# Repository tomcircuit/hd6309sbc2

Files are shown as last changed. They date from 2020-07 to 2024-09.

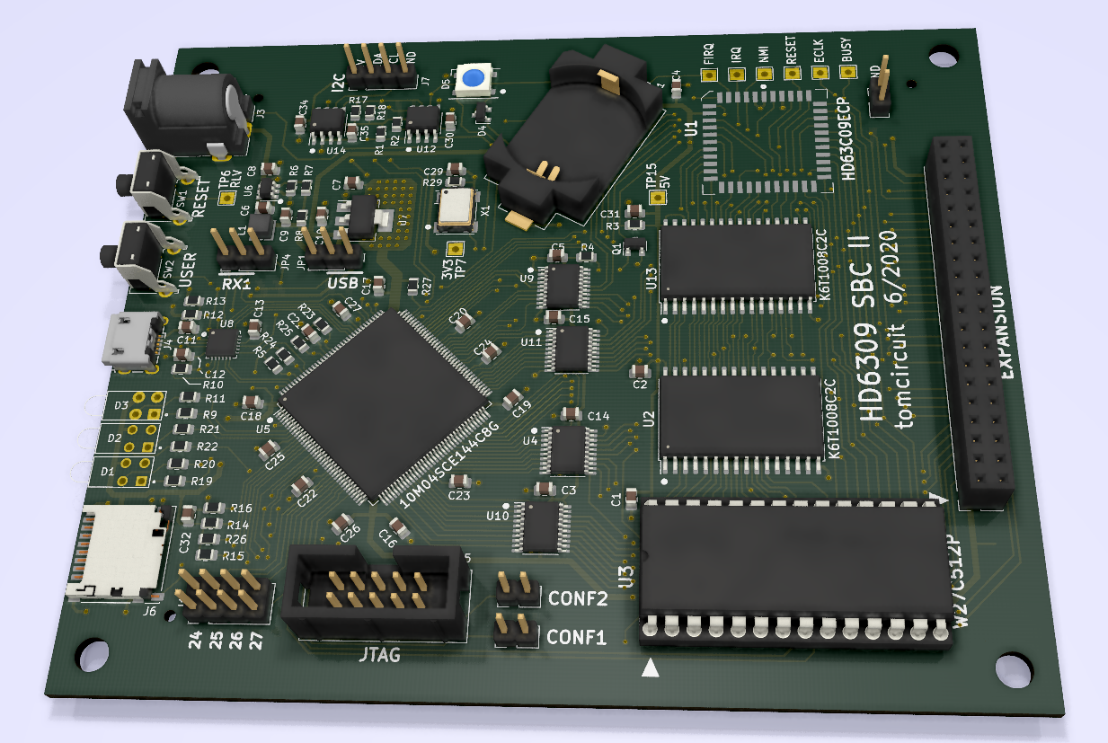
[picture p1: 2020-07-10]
media/pcb_3d_render_rt.PNG

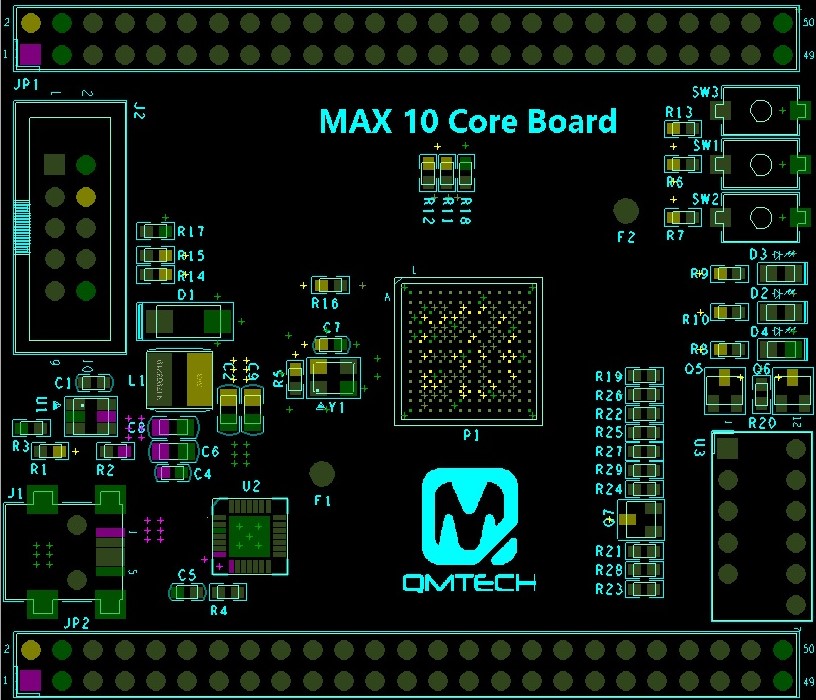
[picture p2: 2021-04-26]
reference/coreboard_cropped.jpg

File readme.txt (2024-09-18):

This information pertains to the HD6309 Singleboard Computer v2.0

The HD6309 SBC II is a retroputing distraction, motivated by the fun I had designing
and using my first HD6309 SBC project. This time around, I favored 'all mod cons' over
'old skool'. In contrast to the v1.0, this version loses the Zilog SCC and Zilog CIO
devices, expands RAM to 16MB and addressable ROM to 64K. The SD card interface is
retained, as is the more up-to-date I2C realtime clock. The heart of this SBC is an
Altera Cyclone IV FPGA, in which all of the glue logic and peripherals are implemented.
So, with vastly more logic capacity, easy to do UARTs, the SPI master, a more friendly
I2C master, a paged memory mapper, and whatever else springs to mind...  The 
'penalty' for this luxury is that of mixed voltage design - the CPU and clock signals 
are in a 5V domain, everything else is in the 3.3V domain. A 5V DC/DC supplies the
CPU. Four octal transceivers shift the TTL signalling to LV-TTL. Sure, I could have 
put the CPU core in the FPGA, but no CPU just seems a bit like 'cheating'.
LOL, to each their own :-)  The SBC v2 is also physically smaller than its v1.0 
predecessor; measures 100 x 120mm.

I devised a stacking 64-pin connector scheme so that the FPGA board, the CPU board,
and an I/O board can all be used together. I have also spec'd out a 65C816 CPU board,
and a MC68HC000 board.

Firmware wise, I'll keep the rudimentary monitor, NoICE support, and the ROM-resident 
6809 MICROSOFT BASIC interpreter which I implemented on v1.0 (the latter is courtesty 
of Grant Searle). 

More up-to-date information on the SBC can be found on the Hackaday project page:
https://hackaday.io/project/173401-hd6309-singleboard-computer-ii

This work is licensed under the Creative Commons Attribution-ShareAlike 4.0 International License. 
To view a copy of this license, visit http://creativecommons.org/licenses/by-sa/4.0/.

HD6309 Singleboard Computer II
Tom LeMense
9/17/2024

tomcircuit@gmail.com
@TomLeMense

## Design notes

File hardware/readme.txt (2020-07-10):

This set of design files implements the Schematic and PCB for the HD6309 Singleboard Computer II

Design tool is KiCad 5.1.6

PCB was designed with one-off production in mind, and to my own set of (largely unwritten) PCB
design rules. The board is double sided 100 x 120mm, with 8/8 track/spacing (mils), and 0.4mm minimum
hole size. The two most complicated components to solder are the EQPF144 MAX10 CPLD and the QFN28
CP2105 USB bridge. The rest of the components are fairly straightforward to assemble.

PDF of the PCB and Schematic can be found in the "plots" directory.
Gerber and drill information can be found in the "fabrication" directory.

My PCBs were fabricated by PCBway https://www.pcbway.com/ and I chose 1.6mm FR4 with ENIG surface 
treatment to make fine-pitch SMD soldering easier. I had a polyamide stencil manufactured by OSHstencils
https://www.oshstencils.com/. This will be my first foray with solder stencil, hotplate, and hot air
soldering. It's long overdue, because so many components simply cannot be reliably hand-soldered anymore.

More up-to-date information on the SBC can be found on the Hackaday project page:
https://hackaday.io/project/173401-hd6309-singleboard-computer-ii

This work is licensed under the Creative Commons Attribution-ShareAlike 4.0 International License. 
To view a copy of this license, visit http://creativecommons.org/licenses/by-sa/4.0/.

HD6309 Singleboard Computer II
Tom LeMense
7/8/2020

tomcircuit@gmail.com
@TomLeMense

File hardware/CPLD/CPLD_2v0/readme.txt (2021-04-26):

This set of design files implements the glue logic for the HD6309 Singleboard Computer 

CPLD VERSION v1.4

Target device is Altera EPM7128SLI in 84 pin PLCC
Development tool is Altera Quartus web edition v11

As present, all planned functions have been implemented:

. E & Q clock generation with 0WS, 1WS, and 3WS as necessary
. programmable 0WS/1WS for ROM area access
	---> note; 1WS is nasty, because this will slow down all the 6309 "idle" cycles, also!
		The power-on default is 1WS, in order to support slower EPROM devices at boot.
		
. SCC Ch A and Ch B baudrate clocks generated from 14.745 MHz oscillator
		
. Hardware SPI master* for SD card access

. [new 1.3] SPI clocks (fast and slow) derived only from 24 MHz oscillator

. [new 1.3] moved IO page to $E000-E1FF:
            $E000=CIO, $E010=SCC, $E020=RTC, $E030=SD_DATA, $E040=SYS, $E050=CFG, $E060=VER
		  $E070-$E1FF are undecoded space (for use by expansion card devices, for example)

. [new 1.3] selectable EPROM 27C128/27C256 support (pin 27 defaults to state of CONFIG jumper at RESET)

. [new 1.3] CPLD version "register" at $E060 - returns $13

. [new 1.3] removed test mux for TP11,12,13,14 pins - these are now fixed to echo SD card signals

. [new 1.4] removed RTC decode

. [new 1.4] implemented software I2C port at $E020, I2C SCK on pin 11 (new), I2C SDA on pin 12 (was RTCCS)

*Note that the hardware SPI was something that I found while casting about on the intarwebs.  
SimpleSPI_M.vhd is copyright 2007 by Tom Scott, of Mission Technologies
http://www.mission-technologies.org/read_article.php?subject=VHDL&id=14
It works well, and so I was happy to include it, with relatively minor changes, into my project.

More up-to-date information on the SBC can be found on the Hackaday project page:
https://hackaday.io/project/345-hd6309-singleboard-computer

This work is licensed under the Creative Commons Attribution-ShareAlike 4.0 International License. 
To view a copy of this license, visit http://creativecommons.org/licenses/by-sa/4.0/.

HD6309 Singleboard Computer (SBC)
Tom LeMense
1/28/2020

tomcircuit@gmail.com
@TomLeMense

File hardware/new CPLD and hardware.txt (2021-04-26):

HD6309 SBC Revision 2
---------------------

HD63C09E PLCC44
W27C512 64Kx8 FLASH  DIP28
K6T1008 128Kx8 SRAM (replace 2x 32Kx8 SRAM)  SOT32
CP2105 USB Bridge (replace FT230XS bridge)  QFN24
DS3231M (replace RTC7301 and DS3232M RTC retrofit)  SO8
add 24C64 EEPROM (on I2C chain)   SO8
6x LED (CHAtog, CHA/CHBtog)  PTH dual LED
WS2812B RGB LED   4-pin 5x5mm
CONF1 & 2 jumpers   2.54mm 1x2 header
write to VERSION SFR causes system reset
add 5V switching regulator  TPS560430  SOT23-6
replace PJRC SD card adapter with built-in SD card socket
replace USB B socket with USB MICRO B socket
replace MAX7000 with MAX10  (10M08SCC144)
remove X2 oscillator
remove CIO and SCC
5V domain for CPU, RAM, ROM
3.3V domain for MAX10, I2C, SD card 
AP1117-3.3 LDO for 3.3V rail
74LVC245 for 5V->3.3V level shifter

SN74LVC245APW (mouser 595-SN74LVC245APWR)
0.65mm pitch TSSOP-20 package

TPS560430 is a nice synchronous buck  (mouser 595-TPS560430YFDBVR)
10uH 1A RMS 1.8A sat current (2.1 MHz)  (mouser 810-VLS3012HBX-100M)
10uF/10V ceramic cap  (mouser 810-C2012X7R1A106KAE)
2.2uF/50V input cap (mouser 963-UMK212BB7225MG-T)
0.1uF/50V bootstrap cap (mouser 581-08055C104KAT4A)
R-divider

CP2105 USB-UART Bridge (mouser 634-CP2105-F01-GMR)
  The TXD toggle lights when a character is received from USB
  Test with CP2108 shows that RTS and CTS are able to be controlled by NoICE
  Note: RTS and DTR invert - from NoICE "RTS 1" drives the output LOW, and "RTS 0" drives the output HIGH.
DS3231M I2C Realtime Clock  (mouser 700-DS3231MZ/V+)
SD Card holder (mouser 798-DM3D-SF)

ROMA15 is HIGH at RESET (0x8000-0xFFFF ROM physical addr)
ROMA14 follows CONF at RESET (0x8000-0xBFFF or 0xC000-0xFFFF ROM physical addr)
RAMA13,14,15 follow A13,14,15 at RESET (no mapping)
RAMA16 is LOW at RESET (0x00000 - 0x0FFFF RAM physical addr)

MAX10 CPLD to support:

Clock generation (E,Q)
    with some ability to try to overclock the CPU?
    
Paged memory mapping of 256K RAM, 64K ROM
    8K x 32 pages of SRAM (p0-p31)
    8K x 8 pages of ROM (p32-p39)
    7b x 8 register file (6 bits page select, 1 bit write protect)    
    each 8K region of CPU space is mapped to p0-p39
        default: 
        R0=P8, R1=P9, R2,3,4,5=P10,11,12,13
        R6=P36/38, R7=P37/39 (depending on CONF1 jumper)
        
IO register  (SYSIO)
    4b LED3-6 control
    2b conf1, conf2
    1b pushbutton (debounced)
    
IRQ control / status  
    8b IRQ flag register (INTF)
        U1 TXRE request
        U1 RXF request
        U2 TXRE request
        U2 RXF request
		pushbutton request

    8b IRQ mask register (INTM)
        U1 TXRE mask
        U1 RXF mask
        U2 TXRE mask
        U2 RXF mask
        pushbutton mask
        
Two UARTs (one console, one NoICE)
    56,115,230,460kbps bitrates (with a VCP, does this really need to be the weird values?)
    each UART has 6b status/control register  (UxSCR)
    (2 bits baud select, 1 bit TX empty, 1 bit RX full, RTS status)
    each UART has 8b data register  (UxDATA)
    (send transmit data on write; received data on read)    
    
I2C master for RTC and EEPROM
    8b status/control register  (IICSCR)
    2 bit command field
    IDLE, MASTER, BYTE, and STOP commands
    2 bit SCL and SDA drive
    1 bit SDA level
    1 bit ACK send
    1 bit ACK receive
    1 bit I2C busy
    8b data register  (IICDATA)
    (send transmit data on write; received data on read)    
    
SPI master for SD Card
    8b status/control register   (SPISCR)
    1b clock select (fast/slow)
    1b SD switch input
    1b SD select output
    1b SPI busy
    1b WS control (to slow down E clock so that 6309 block move instruction can be used)
    8b data register  (SPIDATA)
    (send transmit data on write; received data on read)    
    
WS2812B interface
    R,G,B registers  (PIXR, PIXG, PIXB)
    
reset control  (RESCON)
    RTS1 reset   (00=RTS1 ignored; 01=RESET when RTS1 goes L, 10=when RTS1 goes H, 11=change of RTS1 state)
    RTS2 reset   (00=RTS2 ignored; 01=RESET when RTS1 goes L, 10=when RTS1 goes H, 11=change of RTS1 state)
    software reset  (1=RESET CPU)
    watchdog reset  (1=enable wdog; write to CPLD ID register to service watchdog)
    RTC select (0=perform RESET on RTC reset; 1=perform NMI on RTC reset)
    USER NMI enable (0=ignore USER button; 1=perform NMI on USER button)

$E004 - INTF
$E005 - INTM

$E010 - U2SCR
$E011 - U2DATA
$E012 - U1SCR
$E013 - U2DATA

$E020 - IICSCR
$E021 - IICDATA	

START:
         I2C_ReleaseBoth                            ; release SDA and SCL
         I2C_BitDelay                               ; allow SDA to float high
         I2C_SinkSDA                                ; begin I2C START by bringing SDA low first
         I2C_BitDelay                               ; half-bit delay
         I2C_SinkSCL                                ; complete I2C START by bringing SCL low
         I2C_BitDelay                               ; half-bit delay         

WRITE: 
"GO Master" 
    Start   ; I2C START is bringing SDA low first, then bit delay, then bring SCL low
    SendByte  ; byte is 8 bits from DATA_SEND, updating DATA_RCV, followed by sending ACK_SEND bit / updating ACK_RCV bit
"Send Byte"  ; byte is 8 bits from DATA_SEND, updating DATA_RCV, followed by sending ACK_SEND bit / updating ACK_RCV bit
"Send Byte"   ; byte is 8 bits from DATA_SEND, updating DATA_RCV, followed by sending ACK_SEND bit / updating ACK_RCV bit
"Send Stop" ; SCL high followed by SDA high is STOP condition

READ:
"GO Master" 
    Start   ; I2C START is bringing SDA low first, then bit delay, then bring SCL low
    SendByte  ; byte is 8 bits from DATA_SEND, updating DATA_RCV, followed by sending ACK_SEND bit / updating ACK_RCV bit
"Send Byte" ; byte is 8 bits from DATA_SEND, updating DATA_RCV, followed by sending ACK_SEND bit / updating ACK_RCV bit
"GO Master" 
    Start   ; I2C START is bringing SDA low first, then bit delay, then bring SCL low
    SendByte  ; byte is 8 bits from DATA_SEND, updating DATA_RCV, followed by sending ACK_SEND bit / updating ACK_RCV bit
"Rcv Byte"  ; byte is 8 bits from DATA_SEND, updating DATA_RCV, followed by sending ACK_SEND bit / updating ACK_RCV bit
"Send Stop"

"COMMAND" bits
00 = IDLE (no action when DATA_TX is written)
01 = BYTE (send DATA_SEND while updating DATA_RCV, followed by sending ACK_SEND / updating ACK_RCV)
10 = GO_MASTER (send START then fall into BYTE)
11 = STOP (send STOP condition, leaving SCL=SDA=1)

About the MAX 10 CPLD family
All IO pins have selectable pullups
All IO pins have optional open-drain output mode
All IO pins are INPUT until the device is configures

990824

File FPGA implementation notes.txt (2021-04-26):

PH1 minimal testboard setup
clock generation and CPU execution

1x M9K "RAM" at $0000...$03FF
1x M9K "ROM" at $FC00...$FFFF
DONE *address decoder
DONE *clock generator
*LED4 control at $E000
*PB1 status at $E001

1) das blinkenlights in ROM   
   --> exercises clock gen, address decoder, ROM, LED4
2) das blinkenlights that relocates to RAM
   --> exercises clock gen, address decoder, ROM, RAM, LED4

PH1.5 minimal testboard setup
clock generation and CPU execution

ACIA clock
ACIA 6850
PLL for ACIA
1x M9K "RAM" at $0000...$03FF
1x M9K "ROM" at $FC00...$FFFF
*address decoder
*clock generator
*LED4 control
*PB1 status
 
3) WOZMON in ROM
   --> exercises clock gen, address decoder, ROM, RAM, PLL, baudrate gen, ACIA

PH2 testboard setup       
bring in SRAM and SPI EEPROM

**ACIA_clock
**acia6850
**simple SPI to EEPROM
*PLL & baudrate_gen
4x M9K "ROM" at $F000...$FFFF
*address decoder
*clock generator
*SRAM interface
*LED4 & BUSY control
*PB1 status

1) RAM testing
   --> walking bit pattern through 64K of RAM
2) SPI EEPROM loader to RAM
   --> image of WOZMON in SPI EEPROM, "write protected" ROM
3) MSBASIC test run
   --> image of MSBASIC in SPI EEPROM 

PH3 testboard setup
more functionality and SBC1 compatibility.

**2xACIA_clock
**2xAcia6850
*simple SPI to EEPROM
*simple SPI to SDCARD
*2xTrap component
*Timer component
*PLL & baudrate_gen
4x M9K "ROM" at $F000...$FFFF
*address decoder
*clock generator
*DAT logic
*SRAM interface
*LED4 & BUSY control
*RTS status
*PB1 status
*IRQ control
*NMI control
*RESET control
*WS2812 control
*soft I2C control

1) DAT testing
   --> page testing
2) SPI SD CARD testing
   --> read/write SD card stuff
3) RTC testing
4) RGB LED testing
5) TRAP testing
6) TIMER testing
7) RESET and NMI testing
8) RTS testing
9) NoICE testing?

0xE000          [new]system timer preload/count  (use a 12b counter, only deal with upper 8 bits)
W = load preset count register
R = read down counter value
0xE001          [new]system timer control/status
bit 7 r/w IRQ
    write a 1 to enable terminal count interrupt, will INT when counter reaches 0
bit 0 r/w RUN
    write a 1 to start the counter, will read 1 as long as counter is running
    
0xE010          6850 A data register
0xE011          6850 A control/status register
0xE012          6850 B data register
0xE013          6850 B control/status register
0xE014          baudrate prescalar control (both A & B)
bit 7..4 n.u.
bit 3:2 r/w BPS
    00 = /1, 01 = /8, 02 = /24 for ACIA B
bit 1:0 r/w APS
    00 = /1, 01 = /8, 02 = /24 for ACIA A
    
0xE02x          Soft I2C register

0xE030          SD Card SPI Read/Write Data (triggers send)
0xE031          SD Card SPI Read Data (no send)
0xE032          SD Card SPI Control 
bit 7 r SDSW 
    sense the SD card present switch (1 = present)
bit 6 r SDBUSY 
    SPI interface is busy when 1
bit 5 r/w SDCLK 
    select CLK for SD CARD SPI (1 = XOSC/2 (25M), 0 = OSC/8 (6M))
bit 4 r/w SDCS 
    control CS line to SD CARD
bit 3..0 n.u.
    
0xE038          EEPROM SPI Read/Write Data (triggers send)
0xE039          EEPROM SPI Read Data (no send)
0xE03A          EEPROM SPI Control
vit 7 n.u.
bit 6 r SDBUSY 
    SPI interface is busy when 1
bit 5 r/w SDCLK 
    select CLK for EEPROM SPI (1 = XOSC/3 (16M), 0 = OSC/8 (6M))
bit 4 r/w SDCS 
    control CS line to EEPROM
bit 3..0 n.u.
    
0xE040          SYSTEM CONFIG register
bit 7 r/w WODAT
    enable WRITES to DAT 0-F registers at $FFF0-$FFFF when ROMSEH=1 (SWTPC compatibility)
bit 6 r/w BOOTROM
    4K of MAX10 UFM ROM is mapped into $F000-$FFFF when 1     
bit 3 r/w ROMBANK
    sets bank mapping of $C000-$FFFF when ROMSEL and/or ROMSEH are set. This takes the value of CONF1 at RESET
bit 2 r/w ROMSEH 
    disables DAT and prevent writes to $E200-$FFFF when 1, SRAM mapping depends on ROMBANK
bit 1 r/w ROMSEL 
    disables DAT and prevent writes to $C000-$DFFF when 1, SRAM mapping depends on ROMBANK
bit 0 n.u.
    
0xE048          NMI & RESET CONTROL register
bit 7 0/w COLD
    reset the CPU and MAX10 
bit 6 0/w WARM
    reset the CPU (but not the MAX10)
bit 5 r/w RTSEN
    enables CPU RESET from RTS when set
bit 4 r/w RTSPOL
    sets polarity of RTS that causes RESET
bit 3 r/w NMIPB
    enable NMI from pushbutton
bit 2..0 n.u.

0xE050          IO CONFIG register
bit 7 r CONF2
    CONF2 jumper status (1 = open, 0 = shorted)
bit 6 r CONF1 
    CONF1 jumper status (1 = open, 0 = shorted)
bit 5..4 n.u.    
bit 3 r PB pushbutton input (1 = pressed)
bit 2 r RTS 
    RTS state from CP2105
bit 1 r/w BUSY
    control BUSY LED #2 (1 = illuminate)
bit 0 r/w LED4
    control LED #4 (1 = illuminate)

0xE058          D4 RED register
0xE059          D4 GREEN register
0xE05A          D4 BLUE register
0xE05B          D5 RED register
0xE05C          D5 GREEN register
0xE05D          D5 BLUE register
0xE05E          D4/D5 update
bit 0 r/w UPDATE
    write 1 to update D4/D5 colors
    read 1 == busy, read 0 == ready

0xE06x          VERSION register
Read returns 0x20 (2.0)

0xE070-0xE07F   DAT A-F registers (read and write access)*
0xE080-0xE087   DAT C0,D0,E0,F0,C1,D1,E1,F1 registers (read and write access)*
*DAT A-F registers can also be WRITTEN via writes to 0xFFF0...0xFFFF when ROMSEH=1 and WODAT=1

0xE090-0xE097   TRAP1 registers
0xE098-0xE09F   TRAP2 registers

RAM and ROM Mapping
reads and writes within CPU 0x0000:DFFF are mapped to SRAM using DAT
(each 4K page has a DAT register, 
                               
    BOOTROM | ROMBANK | ROMSEH | ROMSEL | ADDRESS |    SRAM ADDR SOURCE
   ---------+---------+--------+--------+---------+---------- ----------              
       X    |    X    |    X   |   0    | $Cxxx   | use 'C' DAT                       
            |         |        |        | $Dxxx   | use 'D' DAT                       
       0    |    X    |    0   |   X    | $Exxx   | use 'E' DAT                       
            |         |        |        | $Fxxx   | use 'F' DAT                       
       X    |    0    |    X   |   1    | $Cxxx   | use 'C0' DAT                       
            |         |        |        | $Dxxx   | use 'D0' DAT                       
       0    |    0    |    1   |   X    | $Exxx   | use 'E0' DAT                       
            |         |        |        | $Fxxx   | use 'F0' DAT                       
       X    |    1    |    X   |   1    | $Cxxx   | use 'C1' DAT                       
            |         |        |        | $Dxxx   | use 'D1' DAT                       
       0    |    1    |    1   |   X    | $Exxx   | use 'E1' DAT                       
            |         |        |        | $Fxxx   | use 'F1' DAT                       
       1    |    X    |    X   |   X    | $Fxxx   | MAX10 UFM  
            |         |        |        |                                                               

ROMSEL == 0
reads and writes within CPU 0xC000:DFFF are mapped to SRAM using DAT

ROMSEL == 1
reads within CPU 0xC000:DFFF are mapped via DAT C0 and D0 when ROMBANK == 0 and DAT C1 and D1 when ROMBANK == 1
writes within CPU 0xC000:DFFF are blocked

ROMSEH == 0
reads and writes within CPU 0xE200:FFFF are mapped to SRAM using DAT

ROMSEH == 1
reads within CPU 0xE200:FFFF are mapped via DAT E0 and F0 when ROMBANK == 0 and DAT E1 and F1 when ROMBANK == 1
writes within CPU 0xFFF0:FFFF are mapped corresponding DAT register (0-F) when WODAT == 1, otherwise blocked
writes within CPU 0xE200:FFEF are blocked

BOOTROM
reads within CPU 0xF000:FFFF are mapped to MAX10 internal boot rom image
writes within CPU 0xF000:FFFF are blocked

UARTs

Use two acia6850 from John Kent System09 project.
These are MC6850 and need 16x/64x baud clocks (easy to modify to include 32x baud clock, also)

Need a prescalar (separate from acia6850 core) to provide /8 and /24 clocks, too.

Use a PLL to create the 14.7456MHz clock from the 50MHz xtal
This is nice because the acia6850 component can be used as-is
with the 16x and 64x (and add 32x) internal clock divider settings

	   PLL 		
	   14745600 32	460800
		        16	921600
		        64	230400
                
In addition, create a small PRESCALAR outside of the 6850 component to 
provide PLL/8 and a PLL/24 outputs to each of the two UARTs (independently)
                
    8	1843200	32	57600
        		16	115200
        		64	28800
  24	614400	32	19200
        		16	38400
        		64	9600

TIMER

another John Kent component - make it a longer counter so that we're counting CPU cycles and not 50 MHz cycles!
i.e. make it a 12b counter, only the uppermost 8b are visible to the CPU.

TRAP

another John Kent component - put two of these here for hardware breakpoints to IRQ (NMI?)

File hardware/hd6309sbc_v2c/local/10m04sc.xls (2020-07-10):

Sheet: Pin List E144
Pin Information for the Intel® MAX®10 10M04SC Device Version 2017.12.15 Note (1)
Bank Number | VREF | Pin Name/Function | Optional Function(s) | Configuration Function | Dedicated Tx/Rx Channel | Emulated LVDS Output Channel | IO Performance | E144 (2)
1A | VREFB1N0 | IO |  |  | DIFFIO_RX_L1n | DIFFOUT_L1n | Low_Speed | 6
1A | VREFB1N0 | IO |  |  | DIFFIO_RX_L1p | DIFFOUT_L1p | Low_Speed | 7
1A | VREFB1N0 | IO |  |  | DIFFIO_RX_L3n | DIFFOUT_L3n | Low_Speed | 8
1A | VREFB1N0 | IO |  |  | DIFFIO_RX_L3p | DIFFOUT_L3p | Low_Speed | 10
1A | VREFB1N0 | IO |  |  | DIFFIO_RX_L5n | DIFFOUT_L5n | Low_Speed | 11
1A | VREFB1N0 | IO |  |  | DIFFIO_RX_L5p | DIFFOUT_L5p | Low_Speed | 12
1A | VREFB1N0 | IO |  |  | DIFFIO_RX_L7n | DIFFOUT_L7n | Low_Speed | 13
1A | VREFB1N0 | IO |  |  | DIFFIO_RX_L7p | DIFFOUT_L7p | Low_Speed | 14
1B | VREFB1N0 | IO |  | JTAGEN |  |  |  | 15
1B | VREFB1N0 | IO |  | TMS | DIFFIO_RX_L11n | DIFFOUT_L11n | Low_Speed | 16
1B | VREFB1N0 | IO | VREFB1N0 |  |  |  |  | 17
1B | VREFB1N0 | IO |  | TCK | DIFFIO_RX_L11p | DIFFOUT_L11p | Low_Speed | 18
1B | VREFB1N0 | IO |  | TDI | DIFFIO_RX_L12n | DIFFOUT_L12n | Low_Speed | 19
1B | VREFB1N0 | IO |  | TDO | DIFFIO_RX_L12p | DIFFOUT_L12p | Low_Speed | 20
1B | VREFB1N0 | IO |  |  | DIFFIO_RX_L14n | DIFFOUT_L14n | Low_Speed | 21
1B | VREFB1N0 | IO |  |  | DIFFIO_RX_L14p | DIFFOUT_L14p | Low_Speed | 22
1B | VREFB1N0 | IO |  |  | DIFFIO_RX_L16n | DIFFOUT_L16n | Low_Speed | 24
1B | VREFB1N0 | IO |  |  | DIFFIO_RX_L16p | DIFFOUT_L16p | Low_Speed | 25
2 | VREFB2N0 | IO | CLK0n |  | DIFFIO_RX_L18n | DIFFOUT_L18n | High_Speed | 26
2 | VREFB2N0 | IO | CLK0p |  | DIFFIO_RX_L18p | DIFFOUT_L18p | High_Speed | 27
2 | VREFB2N0 | IO | CLK1n |  | DIFFIO_RX_L20n | DIFFOUT_L20n | High_Speed | 28
2 | VREFB2N0 | IO | CLK1p |  | DIFFIO_RX_L20p | DIFFOUT_L20p | High_Speed | 29
2 | VREFB2N0 | IO | VREFB2N0 |  |  |  |  | 30
2 | VREFB2N0 | IO | PLL_L_CLKOUTn |  | DIFFIO_RX_L27n | DIFFOUT_L27n | High_Speed | 32
2 | VREFB2N0 | IO | PLL_L_CLKOUTp |  | DIFFIO_RX_L27p | DIFFOUT_L27p | High_Speed | 33
3 | VREFB3N0 | IO |  |  | DIFFIO_TX_RX_B1n | DIFFOUT_B1n | High_Speed | 38
3 | VREFB3N0 | IO |  |  | DIFFIO_TX_RX_B1p | DIFFOUT_B1p | High_Speed | 39
3 | VREFB3N0 | IO |  |  | DIFFIO_TX_RX_B3n | DIFFOUT_B3n | High_Speed | 41
3 | VREFB3N0 | IO |  |  | DIFFIO_TX_RX_B3p | DIFFOUT_B3p | High_Speed | 43
3 | VREFB3N0 | IO |  |  | DIFFIO_TX_RX_B5n | DIFFOUT_B5n | High_Speed | 44
3 | VREFB3N0 | IO |  |  | DIFFIO_TX_RX_B5p | DIFFOUT_B5p | High_Speed | 45
3 | VREFB3N0 | IO |  |  | DIFFIO_TX_RX_B7n | DIFFOUT_B7n | High_Speed | 46
3 | VREFB3N0 | IO |  |  | DIFFIO_TX_RX_B7p | DIFFOUT_B7p | High_Speed | 47
3 | VREFB3N0 | IO |  |  | DIFFIO_TX_RX_B9n | DIFFOUT_B9n | High_Speed | 50
3 | VREFB3N0 | IO | VREFB3N0 |  |  |  |  | 48
3 | VREFB3N0 | IO |  |  | DIFFIO_TX_RX_B9p | DIFFOUT_B9p | High_Speed | 52
3 | VREFB3N0 | IO |  |  |  |  |  | 54
3 | VREFB3N0 | IO |  |  | DIFFIO_TX_RX_B12n | DIFFOUT_B12n | High_Speed | 55
3 | VREFB3N0 | IO |  |  | DIFFIO_TX_RX_B12p | DIFFOUT_B12p | High_Speed | 56
3 | VREFB3N0 | IO |  |  | DIFFIO_TX_RX_B14n | DIFFOUT_B14n | High_Speed | 57
3 | VREFB3N0 | IO |  |  | DIFFIO_TX_RX_B14p | DIFFOUT_B14p | High_Speed | 58
3 | VREFB3N0 | IO |  |  | DIFFIO_TX_RX_B16n | DIFFOUT_B16n | High_Speed | 59
3 | VREFB3N0 | IO |  |  | DIFFIO_TX_RX_B16p | DIFFOUT_B16p | High_Speed | 60
4 | VREFB4N0 | IO | VREFB4N0 |  |  |  |  | 61
4 | VREFB4N0 | IO |  |  |  |  |  | 62
4 | VREFB4N0 | IO |  |  | DIFFIO_TX_RX_B23n | DIFFOUT_B23n | High_Speed | 64
4 | VREFB4N0 | IO |  |  | DIFFIO_TX_RX_B23p | DIFFOUT_B23p | High_Speed | 65
4 | VREFB4N0 | IO |  |  |  |  |  | 66
4 | VREFB4N0 | IO |  |  | DIFFIO_TX_RX_B27n | DIFFOUT_B27n | High_Speed | 69
4 | VREFB4N0 | IO |  |  | DIFFIO_TX_RX_B27p | DIFFOUT_B27p | High_Speed | 70
5 | VREFB5N0 | IO |  |  | DIFFIO_RX_R1p | DIFFOUT_R1p | High_Speed | 75
5 | VREFB5N0 | IO |  |  | DIFFIO_RX_R2p | DIFFOUT_R2p | High_Speed | 74
5 | VREFB5N0 | IO |  |  | DIFFIO_RX_R1n | DIFFOUT_R1n | High_Speed | 77
5 | VREFB5N0 | IO |  |  | DIFFIO_RX_R2n | DIFFOUT_R2n | High_Speed | 76
5 | VREFB5N0 | IO |  |  | DIFFIO_RX_R7p | DIFFOUT_R7p | High_Speed | 79
5 | VREFB5N0 | IO |  |  |  |  |  | 78
5 | VREFB5N0 | IO |  |  | DIFFIO_RX_R7n | DIFFOUT_R7n | High_Speed | 81
5 | VREFB5N0 | IO | VREFB5N0 |  |  |  |  | 80
5 | VREFB5N0 | IO |  |  | DIFFIO_RX_R10p | DIFFOUT_R10p | High_Speed | 85
5 | VREFB5N0 | IO |  |  | DIFFIO_RX_R11p | DIFFOUT_R11p | High_Speed | 84
5 | VREFB5N0 | IO |  |  | DIFFIO_RX_R10n | DIFFOUT_R10n | High_Speed | 87
5 | VREFB5N0 | IO |  |  | DIFFIO_RX_R11n | DIFFOUT_R11n | High_Speed | 86
6 | VREFB6N0 | IO | CLK2p |  | DIFFIO_RX_R14p | DIFFOUT_R14p | High_Speed | 88
6 | VREFB6N0 | IO | CLK2n |  | DIFFIO_RX_R14n | DIFFOUT_R14n | High_Speed | 89
6 | VREFB6N0 | IO | CLK3p |  | DIFFIO_RX_R16p | DIFFOUT_R16p | High_Speed | 90
6 | VREFB6N0 | IO | CLK3n |  | DIFFIO_RX_R16n | DIFFOUT_R16n | High_Speed | 91
6 | VREFB6N0 | IO |  |  | DIFFIO_RX_R18p | DIFFOUT_R18p | High_Speed | 92
6 | VREFB6N0 | IO |  |  | DIFFIO_RX_R18n | DIFFOUT_R18n | High_Speed | 93
6 | VREFB6N0 | IO | DPCLK3 |  | DIFFIO_RX_R26p | DIFFOUT_R26p | High_Speed | 96
6 | VREFB6N0 | IO | VREFB6N0 |  |  |  |  | 97
6 | VREFB6N0 | IO | DPCLK2 |  | DIFFIO_RX_R26n | DIFFOUT_R26n | High_Speed | 98
6 | VREFB6N0 | IO |  |  | DIFFIO_RX_R27p | DIFFOUT_R27p | High_Speed | 99
6 | VREFB6N0 | IO |  |  | DIFFIO_RX_R28p | DIFFOUT_R28p | High_Speed | 100
6 | VREFB6N0 | IO |  |  | DIFFIO_RX_R27n | DIFFOUT_R27n | High_Speed | 101
6 | VREFB6N0 | IO |  |  | DIFFIO_RX_R28n | DIFFOUT_R28n | High_Speed | 102
6 | VREFB6N0 | IO |  |  | DIFFIO_RX_R33p | DIFFOUT_R33p | High_Speed | 105
6 | VREFB6N0 | IO |  |  | DIFFIO_RX_R33n | DIFFOUT_R33n | High_Speed | 106
7 | VREFB7N0 | IO |  |  | DIFFIO_RX_T1p | DIFFOUT_T1p | High_Speed | 110
7 | VREFB7N0 | IO |  |  | DIFFIO_RX_T1n | DIFFOUT_T1n | High_Speed | 111
7 | VREFB7N0 | IO | VREFB7N0 |  |  |  |  | 112
7 | VREFB7N0 | IO |  |  |  |  |  | 113
7 | VREFB7N0 | IO |  |  |  |  |  | 114
7 | VREFB7N0 | IO |  |  | DIFFIO_RX_T10p | DIFFOUT_T10p | High_Speed | 118
7 | VREFB7N0 | IO |  |  | DIFFIO_RX_T10n | DIFFOUT_T10n | High_Speed | 119
8 | VREFB8N0 | IO |  |  | DIFFIO_RX_T16p | DIFFOUT_T16p | Low_Speed | 120
8 | VREFB8N0 | IO |  | DEV_CLRn | DIFFIO_RX_T16n | DIFFOUT_T16n | Low_Speed | 121
8 | VREFB8N0 | IO |  | DEV_OE |  |  |  | 122
8 | VREFB8N0 | IO | VREFB8N0 |  |  |  |  | 123
8 | VREFB8N0 | IO |  | CONFIG_SEL |  |  |  | 126
8 | VREFB8N0 | IO |  |  | DIFFIO_RX_T19p | DIFFOUT_T19p | Low_Speed | 124
8 | VREFB8N0 | Input_only |  | nCONFIG |  |  |  | 129
8 | VREFB8N0 | IO |  |  | DIFFIO_RX_T19n | DIFFOUT_T19n | Low_Speed | 127
8 | VREFB8N0 | IO |  |  | DIFFIO_RX_T20p | DIFFOUT_T20p | Low_Speed | 130
8 | VREFB8N0 | IO |  |  | DIFFIO_RX_T20n | DIFFOUT_T20n | Low_Speed | 131
8 | VREFB8N0 | IO |  |  | DIFFIO_RX_T22p | DIFFOUT_T22p | Low_Speed | 132
8 | VREFB8N0 | IO |  | CRC_ERROR | DIFFIO_RX_T22n | DIFFOUT_T22n | Low_Speed | 134
8 | VREFB8N0 | IO |  |  |  |  |  | 135
8 | VREFB8N0 | IO |  | nSTATUS | DIFFIO_RX_T24p | DIFFOUT_T24p | Low_Speed | 136
8 | VREFB8N0 | IO |  | CONF_DONE | DIFFIO_RX_T24n | DIFFOUT_T24n | Low_Speed | 138
8 | VREFB8N0 | IO |  |  | DIFFIO_RX_T26p | DIFFOUT_T26p | Low_Speed | 140
8 | VREFB8N0 | IO |  |  | DIFFIO_RX_T26n | DIFFOUT_T26n | Low_Speed | 141
 |  | GND |  |  |  |  |  | 3
 |  | GND |  |  |  |  |  | 4
 |  | GND |  |  |  |  |  | 95
 |  | GND |  |  |  |  |  | 83
 |  | GND |  |  |  |  |  | 68
 |  | GND |  |  |  |  |  | 63
 |  | GND |  |  |  |  |  | 53
 |  | GND |  |  |  |  |  | 42
 |  | GND |  |  |  |  |  | 142
 |  | GND |  |  |  |  |  | 137
 |  | GND |  |  |  |  |  | 133
 |  | GND |  |  |  |  |  | 125
 |  | GND |  |  |  |  |  | 116
 |  | GND |  |  |  |  |  | 104
 |  | VCCIO1A |  |  |  |  |  | 9
 |  | VCCIO1B |  |  |  |  |  | 23
 |  | VCCIO2 |  |  |  |  |  | 31
 |  | VCCIO3 |  |  |  |  |  | 49
 |  | VCCIO3 |  |  |  |  |  | 40
 |  | VCCIO4 |  |  |  |  |  | 67
 |  | VCCIO5 |  |  |  |  |  | 82
 |  | VCCIO6 |  |  |  |  |  | 94
 |  | VCCIO6 |  |  |  |  |  | 103
 |  | VCCIO7 |  |  |  |  |  | 117
 |  | VCCIO8 |  |  |  |  |  | 139
 |  | VCCIO8 |  |  |  |  |  | 128
 |  | VCCA1 |  |  |  |  |  | 35
 |  | VCCA2 |  |  |  |  |  | 34
 |  | VCCA3 |  |  |  |  |  | 5
 |  | VCCA3 |  |  |  |  |  | 107
 |  | VCCA4 |  |  |  |  |  | 143
 |  | VCCA5 |  |  |  |  |  | 71
 |  | VCCA6 |  |  |  |  |  | 2
 |  | VCC_ONE |  |  |  |  |  | 73
 |  | VCC_ONE |  |  |  |  |  | 72
 |  | VCC_ONE |  |  |  |  |  | 51
 |  | VCC_ONE |  |  |  |  |  | 37
 |  | VCC_ONE |  |  |  |  |  | 36
 |  | VCC_ONE |  |  |  |  |  | 144
 |  | VCC_ONE |  |  |  |  |  | 115
 |  | VCC_ONE |  |  |  |  |  | 109
 |  | VCC_ONE |  |  |  |  |  | 108
 |  | VCC_ONE |  |  |  |  |  | 1
Notes:
(1) For more information about pin definition and pin connection guidelines, refer to the
Intel MAX 10 FPGA Device Family Pin Connection Guidelines. (http://www.altera.com/literature/dp/max-10/PCG-01018.pdf)
(2) The E144-pin package has an exposed ground pad at the bottom of the package. The exposed ground pad is used for electrical connectivity and not for thermal purposes. You must connect the exposed ground pad to the ground plane of the PCB.
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

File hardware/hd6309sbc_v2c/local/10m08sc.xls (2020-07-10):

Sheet: Pin List E144
Pin Information for the Intel® MAX®10 10M08SC Device Version 2017.12.15 Note (1)
Bank Number | VREF | Pin Name/Function | Optional Function(s) | Configuration Function | Dedicated Tx/Rx Channel | Emulated LVDS Output Channel | IO Performance | E144 (2)
1A | VREFB1N0 | IO |  |  | DIFFIO_RX_L1n | DIFFOUT_L1n | Low_Speed | 6
1A | VREFB1N0 | IO |  |  | DIFFIO_RX_L1p | DIFFOUT_L1p | Low_Speed | 7
1A | VREFB1N0 | IO |  |  | DIFFIO_RX_L3n | DIFFOUT_L3n | Low_Speed | 8
1A | VREFB1N0 | IO |  |  | DIFFIO_RX_L3p | DIFFOUT_L3p | Low_Speed | 10
1A | VREFB1N0 | IO |  |  | DIFFIO_RX_L5n | DIFFOUT_L5n | Low_Speed | 11
1A | VREFB1N0 | IO |  |  | DIFFIO_RX_L5p | DIFFOUT_L5p | Low_Speed | 12
1A | VREFB1N0 | IO |  |  | DIFFIO_RX_L7n | DIFFOUT_L7n | Low_Speed | 13
1A | VREFB1N0 | IO |  |  | DIFFIO_RX_L7p | DIFFOUT_L7p | Low_Speed | 14
1B | VREFB1N0 | IO |  | JTAGEN |  |  |  | 15
1B | VREFB1N0 | IO |  | TMS | DIFFIO_RX_L11n | DIFFOUT_L11n | Low_Speed | 16
1B | VREFB1N0 | IO | VREFB1N0 |  |  |  |  | 17
1B | VREFB1N0 | IO |  | TCK | DIFFIO_RX_L11p | DIFFOUT_L11p | Low_Speed | 18
1B | VREFB1N0 | IO |  | TDI | DIFFIO_RX_L12n | DIFFOUT_L12n | Low_Speed | 19
1B | VREFB1N0 | IO |  | TDO | DIFFIO_RX_L12p | DIFFOUT_L12p | Low_Speed | 20
1B | VREFB1N0 | IO |  |  | DIFFIO_RX_L14n | DIFFOUT_L14n | Low_Speed | 21
1B | VREFB1N0 | IO |  |  | DIFFIO_RX_L14p | DIFFOUT_L14p | Low_Speed | 22
1B | VREFB1N0 | IO |  |  | DIFFIO_RX_L16n | DIFFOUT_L16n | Low_Speed | 24
1B | VREFB1N0 | IO |  |  | DIFFIO_RX_L16p | DIFFOUT_L16p | Low_Speed | 25
2 | VREFB2N0 | IO | CLK0n |  | DIFFIO_RX_L18n | DIFFOUT_L18n | High_Speed | 26
2 | VREFB2N0 | IO | CLK0p |  | DIFFIO_RX_L18p | DIFFOUT_L18p | High_Speed | 27
2 | VREFB2N0 | IO | CLK1n |  | DIFFIO_RX_L20n | DIFFOUT_L20n | High_Speed | 28
2 | VREFB2N0 | IO | CLK1p |  | DIFFIO_RX_L20p | DIFFOUT_L20p | High_Speed | 29
2 | VREFB2N0 | IO | VREFB2N0 |  |  |  |  | 30
2 | VREFB2N0 | IO | PLL_L_CLKOUTn |  | DIFFIO_RX_L27n | DIFFOUT_L27n | High_Speed | 32
2 | VREFB2N0 | IO | PLL_L_CLKOUTp |  | DIFFIO_RX_L27p | DIFFOUT_L27p | High_Speed | 33
3 | VREFB3N0 | IO |  |  | DIFFIO_TX_RX_B1n | DIFFOUT_B1n | High_Speed | 38
3 | VREFB3N0 | IO |  |  | DIFFIO_TX_RX_B1p | DIFFOUT_B1p | High_Speed | 39
3 | VREFB3N0 | IO |  |  | DIFFIO_TX_RX_B3n | DIFFOUT_B3n | High_Speed | 41
3 | VREFB3N0 | IO |  |  | DIFFIO_TX_RX_B3p | DIFFOUT_B3p | High_Speed | 43
3 | VREFB3N0 | IO |  |  | DIFFIO_TX_RX_B5n | DIFFOUT_B5n | High_Speed | 44
3 | VREFB3N0 | IO |  |  | DIFFIO_TX_RX_B5p | DIFFOUT_B5p | High_Speed | 45
3 | VREFB3N0 | IO |  |  | DIFFIO_TX_RX_B7n | DIFFOUT_B7n | High_Speed | 46
3 | VREFB3N0 | IO |  |  | DIFFIO_TX_RX_B7p | DIFFOUT_B7p | High_Speed | 47
3 | VREFB3N0 | IO |  |  | DIFFIO_TX_RX_B9n | DIFFOUT_B9n | High_Speed | 50
3 | VREFB3N0 | IO | VREFB3N0 |  |  |  |  | 48
3 | VREFB3N0 | IO |  |  | DIFFIO_TX_RX_B9p | DIFFOUT_B9p | High_Speed | 52
3 | VREFB3N0 | IO |  |  |  |  |  | 54
3 | VREFB3N0 | IO |  |  | DIFFIO_TX_RX_B12n | DIFFOUT_B12n | High_Speed | 55
3 | VREFB3N0 | IO |  |  | DIFFIO_TX_RX_B12p | DIFFOUT_B12p | High_Speed | 56
3 | VREFB3N0 | IO |  |  | DIFFIO_TX_RX_B14n | DIFFOUT_B14n | High_Speed | 57
3 | VREFB3N0 | IO |  |  | DIFFIO_TX_RX_B14p | DIFFOUT_B14p | High_Speed | 58
3 | VREFB3N0 | IO |  |  | DIFFIO_TX_RX_B16n | DIFFOUT_B16n | High_Speed | 59
3 | VREFB3N0 | IO |  |  | DIFFIO_TX_RX_B16p | DIFFOUT_B16p | High_Speed | 60
4 | VREFB4N0 | IO | VREFB4N0 |  |  |  |  | 61
4 | VREFB4N0 | IO |  |  |  |  |  | 62
4 | VREFB4N0 | IO |  |  | DIFFIO_TX_RX_B23n | DIFFOUT_B23n | High_Speed | 64
4 | VREFB4N0 | IO |  |  | DIFFIO_TX_RX_B23p | DIFFOUT_B23p | High_Speed | 65
4 | VREFB4N0 | IO |  |  |  |  |  | 66
4 | VREFB4N0 | IO |  |  | DIFFIO_TX_RX_B27n | DIFFOUT_B27n | High_Speed | 69
4 | VREFB4N0 | IO |  |  | DIFFIO_TX_RX_B27p | DIFFOUT_B27p | High_Speed | 70
5 | VREFB5N0 | IO |  |  | DIFFIO_RX_R1p | DIFFOUT_R1p | High_Speed | 75
5 | VREFB5N0 | IO |  |  | DIFFIO_RX_R2p | DIFFOUT_R2p | High_Speed | 74
5 | VREFB5N0 | IO |  |  | DIFFIO_RX_R1n | DIFFOUT_R1n | High_Speed | 77
5 | VREFB5N0 | IO |  |  | DIFFIO_RX_R2n | DIFFOUT_R2n | High_Speed | 76
5 | VREFB5N0 | IO |  |  | DIFFIO_RX_R7p | DIFFOUT_R7p | High_Speed | 79
5 | VREFB5N0 | IO |  |  |  |  |  | 78
5 | VREFB5N0 | IO |  |  | DIFFIO_RX_R7n | DIFFOUT_R7n | High_Speed | 81
5 | VREFB5N0 | IO | VREFB5N0 |  |  |  |  | 80
5 | VREFB5N0 | IO |  |  | DIFFIO_RX_R10p | DIFFOUT_R10p | High_Speed | 85
5 | VREFB5N0 | IO |  |  | DIFFIO_RX_R11p | DIFFOUT_R11p | High_Speed | 84
5 | VREFB5N0 | IO |  |  | DIFFIO_RX_R10n | DIFFOUT_R10n | High_Speed | 87
5 | VREFB5N0 | IO |  |  | DIFFIO_RX_R11n | DIFFOUT_R11n | High_Speed | 86
6 | VREFB6N0 | IO | CLK2p |  | DIFFIO_RX_R14p | DIFFOUT_R14p | High_Speed | 88
6 | VREFB6N0 | IO | CLK2n |  | DIFFIO_RX_R14n | DIFFOUT_R14n | High_Speed | 89
6 | VREFB6N0 | IO | CLK3p |  | DIFFIO_RX_R16p | DIFFOUT_R16p | High_Speed | 90
6 | VREFB6N0 | IO | CLK3n |  | DIFFIO_RX_R16n | DIFFOUT_R16n | High_Speed | 91
6 | VREFB6N0 | IO |  |  | DIFFIO_RX_R18p | DIFFOUT_R18p | High_Speed | 92
6 | VREFB6N0 | IO |  |  | DIFFIO_RX_R18n | DIFFOUT_R18n | High_Speed | 93
6 | VREFB6N0 | IO | DPCLK3 |  | DIFFIO_RX_R26p | DIFFOUT_R26p | High_Speed | 96
6 | VREFB6N0 | IO | VREFB6N0 |  |  |  |  | 97
6 | VREFB6N0 | IO | DPCLK2 |  | DIFFIO_RX_R26n | DIFFOUT_R26n | High_Speed | 98
6 | VREFB6N0 | IO |  |  | DIFFIO_RX_R27p | DIFFOUT_R27p | High_Speed | 99
6 | VREFB6N0 | IO |  |  | DIFFIO_RX_R28p | DIFFOUT_R28p | High_Speed | 100
6 | VREFB6N0 | IO |  |  | DIFFIO_RX_R27n | DIFFOUT_R27n | High_Speed | 101
6 | VREFB6N0 | IO |  |  | DIFFIO_RX_R28n | DIFFOUT_R28n | High_Speed | 102
6 | VREFB6N0 | IO |  |  | DIFFIO_RX_R33p | DIFFOUT_R33p | High_Speed | 105
6 | VREFB6N0 | IO |  |  | DIFFIO_RX_R33n | DIFFOUT_R33n | High_Speed | 106
7 | VREFB7N0 | IO |  |  | DIFFIO_RX_T1p | DIFFOUT_T1p | High_Speed | 110
7 | VREFB7N0 | IO |  |  | DIFFIO_RX_T1n | DIFFOUT_T1n | High_Speed | 111
7 | VREFB7N0 | IO | VREFB7N0 |  |  |  |  | 112
7 | VREFB7N0 | IO |  |  |  |  |  | 113
7 | VREFB7N0 | IO |  |  |  |  |  | 114
7 | VREFB7N0 | IO |  |  | DIFFIO_RX_T10p | DIFFOUT_T10p | High_Speed | 118
7 | VREFB7N0 | IO |  |  | DIFFIO_RX_T10n | DIFFOUT_T10n | High_Speed | 119
8 | VREFB8N0 | IO |  |  | DIFFIO_RX_T16p | DIFFOUT_T16p | Low_Speed | 120
8 | VREFB8N0 | IO |  | DEV_CLRn | DIFFIO_RX_T16n | DIFFOUT_T16n | Low_Speed | 121
8 | VREFB8N0 | IO |  | DEV_OE |  |  |  | 122
8 | VREFB8N0 | IO | VREFB8N0 |  |  |  |  | 123
8 | VREFB8N0 | IO |  | CONFIG_SEL |  |  |  | 126
8 | VREFB8N0 | IO |  |  | DIFFIO_RX_T19p | DIFFOUT_T19p | Low_Speed | 124
8 | VREFB8N0 | Input_only |  | nCONFIG |  |  |  | 129
8 | VREFB8N0 | IO |  |  | DIFFIO_RX_T19n | DIFFOUT_T19n | Low_Speed | 127
8 | VREFB8N0 | IO |  |  | DIFFIO_RX_T20p | DIFFOUT_T20p | Low_Speed | 130
8 | VREFB8N0 | IO |  |  | DIFFIO_RX_T20n | DIFFOUT_T20n | Low_Speed | 131
8 | VREFB8N0 | IO |  |  | DIFFIO_RX_T22p | DIFFOUT_T22p | Low_Speed | 132
8 | VREFB8N0 | IO |  | CRC_ERROR | DIFFIO_RX_T22n | DIFFOUT_T22n | Low_Speed | 134
8 | VREFB8N0 | IO |  |  |  |  |  | 135
8 | VREFB8N0 | IO |  | nSTATUS | DIFFIO_RX_T24p | DIFFOUT_T24p | Low_Speed | 136
8 | VREFB8N0 | IO |  | CONF_DONE | DIFFIO_RX_T24n | DIFFOUT_T24n | Low_Speed | 138
8 | VREFB8N0 | IO |  |  | DIFFIO_RX_T26p | DIFFOUT_T26p | Low_Speed | 140
8 | VREFB8N0 | IO |  |  | DIFFIO_RX_T26n | DIFFOUT_T26n | Low_Speed | 141
 |  | GND |  |  |  |  |  | 3
 |  | GND |  |  |  |  |  | 4
 |  | GND |  |  |  |  |  | 95
 |  | GND |  |  |  |  |  | 83
 |  | GND |  |  |  |  |  | 68
 |  | GND |  |  |  |  |  | 63
 |  | GND |  |  |  |  |  | 53
 |  | GND |  |  |  |  |  | 42
 |  | GND |  |  |  |  |  | 142
 |  | GND |  |  |  |  |  | 137
 |  | GND |  |  |  |  |  | 133
 |  | GND |  |  |  |  |  | 125
 |  | GND |  |  |  |  |  | 116
 |  | GND |  |  |  |  |  | 104
 |  | VCCIO1A |  |  |  |  |  | 9
 |  | VCCIO1B |  |  |  |  |  | 23
 |  | VCCIO2 |  |  |  |  |  | 31
 |  | VCCIO3 |  |  |  |  |  | 49
 |  | VCCIO3 |  |  |  |  |  | 40
 |  | VCCIO4 |  |  |  |  |  | 67
 |  | VCCIO5 |  |  |  |  |  | 82
 |  | VCCIO6 |  |  |  |  |  | 94
 |  | VCCIO6 |  |  |  |  |  | 103
 |  | VCCIO7 |  |  |  |  |  | 117
 |  | VCCIO8 |  |  |  |  |  | 139
 |  | VCCIO8 |  |  |  |  |  | 128
 |  | VCCA1 |  |  |  |  |  | 35
 |  | VCCA2 |  |  |  |  |  | 34
 |  | VCCA3 |  |  |  |  |  | 5
 |  | VCCA3 |  |  |  |  |  | 107
 |  | VCCA4 |  |  |  |  |  | 143
 |  | VCCA5 |  |  |  |  |  | 71
 |  | VCCA6 |  |  |  |  |  | 2
 |  | VCC_ONE |  |  |  |  |  | 73
 |  | VCC_ONE |  |  |  |  |  | 72
 |  | VCC_ONE |  |  |  |  |  | 51
 |  | VCC_ONE |  |  |  |  |  | 37
 |  | VCC_ONE |  |  |  |  |  | 36
 |  | VCC_ONE |  |  |  |  |  | 144
 |  | VCC_ONE |  |  |  |  |  | 115
 |  | VCC_ONE |  |  |  |  |  | 109
 |  | VCC_ONE |  |  |  |  |  | 108
 |  | VCC_ONE |  |  |  |  |  | 1
Notes:
(1) For more information about pin definition and pin connection guidelines, refer to the
Intel MAX 10 FPGA Device Family Pin Connection Guidelines. (http://www.altera.com/literature/dp/max-10/PCG-01018.pdf)
(2) The E144-pin package has an exposed ground pad at the bottom of the package. The exposed ground pad is used for electrical connectivity and not for thermal purposes. You must connect the exposed ground pad to the ground plane of the PCB.
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

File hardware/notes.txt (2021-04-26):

SOP32 supports up to 512KB SRAM
pins 1,30 are A18 and A17, respectively, on AS6C4008 SRAM
--> this hw could have supported 1MB of SRAM
--> still could if two Tx pins are stolen and connected to pins 1,30 of the two SRAM chips

NitrOS needs 2MB of RAM for current version
--> expansion card with 2MB of SRAM and decoding
--> need provision in the FPGA to disable main RAM decoding (put into a soft SFR - RAMEN)

In retrospect, it would be cleaner to generate MA13..MA20 with a 74HC574, fed by LV DBUS
--> during non SFR access, put MA13...MA20 onto LV_D0..LV_D7 and clock into HC574
--> do this quickly (in 50 MHz FPGA clock domain) and well BEFORE WR# signal is asserted!

It would be cool to have the FLASH contained inside the FPGA user flash!
--> then the large DIP package can be eliminated
--> how to program/reprogram the FPGA flash in a nice way? (not using QUARTUS!)
--> consider adding the internal FLASH into the memory mapper (pages 41-...?)

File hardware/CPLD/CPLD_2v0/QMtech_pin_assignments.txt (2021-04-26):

# -------------------------------------------------------------------------- 
# QMTECH Mainboard Pin Assignments
# -------------------------------------------------------------------------- 
set_location_assignment PIN_H6 -to sys_clk
set_location_assignment PIN_G13 -to sys_rst_n
set_location_assignment PIN_G10 -to dig_1
set_location_assignment PIN_G9 -to dig_2
set_location_assignment PIN_K12 -to dig_3
set_location_assignment PIN_J12 -to seg_full[7]
set_location_assignment PIN_L13 -to seg_full[6]
set_location_assignment PIN_J13 -to seg_full[5]
set_location_assignment PIN_H9 -to seg_full[4]
set_location_assignment PIN_H10 -to seg_full[3]
set_location_assignment PIN_K13 -to seg_full[2]
set_location_assignment PIN_L12 -to seg_full[1]
set_location_assignment PIN_H13 -to seg_full[0]
set_location_assignment PIN_H2 -to uart_rx
set_location_assignment PIN_H1 -to uart_tx
set_location_assignment PIN_G12 -to sw_1
set_location_assignment PIN_F9 -to led_1
set_location_assignment PIN_F10 -to led_2

# -------------------------------------------------------------------------- 
# HD6309 SBC II Testboard Pin Assignments
# These are connected via the two 50pos headers.  All signals on testboard 
# are prefaced with "t_" to disambiguate them from any similar signals
# on the QMTECH mainboard.
# -------------------------------------------------------------------------- 

# Testboard pushbutton, jumpers, and LEDs
set_location_assignment PIN_M1 -to t_led_4
set_location_assignment PIN_A1 -to t_led_busy
set_location_assignment PIN_H4 -to t_btn
set_location_assignment PIN_A11 -to t_conf_1
set_location_assignment PIN_B11 -to t_conf_2

# WS2812 RGB LED serial control (two in series)
set_location_assignment PIN_N3 -to t_rgb_q

# CP2105 dual UART USB bridge SCI and ECI ports
# note: "rx" is data FROM USB bridge INTO CPLD and "tx" is 
#       data INTO USB bridge FROM CPLD
set_location_assignment PIN_H5 -to t_sci_rx
set_location_assignment PIN_J6 -to t_sci_tx
set_location_assignment PIN_J1 -to t_eci_rx
set_location_assignment PIN_K1 -to t_eci_tx
set_location_assignment PIN_L1 -to t_eci_rts

# I2C bus to RTC and EEPROM
set_location_assignment PIN_J2 -to t_sda
set_location_assignment PIN_K2 -to t_scl

# SPI bus to EEPROM (containing ROM images)
set_location_assignment PIN_L3 -to t_ee_cs_n
set_location_assignment PIN_N2 -to t_ee_clk
set_location_assignment PIN_M2 -to t_ee_miso
set_location_assignment PIN_M3 -to t_ee_mosi

# SPI bus to SD Card (disk emulation)
set_location_assignment PIN_E1 -to t_sd_card
set_location_assignment PIN_C2 -to t_sd_cs_n
set_location_assignment PIN_E3 -to t_sd_clk
set_location_assignment PIN_F1 -to t_sd_miso
set_location_assignment PIN_D1 -to t_sd_mosi

# HD6309 CPU address bus
# note: SRAM address inputs A0-A10 are shared with CPU address
#       bus. To control A0-A10 inputs from CPLD, disable the CPU 
#       address bus buffer by negating ('1') t_aben_n.
set_location_assignment PIN_L10 -to t_aben_n
set_location_assignment PIN_L4 -to t_addr[15]
set_location_assignment PIN_J8 -to t_addr[14]
set_location_assignment PIN_M4 -to t_addr[13]
set_location_assignment PIN_L5 -to t_addr[12]
set_location_assignment PIN_M5 -to t_addr[11]
set_location_assignment PIN_N4 -to t_addr[10]
set_location_assignment PIN_K5 -to t_addr[9]
set_location_assignment PIN_N5 -to t_addr[8]
set_location_assignment PIN_N6 -to t_addr[7]
set_location_assignment PIN_J5 -to t_addr[6]
set_location_assignment PIN_M7 -to t_addr[5]
set_location_assignment PIN_N7 -to t_addr[4]
set_location_assignment PIN_K7 -to t_addr[3]
set_location_assignment PIN_N8 -to t_addr[2]
set_location_assignment PIN_K6 -to t_addr[1]
set_location_assignment PIN_M8 -to t_addr[0]

# HD6309 CPU data bus
# note: D0-D7 are also connected to SRAM data. To write data to 
#       SRAM from the CPLD (e.g. during ROM image loading), disable
#       the CPU data bus buffer by negating ('1') t_dben_n.
set_location_assignment PIN_F12 -to t_dben_n
set_location_assignment PIN_D12 -to t_dbdir
set_location_assignment PIN_B13 -to t_data[0]
set_location_assignment PIN_D13 -to t_data[1]
set_location_assignment PIN_C13 -to t_data[2]
set_location_assignment PIN_A12 -to t_data[3]
set_location_assignment PIN_B12 -to t_data[4]
set_location_assignment PIN_C11 -to t_data[5]
set_location_assignment PIN_C12 -to t_data[6]
set_location_assignment PIN_D11 -to t_data[7]

# HD6309 CPU control and status
set_location_assignment PIN_K8 -to t_ba
set_location_assignment PIN_N9 -to t_bs
set_location_assignment PIN_N10 -to t_lic
set_location_assignment PIN_M13 -to t_halt_n
set_location_assignment PIN_D9 -to t_rw_n
set_location_assignment PIN_C9 -to t_avma
set_location_assignment PIN_N11 -to t_irq_n
set_location_assignment PIN_N12 -to t_nmi_n
set_location_assignment PIN_E13 -to t_qclk
set_location_assignment PIN_F13 -to t_eclk

# 1MB x 8 SRAM
# note: SRAM address inputs A0-A10 are shared with CPU address
#       bus. To control A0-A10 inputs from CPLD, disable the CPU 
#       address bus buffer by negating ('1') t_aben_n.
# note: D0-D7 are also connected to CPU data. To write data to 
#       SRAM from the CPLD (e.g. during ROM image loading), disable
#       the CPU data bus buffer by negating ('1') t_dben_n.
set_location_assignment PIN_E4 -to t_ram_oe_n
set_location_assignment PIN_A4 -to t_ram_cs_n
set_location_assignment PIN_A6 -to t_ram_we_n
set_location_assignment PIN_C1 -to t_maddr[19]
set_location_assignment PIN_B1 -to t_maddr[18]
set_location_assignment PIN_B2 -to t_maddr[17]
set_location_assignment PIN_A2 -to t_maddr[16]
set_location_assignment PIN_A3 -to t_maddr[15]
set_location_assignment PIN_A7 -to t_maddr[14]
set_location_assignment PIN_E8 -to t_maddr[13]
set_location_assignment PIN_E9 -to t_maddr[12]
set_location_assignment PIN_A9 -to t_maddr[11]

# Miscellaneous Test Signals
set_location_assignment PIN_M9 -to t_clk32
set_location_assignment PIN_B3 -to t_tp[1]
set_location_assignment PIN_B4 -to t_tp[2]
set_location_assignment PIN_B5 -to t_tp[3]
set_location_assignment PIN_B6 -to t_tp[4]
set_location_assignment PIN_L11 -to t_tp[5]
set_location_assignment PIN_M11 -to t_tp[6]
set_location_assignment PIN_M12 -to t_tp[7]
set_location_assignment PIN_K11 -to t_tp[8]

# System and CPU RESET control
# note: t_lvres_n is the RESET OUTPUT from the DS3231 RTC, also
#       wired-OR with the RESET pushbutton. This should be an
#       INPUT to the CPLD.
#       t_resrq is the RESET REQUEST output to the CPU, via a
#       simple inverting NMOS with a pullup on gate. To RESET
#       the CPU, either assert ('1') this output or change it
#       to an input. 
set_location_assignment PIN_M10 -to t_lvrst_n
set_location_assignment PIN_E12 -to t_rstrq

# -------------------------------------------------------------------------- 
# QMTECH Mainboard IO Standards
# -------------------------------------------------------------------------- 
set_instance_assignment -name IO_STANDARD "3.3-V LVTTL" -to led_1
set_instance_assignment -name IO_STANDARD "3.3-V LVTTL" -to led_2
set_instance_assignment -name IO_STANDARD "3.3-V LVTTL" -to sys_clk
set_instance_assignment -name IO_STANDARD "3.3-V LVTTL" -to sys_rst_n
set_instance_assignment -name IO_STANDARD "3.3-V LVTTL" -to sw_1
set_instance_assignment -name IO_STANDARD "3.3-V LVTTL" -to dig_1
set_instance_assignment -name IO_STANDARD "3.3-V LVTTL" -to dig_2
set_instance_assignment -name IO_STANDARD "3.3-V LVTTL" -to dig_3
set_instance_assignment -name IO_STANDARD "3.3-V LVTTL" -to seg_full[7]
set_instance_assignment -name IO_STANDARD "3.3-V LVTTL" -to seg_full[6]
set_instance_assignment -name IO_STANDARD "3.3-V LVTTL" -to seg_full[5]
set_instance_assignment -name IO_STANDARD "3.3-V LVTTL" -to seg_full[4]
set_instance_assignment -name IO_STANDARD "3.3-V LVTTL" -to seg_full[3]
set_instance_assignment -name IO_STANDARD "3.3-V LVTTL" -to seg_full[2]
set_instance_assignment -name IO_STANDARD "3.3-V LVTTL" -to seg_full[1]
set_instance_assignment -name IO_STANDARD "3.3-V LVTTL" -to seg_full[0]
set_instance_assignment -name IO_STANDARD "3.3-V LVTTL" -to uart_rx
set_instance_assignment -name IO_STANDARD "3.3-V LVTTL" -to uart_tx

# -------------------------------------------------------------------------- 
# HD6309 SBC II Testboard IO Standards
# -------------------------------------------------------------------------- 
set_instance_assignment -name IO_STANDARD "3.3-V LVTTL" -to t_led_4
set_instance_assignment -name IO_STANDARD "3.3-V LVTTL" -to t_led_busy
set_instance_assignment -name IO_STANDARD "3.3-V LVTTL" -to t_btn
set_instance_assignment -name IO_STANDARD "3.3-V LVTTL" -to t_conf_1
set_instance_assignment -name IO_STANDARD "3.3-V LVTTL" -to t_conf_2
set_instance_assignment -name IO_STANDARD "3.3-V LVTTL" -to t_rgb_q
set_instance_assignment -name IO_STANDARD "3.3-V LVTTL" -to t_sci_rx
set_instance_assignment -name IO_STANDARD "3.3-V LVTTL" -to t_sci_tx
set_instance_assignment -name IO_STANDARD "3.3-V LVTTL" -to t_eci_rx
set_instance_assignment -name IO_STANDARD "3.3-V LVTTL" -to t_eci_tx
set_instance_assignment -name IO_STANDARD "3.3-V LVTTL" -to t_eci_rts
set_instance_assignment -name IO_STANDARD "3.3-V LVTTL" -to t_sda
set_instance_assignment -name IO_STANDARD "3.3-V LVTTL" -to t_scl
set_instance_assignment -name IO_STANDARD "3.3-V LVTTL" -to t_ee_cs_n
set_instance_assignment -name IO_STANDARD "3.3-V LVTTL" -to t_ee_miso
set_instance_assignment -name IO_STANDARD "3.3-V LVTTL" -to t_ee_clk
set_instance_assignment -name IO_STANDARD "3.3-V LVTTL" -to t_ee_mosi
set_instance_assignment -name IO_STANDARD "3.3-V LVTTL" -to t_sd_card
set_instance_assignment -name IO_STANDARD "3.3-V LVTTL" -to t_sd_miso
set_instance_assignment -name IO_STANDARD "3.3-V LVTTL" -to t_sd_clk
set_instance_assignment -name IO_STANDARD "3.3-V LVTTL" -to t_sd_mosi
set_instance_assignment -name IO_STANDARD "3.3-V LVTTL" -to t_sd_cs_n
set_instance_assignment -name IO_STANDARD "3.3-V LVTTL" -to t_aben_n
set_instance_assignment -name IO_STANDARD "3.3-V LVTTL" -to t_a15
set_instance_assignment -name IO_STANDARD "3.3-V LVTTL" -to t_a14
set_instance_assignment -name IO_STANDARD "3.3-V LVTTL" -to t_a13
set_instance_assignment -name IO_STANDARD "3.3-V LVTTL" -to t_a12
set_instance_assignment -name IO_STANDARD "3.3-V LVTTL" -to t_a11
set_instance_assignment -name IO_STANDARD "3.3-V LVTTL" -to t_a10
set_instance_assignment -name IO_STANDARD "3.3-V LVTTL" -to t_a9
set_instance_assignment -name IO_STANDARD "3.3-V LVTTL" -to t_a8
set_instance_assignment -name IO_STANDARD "3.3-V LVTTL" -to t_a7
set_instance_assignment -name IO_STANDARD "3.3-V LVTTL" -to t_a6
set_instance_assignment -name IO_STANDARD "3.3-V LVTTL" -to t_a5
set_instance_assignment -name IO_STANDARD "3.3-V LVTTL" -to t_a4
set_instance_assignment -name IO_STANDARD "3.3-V LVTTL" -to t_a3
set_instance_assignment -name IO_STANDARD "3.3-V LVTTL" -to t_a2
set_instance_assignment -name IO_STANDARD "3.3-V LVTTL" -to t_a1
set_instance_assignment -name IO_STANDARD "3.3-V LVTTL" -to t_a0
set_instance_assignment -name IO_STANDARD "3.3-V LVTTL" -to t_dben_n
set_instance_assignment -name IO_STANDARD "3.3-V LVTTL" -to t_dbdir
set_instance_assignment -name IO_STANDARD "3.3-V LVTTL" -to t_d0
set_instance_assignment -name IO_STANDARD "3.3-V LVTTL" -to t_d1
set_instance_assignment -name IO_STANDARD "3.3-V LVTTL" -to t_d2
set_instance_assignment -name IO_STANDARD "3.3-V LVTTL" -to t_d3
set_instance_assignment -name IO_STANDARD "3.3-V LVTTL" -to t_d4
set_instance_assignment -name IO_STANDARD "3.3-V LVTTL" -to t_d5
set_instance_assignment -name IO_STANDARD "3.3-V LVTTL" -to t_d6
set_instance_assignment -name IO_STANDARD "3.3-V LVTTL" -to t_d7
set_instance_assignment -name IO_STANDARD "3.3-V LVTTL" -to t_ba
set_instance_assignment -name IO_STANDARD "3.3-V LVTTL" -to t_bs
set_instance_assignment -name IO_STANDARD "3.3-V LVTTL" -to t_lic
set_instance_assignment -name IO_STANDARD "3.3-V LVTTL" -to t_halt_n
set_instance_assignment -name IO_STANDARD "3.3-V LVTTL" -to t_rw_n
set_instance_assignment -name IO_STANDARD "3.3-V LVTTL" -to t_avma
set_instance_assignment -name IO_STANDARD "3.3-V LVTTL" -to t_irq_n
set_instance_assignment -name IO_STANDARD "3.3-V LVTTL" -to t_nmi_n
set_instance_assignment -name IO_STANDARD "3.3-V LVTTL" -to t_qclk
set_instance_assignment -name IO_STANDARD "3.3-V LVTTL" -to t_eclk
set_instance_assignment -name IO_STANDARD "3.3-V LVTTL" -to t_ram_oe_n
set_instance_assignment -name IO_STANDARD "3.3-V LVTTL" -to t_ram_cs_n
set_instance_assignment -name IO_STANDARD "3.3-V LVTTL" -to t_ram_we_n
set_instance_assignment -name IO_STANDARD "3.3-V LVTTL" -to t_ma19
set_instance_assignment -name IO_STANDARD "3.3-V LVTTL" -to t_ma18
set_instance_assignment -name IO_STANDARD "3.3-V LVTTL" -to t_ma17
set_instance_assignment -name IO_STANDARD "3.3-V LVTTL" -to t_ma16
set_instance_assignment -name IO_STANDARD "3.3-V LVTTL" -to t_ma15
set_instance_assignment -name IO_STANDARD "3.3-V LVTTL" -to t_ma14
set_instance_assignment -name IO_STANDARD "3.3-V LVTTL" -to t_ma13
set_instance_assignment -name IO_STANDARD "3.3-V LVTTL" -to t_ma12
set_instance_assignment -name IO_STANDARD "3.3-V LVTTL" -to t_ma11
set_instance_assignment -name IO_STANDARD "3.3-V LVTTL" -to t_clk32
set_instance_assignment -name IO_STANDARD "3.3-V LVTTL" -to t_tp_1
set_instance_assignment -name IO_STANDARD "3.3-V LVTTL" -to t_tp_2
set_instance_assignment -name IO_STANDARD "3.3-V LVTTL" -to t_tp_3
set_instance_assignment -name IO_STANDARD "3.3-V LVTTL" -to t_tp_4
set_instance_assignment -name IO_STANDARD "3.3-V LVTTL" -to t_tp_5
set_instance_assignment -name IO_STANDARD "3.3-V LVTTL" -to t_tp_6
set_instance_assignment -name IO_STANDARD "3.3-V LVTTL" -to t_tp_7
set_instance_assignment -name IO_STANDARD "3.3-V LVTTL" -to t_tp_8
set_instance_assignment -name IO_STANDARD "3.3-V LVTTL" -to t_lvres_n
set_instance_assignment -name IO_STANDARD "3.3-V LVTTL" -to t_resrq

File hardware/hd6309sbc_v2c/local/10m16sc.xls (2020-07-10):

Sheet: Pin List E144
Pin Information for the Intel® MAX®10 10M16SC Device Version 2017.12.15 Note (1)
Bank Number | VREF | Pin Name/Function | Optional Function(s) | Configuration Function | Dedicated Tx/Rx Channel | Emulated LVDS Output Channel | IO Performance | E144 (2)
1A | VREFB1N0 | IO |  |  | DIFFIO_RX_L1n | DIFFOUT_L1n | Low_Speed | 6
1A | VREFB1N0 | IO |  |  | DIFFIO_RX_L1p | DIFFOUT_L1p | Low_Speed | 7
1A | VREFB1N0 | IO |  |  | DIFFIO_RX_L3n | DIFFOUT_L3n | Low_Speed | 8
1A | VREFB1N0 | IO |  |  | DIFFIO_RX_L3p | DIFFOUT_L3p | Low_Speed | 10
1A | VREFB1N0 | IO |  |  | DIFFIO_RX_L5n | DIFFOUT_L5n | Low_Speed | 11
1A | VREFB1N0 | IO |  |  | DIFFIO_RX_L5p | DIFFOUT_L5p | Low_Speed | 12
1A | VREFB1N0 | IO |  |  | DIFFIO_RX_L7n | DIFFOUT_L7n | Low_Speed | 13
1A | VREFB1N0 | IO |  |  | DIFFIO_RX_L7p | DIFFOUT_L7p | Low_Speed | 14
1B | VREFB1N0 | IO |  | JTAGEN |  |  |  | 15
1B | VREFB1N0 | IO |  | TMS | DIFFIO_RX_L11n | DIFFOUT_L11n | Low_Speed | 16
1B | VREFB1N0 | IO | VREFB1N0 |  |  |  |  | 17
1B | VREFB1N0 | IO |  | TCK | DIFFIO_RX_L11p | DIFFOUT_L11p | Low_Speed | 18
1B | VREFB1N0 | IO |  | TDI | DIFFIO_RX_L12n | DIFFOUT_L12n | Low_Speed | 19
1B | VREFB1N0 | IO |  | TDO | DIFFIO_RX_L12p | DIFFOUT_L12p | Low_Speed | 20
1B | VREFB1N0 | IO |  |  | DIFFIO_RX_L14n | DIFFOUT_L14n | Low_Speed | 21
1B | VREFB1N0 | IO |  |  | DIFFIO_RX_L14p | DIFFOUT_L14p | Low_Speed | 22
1B | VREFB1N0 | IO |  |  | DIFFIO_RX_L16n | DIFFOUT_L16n | Low_Speed | 24
1B | VREFB1N0 | IO |  |  | DIFFIO_RX_L16p | DIFFOUT_L16p | Low_Speed | 25
2 | VREFB2N0 | IO | CLK0n |  | DIFFIO_RX_L20n | DIFFOUT_L20n | High_Speed | 26
2 | VREFB2N0 | IO | CLK0p |  | DIFFIO_RX_L20p | DIFFOUT_L20p | High_Speed | 27
2 | VREFB2N0 | IO | CLK1n |  | DIFFIO_RX_L22n | DIFFOUT_L22n | High_Speed | 28
2 | VREFB2N0 | IO | CLK1p |  | DIFFIO_RX_L22p | DIFFOUT_L22p | High_Speed | 29
2 | VREFB2N0 | IO | VREFB2N0 |  |  |  |  | 30
2 | VREFB2N0 | IO | PLL_L_CLKOUTn |  | DIFFIO_RX_L31n | DIFFOUT_L31n | High_Speed | 32
2 | VREFB2N0 | IO | PLL_L_CLKOUTp |  | DIFFIO_RX_L31p | DIFFOUT_L31p | High_Speed | 33
3 | VREFB3N0 | IO |  |  | DIFFIO_TX_RX_B1n | DIFFOUT_B1n | High_Speed | 38
3 | VREFB3N0 | IO |  |  | DIFFIO_TX_RX_B1p | DIFFOUT_B1p | High_Speed | 39
3 | VREFB3N0 | IO |  |  | DIFFIO_TX_RX_B3n | DIFFOUT_B3n | High_Speed | 41
3 | VREFB3N0 | IO |  |  | DIFFIO_TX_RX_B3p | DIFFOUT_B3p | High_Speed | 43
3 | VREFB3N0 | IO |  |  | DIFFIO_TX_RX_B5n | DIFFOUT_B5n | High_Speed | 44
3 | VREFB3N0 | IO |  |  | DIFFIO_TX_RX_B5p | DIFFOUT_B5p | High_Speed | 45
3 | VREFB3N0 | IO |  |  | DIFFIO_TX_RX_B13n | DIFFOUT_B13n | High_Speed | 46
3 | VREFB3N0 | IO |  |  | DIFFIO_TX_RX_B13p | DIFFOUT_B13p | High_Speed | 47
3 | VREFB3N0 | IO |  |  | DIFFIO_TX_RX_B15n | DIFFOUT_B15n | High_Speed | 50
3 | VREFB3N0 | IO | VREFB3N0 |  |  |  |  | 48
3 | VREFB3N0 | IO |  |  | DIFFIO_TX_RX_B15p | DIFFOUT_B15p | High_Speed | 52
3 | VREFB3N0 | IO |  |  |  |  |  | 54
3 | VREFB3N0 | IO | CLK6n |  | DIFFIO_TX_RX_B18n | DIFFOUT_B18n | High_Speed | 55
3 | VREFB3N0 | IO | CLK6p |  | DIFFIO_TX_RX_B18p | DIFFOUT_B18p | High_Speed | 56
3 | VREFB3N0 | IO | CLK7n |  | DIFFIO_TX_RX_B20n | DIFFOUT_B20n | High_Speed | 57
3 | VREFB3N0 | IO | CLK7p |  | DIFFIO_TX_RX_B20p | DIFFOUT_B20p | High_Speed | 58
3 | VREFB3N0 | IO |  |  | DIFFIO_TX_RX_B22n | DIFFOUT_B22n | High_Speed | 59
3 | VREFB3N0 | IO |  |  | DIFFIO_TX_RX_B22p | DIFFOUT_B22p | High_Speed | 60
4 | VREFB4N0 | IO | VREFB4N0 |  |  |  |  | 61
4 | VREFB4N0 | IO |  |  |  |  |  | 62
4 | VREFB4N0 | IO |  |  | DIFFIO_TX_RX_B35n | DIFFOUT_B35n | High_Speed | 64
4 | VREFB4N0 | IO |  |  | DIFFIO_TX_RX_B35p | DIFFOUT_B35p | High_Speed | 65
4 | VREFB4N0 | IO |  |  |  |  |  | 66
4 | VREFB4N0 | IO |  |  | DIFFIO_TX_RX_B41n | DIFFOUT_B41n | High_Speed | 69
4 | VREFB4N0 | IO |  |  | DIFFIO_TX_RX_B41p | DIFFOUT_B41p | High_Speed | 70
5 | VREFB5N0 | IO | RUP |  | DIFFIO_RX_R1p | DIFFOUT_R1p | High_Speed | 75
5 | VREFB5N0 | IO |  |  | DIFFIO_RX_R2p | DIFFOUT_R2p | High_Speed | 74
5 | VREFB5N0 | IO | RDN |  | DIFFIO_RX_R1n | DIFFOUT_R1n | High_Speed | 77
5 | VREFB5N0 | IO |  |  | DIFFIO_RX_R2n | DIFFOUT_R2n | High_Speed | 76
5 | VREFB5N0 | IO |  |  | DIFFIO_RX_R11p | DIFFOUT_R11p | High_Speed | 79
5 | VREFB5N0 | IO |  |  |  |  |  | 78
5 | VREFB5N0 | IO |  |  | DIFFIO_RX_R11n | DIFFOUT_R11n | High_Speed | 81
5 | VREFB5N0 | IO | VREFB5N0 |  |  |  |  | 80
5 | VREFB5N0 | IO |  |  | DIFFIO_RX_R14p | DIFFOUT_R14p | High_Speed | 85
5 | VREFB5N0 | IO |  |  | DIFFIO_RX_R15p | DIFFOUT_R15p | High_Speed | 84
5 | VREFB5N0 | IO |  |  | DIFFIO_RX_R14n | DIFFOUT_R14n | High_Speed | 87
5 | VREFB5N0 | IO |  |  | DIFFIO_RX_R15n | DIFFOUT_R15n | High_Speed | 86
6 | VREFB6N0 | IO | CLK2p |  | DIFFIO_RX_R18p | DIFFOUT_R18p | High_Speed | 88
6 | VREFB6N0 | IO | CLK2n |  | DIFFIO_RX_R18n | DIFFOUT_R18n | High_Speed | 89
6 | VREFB6N0 | IO | CLK3p |  | DIFFIO_RX_R20p | DIFFOUT_R20p | High_Speed | 90
6 | VREFB6N0 | IO | CLK3n |  | DIFFIO_RX_R20n | DIFFOUT_R20n | High_Speed | 91
6 | VREFB6N0 | IO |  |  | DIFFIO_RX_R22p | DIFFOUT_R22p | High_Speed | 92
6 | VREFB6N0 | IO |  |  | DIFFIO_RX_R22n | DIFFOUT_R22n | High_Speed | 93
6 | VREFB6N0 | IO | DPCLK3 |  | DIFFIO_RX_R30p | DIFFOUT_R30p | High_Speed | 96
6 | VREFB6N0 | IO | VREFB6N0 |  |  |  |  | 97
6 | VREFB6N0 | IO | DPCLK2 |  | DIFFIO_RX_R30n | DIFFOUT_R30n | High_Speed | 98
6 | VREFB6N0 | IO |  |  | DIFFIO_RX_R31p | DIFFOUT_R31p | High_Speed | 99
6 | VREFB6N0 | IO |  |  | DIFFIO_RX_R32p | DIFFOUT_R32p | High_Speed | 100
6 | VREFB6N0 | IO |  |  | DIFFIO_RX_R31n | DIFFOUT_R31n | High_Speed | 101
6 | VREFB6N0 | IO |  |  | DIFFIO_RX_R32n | DIFFOUT_R32n | High_Speed | 102
6 | VREFB6N0 | IO |  |  | DIFFIO_RX_R37p | DIFFOUT_R37p | High_Speed | 105
6 | VREFB6N0 | IO |  |  | DIFFIO_RX_R37n | DIFFOUT_R37n | High_Speed | 106
7 | VREFB7N0 | IO |  |  | DIFFIO_RX_T1p | DIFFOUT_T1p | High_Speed | 110
7 | VREFB7N0 | IO |  |  | DIFFIO_RX_T1n | DIFFOUT_T1n | High_Speed | 111
7 | VREFB7N0 | IO | VREFB7N0 |  |  |  |  | 112
7 | VREFB7N0 | IO |  |  |  |  |  | 113
7 | VREFB7N0 | IO |  |  |  |  |  | 114
7 | VREFB7N0 | IO |  |  | DIFFIO_RX_T22p | DIFFOUT_T22p | High_Speed | 118
7 | VREFB7N0 | IO |  |  | DIFFIO_RX_T22n | DIFFOUT_T22n | High_Speed | 119
8 | VREFB8N0 | IO |  |  | DIFFIO_RX_T28p | DIFFOUT_T28p | Low_Speed | 120
8 | VREFB8N0 | IO |  | DEV_CLRn | DIFFIO_RX_T28n | DIFFOUT_T28n | Low_Speed | 121
8 | VREFB8N0 | IO |  | DEV_OE |  |  |  | 122
8 | VREFB8N0 | IO | VREFB8N0 |  |  |  |  | 123
8 | VREFB8N0 | IO |  | CONFIG_SEL |  |  |  | 126
8 | VREFB8N0 | IO |  |  | DIFFIO_RX_T31p | DIFFOUT_T31p | Low_Speed | 124
8 | VREFB8N0 | Input_only |  | nCONFIG |  |  |  | 129
8 | VREFB8N0 | IO |  |  | DIFFIO_RX_T31n | DIFFOUT_T31n | Low_Speed | 127
8 | VREFB8N0 | IO |  |  | DIFFIO_RX_T32p | DIFFOUT_T32p | Low_Speed | 130
8 | VREFB8N0 | IO |  |  | DIFFIO_RX_T32n | DIFFOUT_T32n | Low_Speed | 131
8 | VREFB8N0 | IO |  |  | DIFFIO_RX_T34p | DIFFOUT_T34p | Low_Speed | 132
8 | VREFB8N0 | IO |  | CRC_ERROR | DIFFIO_RX_T34n | DIFFOUT_T34n | Low_Speed | 134
8 | VREFB8N0 | IO |  |  |  |  |  | 135
8 | VREFB8N0 | IO |  | nSTATUS | DIFFIO_RX_T36p | DIFFOUT_T36p | Low_Speed | 136
8 | VREFB8N0 | IO |  | CONF_DONE | DIFFIO_RX_T36n | DIFFOUT_T36n | Low_Speed | 138
8 | VREFB8N0 | IO |  |  | DIFFIO_RX_T38p | DIFFOUT_T38p | Low_Speed | 140
8 | VREFB8N0 | IO |  |  | DIFFIO_RX_T38n | DIFFOUT_T38n | Low_Speed | 141
 |  | GND |  |  |  |  |  | 3
 |  | GND |  |  |  |  |  | 4
 |  | GND |  |  |  |  |  | 95
 |  | GND |  |  |  |  |  | 83
 |  | GND |  |  |  |  |  | 68
 |  | GND |  |  |  |  |  | 63
 |  | GND |  |  |  |  |  | 53
 |  | GND |  |  |  |  |  | 42
 |  | GND |  |  |  |  |  | 142
 |  | GND |  |  |  |  |  | 137
 |  | GND |  |  |  |  |  | 133
 |  | GND |  |  |  |  |  | 125
 |  | GND |  |  |  |  |  | 116
 |  | GND |  |  |  |  |  | 104
 |  | VCCIO1A |  |  |  |  |  | 9
 |  | VCCIO1B |  |  |  |  |  | 23
 |  | VCCIO2 |  |  |  |  |  | 31
 |  | VCCIO3 |  |  |  |  |  | 49
 |  | VCCIO3 |  |  |  |  |  | 40
 |  | VCCIO4 |  |  |  |  |  | 67
 |  | VCCIO5 |  |  |  |  |  | 82
 |  | VCCIO6 |  |  |  |  |  | 94
 |  | VCCIO6 |  |  |  |  |  | 103
 |  | VCCIO7 |  |  |  |  |  | 117
 |  | VCCIO8 |  |  |  |  |  | 139
 |  | VCCIO8 |  |  |  |  |  | 128
 |  | VCCA1 |  |  |  |  |  | 35
 |  | VCCA2 |  |  |  |  |  | 34
 |  | VCCA3 |  |  |  |  |  | 5
 |  | VCCA3 |  |  |  |  |  | 107
 |  | VCCA4 |  |  |  |  |  | 143
 |  | VCCA5 |  |  |  |  |  | 71
 |  | VCCA6 |  |  |  |  |  | 2
 |  | VCC_ONE |  |  |  |  |  | 73
 |  | VCC_ONE |  |  |  |  |  | 72
 |  | VCC_ONE |  |  |  |  |  | 51
 |  | VCC_ONE |  |  |  |  |  | 37
 |  | VCC_ONE |  |  |  |  |  | 36
 |  | VCC_ONE |  |  |  |  |  | 144
 |  | VCC_ONE |  |  |  |  |  | 115
 |  | VCC_ONE |  |  |  |  |  | 109
 |  | VCC_ONE |  |  |  |  |  | 108
 |  | VCC_ONE |  |  |  |  |  | 1
Notes:
(1) For more information about pin definition and pin connection guidelines, refer to the
Intel MAX 10 FPGA Device Family Pin Connection Guidelines. (http://www.altera.com/literature/dp/max-10/PCG-01018.pdf)
(2) The E144-pin package has an exposed ground pad at the bottom of the package. The exposed ground pad is used for electrical connectivity and not for thermal purposes. You must connect the exposed ground pad to the ground plane of the PCB.
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

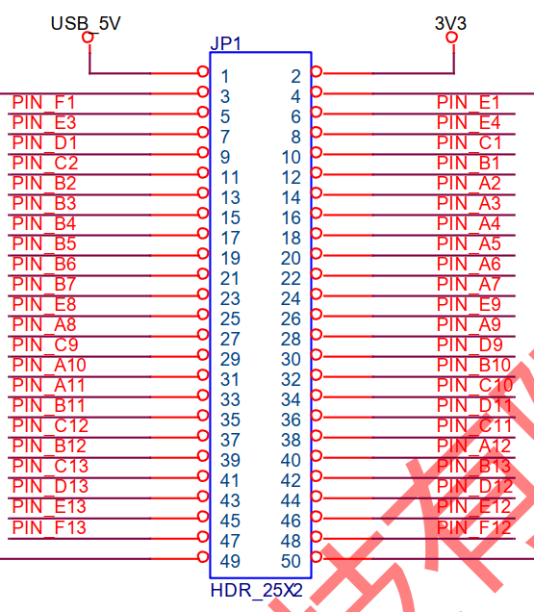
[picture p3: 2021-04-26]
hardware/hd6309sbc_v2c/QMTECH_MAX10_JP1.PNG

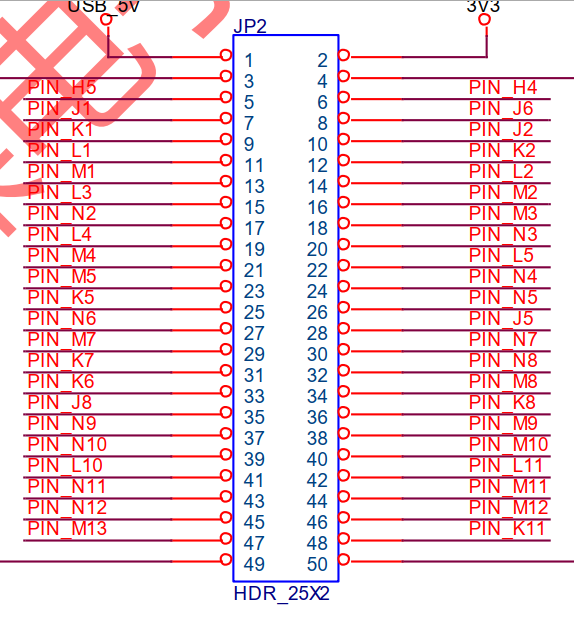
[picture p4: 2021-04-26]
hardware/hd6309sbc_v2c/QMTECH_MAX10_JP2.PNG

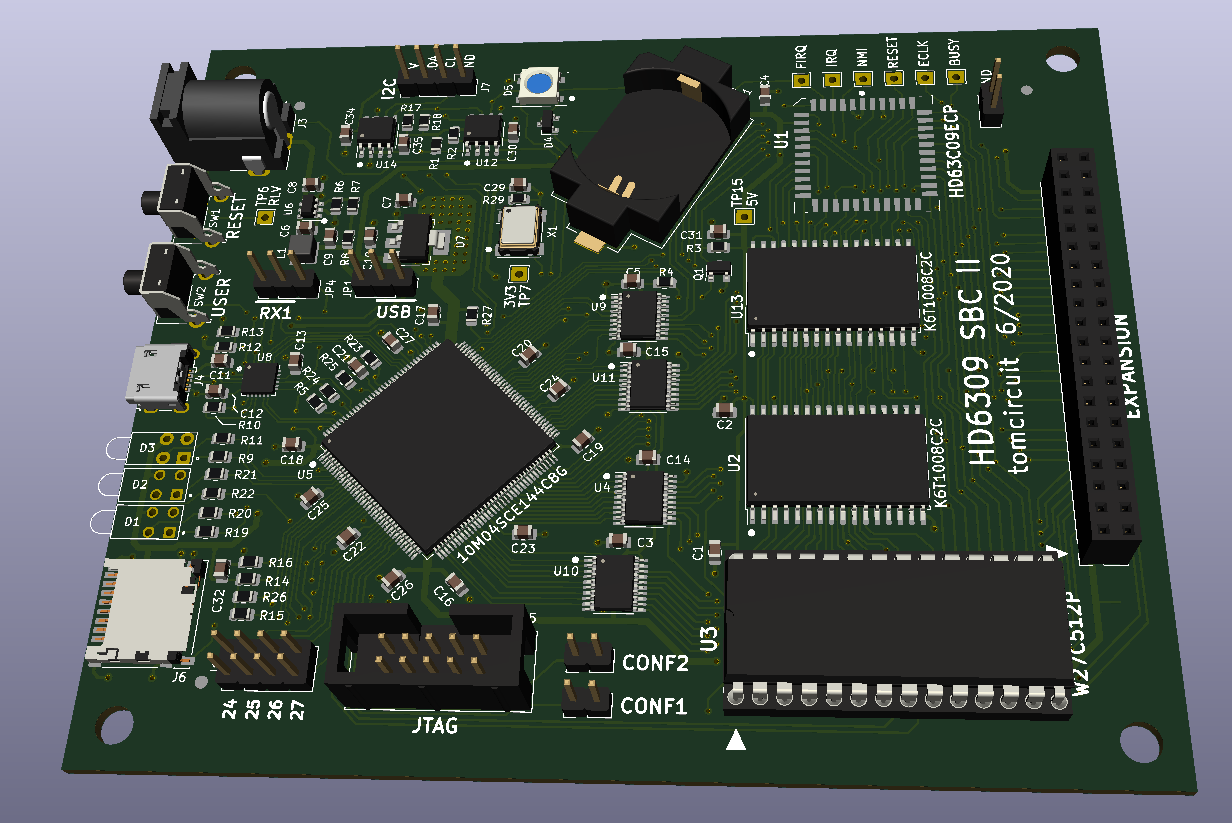
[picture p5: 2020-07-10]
media/pcb_3d_render.PNG

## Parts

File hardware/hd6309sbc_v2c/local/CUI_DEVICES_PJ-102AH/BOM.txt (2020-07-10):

3DX_CUI_DEVICES_Supplier: CUI Devices
3DX_CUI_DEVICES_Description: 2.0 x 6.5 mm, 5.0 A, Horizontal, Through Hole, Tapered Pins, Dc Power Jack Connector
3DX_CUI_DEVICES_Model Number: PJ-102AH

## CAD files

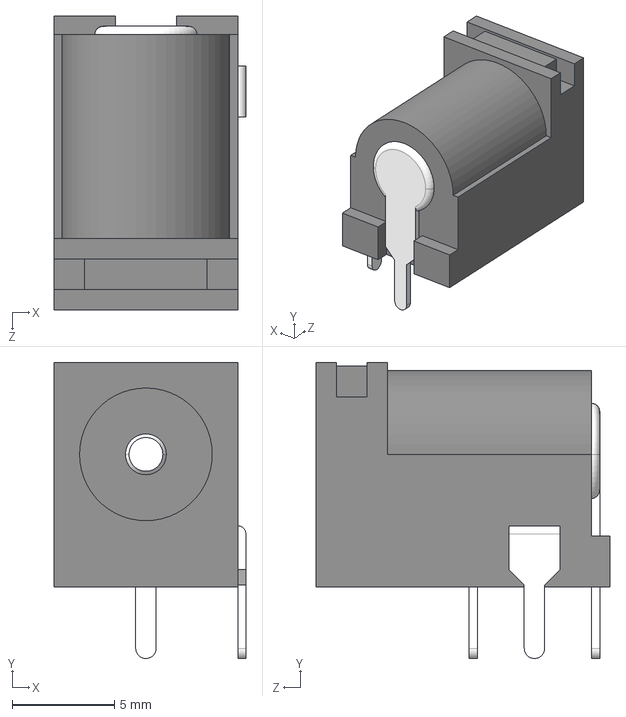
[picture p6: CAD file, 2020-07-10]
hardware/hd6309sbc_v2c/local/CUI_DEVICES_PJ-102AH/PJ-102AH--3DModel-STEP-56544.STEP
9.40 x 14.5 x 14.4 mm

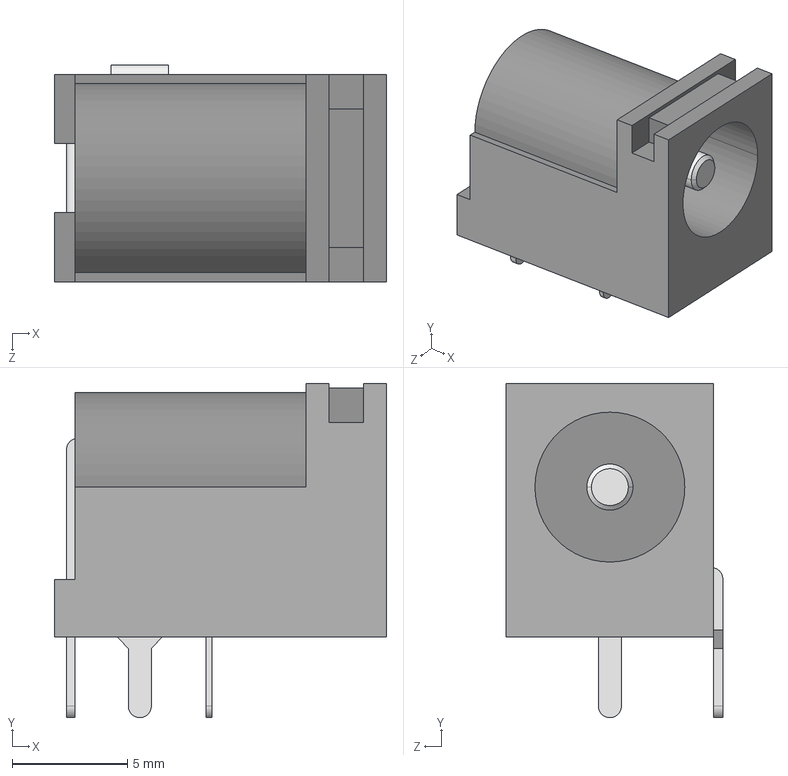
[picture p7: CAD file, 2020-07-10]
hardware/hd6309sbc_v2c/local/CUI_DEVICES_PJ-102AH/CUI_DEVICES_PJ-102AH.step
14.4 x 14.5 x 9.40 mm

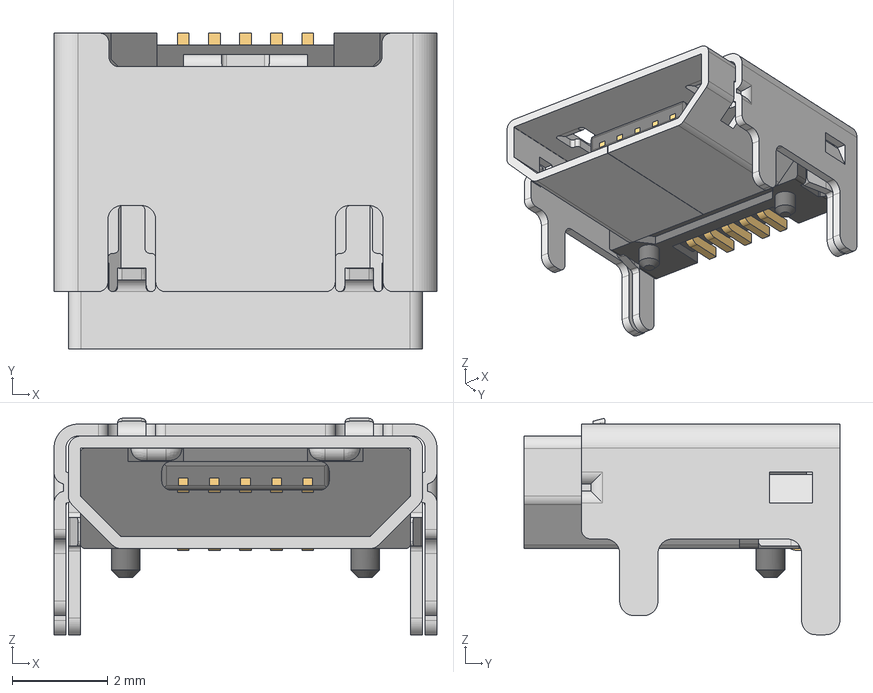
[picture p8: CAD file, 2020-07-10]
hardware/hd6309sbc_v2c/local/629105150521_Download_STP_629105150521_rev1.stp
8.00 x 6.60 x 4.52 mm
629105150521_Pin1 x 4
629105150521_Housing
629105150521_Pin2
629105150521_Shielding
629105150521_Shielding2

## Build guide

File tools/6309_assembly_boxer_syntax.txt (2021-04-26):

name=6309 Assembly
ext=.ASM
reserved=BCC,BCS,BEQ,BGE,BGT,BHI,BHIS,BHS,BLE,BLO,BLOS,BLS,BLT,BMI,BNE,BPL,BRA,BRN,BVC,BVS,BSR,LBCC,LBCS,LBEQ,LBGE,LBGT,LBHI,LBHIS,LBHS,LBLE,LBLO,LBLOS,LBLS,LBLT,LBMI,LBNE,LBPL,LBRA,LBRN,LBVC,LBVS,LBSR,JSR,JMP
reserved2=ADCA,ADCB,ADDA,ADDB,ANDA,ANDB,BITA,BITB,CMPA,CMPB,EORA,EORB,LDA,LDB,ORA,ORB,SBCA,SBCB,STA,STB,SUBA,SUBB,ADDD,SUBD,CMPD,LDD,STD,CMPS,CMPU,CMPX,CMPY,LDS,LDU,LDX,LDY,LEAS,LEAU,LEAX,LEAY,STS,STU,STX,STY,PSHS,PSHU,PULS,PULU,ABX,DAA,MUL,NOP,RTI,RTS,SEX,ROLA,ROLB,ROL,RORA,RORB,ROR,TSTA,TSTB,TST,EXG,TFR,ASLA,ASLB,ASL,ASRA,ASRB,ASR,CLRA,CLRB,CLR,COMA,COMB,COM,DECA,DECB,DEC,INCA,INCB,INC,LSLA,LSLB,LSL,LSRA,LSRB,LSR,NEGA,NEGB,NEG
reserved3=SWI,SWI1,SWI2,SWI3,SYNC,ANDCC,ORCC,CWAI
reserved4=ORG,EQU,FCB,FCC
reserved5=ADCD,ADCR,ADDE,ADDF,ADDW,ADDR,ANDD,ANDR,ASLD,ASRD,BITD,BITMD,CLRD,CLRE,CLRF,CLRW,CMPE,CMPF,CMPW,CMPR,COMD,COME,COMF,COMW,DECD,DECE,DECF,DECW,DIVD,DIVQ,EORD,EORR,INCD,INCE,INCF,INCW,LDE,LDF,LDQ,LDW,LDMD,LSLD,LSRD,LSRW,MULD,NEGD,ORD,ORR,PSHSW,PSHUW,PULSW,PULUW,ROLD,ROLW,RORD,RORW,SBCD,SBCR,SEXW,STE,STF,STQ,STW,SUBE,SUBF,SUBW,SUBR,TFM,TSTD,TSTE,TSTF,TSTW,AIM,OIM,TIM,EIM
rwordsymbols=_
symbols=-,!,#,$,%,(,),*,",",.,/,:,],+,<,>,[
strings=',""""
literal=
opentag=
closetag=
opencom=
closecom=
comsearch=500
eolcom=;
comcol=0
helpfile=
sensitive=0
active=1

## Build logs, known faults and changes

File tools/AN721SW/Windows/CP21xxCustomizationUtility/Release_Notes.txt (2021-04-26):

CP21xx Customization Utility v1.2.2 Release Notes
Copyright (C) 2015 Silicon Laboratories, Inc.

KNOWN ISSUES AND LIMITATIONS
----------------------------

    1) Only CP210x, CP211x, and CP213x devices are supported by this
       application.
	
    2) This application does not support automatic refresh of devices.

    3) CP210x is only supported on Linux and Windows
	
    4) CP2130 is only supported on Windows
	
    5) Programming the serial number will display an incorrect failure
       due to improper reset functionality. This will be addressed in a
       future release.
	
    6) Changing the mode from GPIO to modem on a CP2105 will automatically
       change pin settings that don't reflect on the validation. This
       doesn't affect programming specific settings to the device.

Release Dates
-------------

    CP21xx Customization Utility v1.2.2 - December 18 2015
    CP21xx Customization Utility v1.2.1 - November 7, 2014
    CP21xx Customization Utility v1.2.0 - Feb 28, 2014

REVISION HISTORY
-----------------
Version 1.2.2
    Updated CP2114 programming interface.
    Updated to use latest manufacturing DLL.

Version 1.2.1
    JRE error that occurred when opening the CP21xxCustomizationUtility
    has been fixed.

Version 1.2.0
    Updated to include descriptions in the hex and bit fields
    Fixed bug in CP2130 Port Config write
    Fixed bug in CP2103/4/5 Port Config writes
    Fixed bug in lock values for CP2130/CP2110/CP2114
    Fixed behavior where GPIO/Modem Mode were written seperately and
    incorrectly (combined)

Version 1.1.0
    Added support for CP2130

Version 1.0.1
    Fixed bugs seen when programming CP2105
    Fixed crash when opening on OSX

Version 1.0.0
    Initial Release

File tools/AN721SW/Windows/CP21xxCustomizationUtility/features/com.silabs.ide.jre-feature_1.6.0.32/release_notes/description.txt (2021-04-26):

This feature provides the Java Runtime Environment for Simplicity Studio

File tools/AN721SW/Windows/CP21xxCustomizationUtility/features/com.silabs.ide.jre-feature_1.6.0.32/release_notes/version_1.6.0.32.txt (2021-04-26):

[[NO_CATEGORY]]
No changes from the official 1.6.0.32 distribution

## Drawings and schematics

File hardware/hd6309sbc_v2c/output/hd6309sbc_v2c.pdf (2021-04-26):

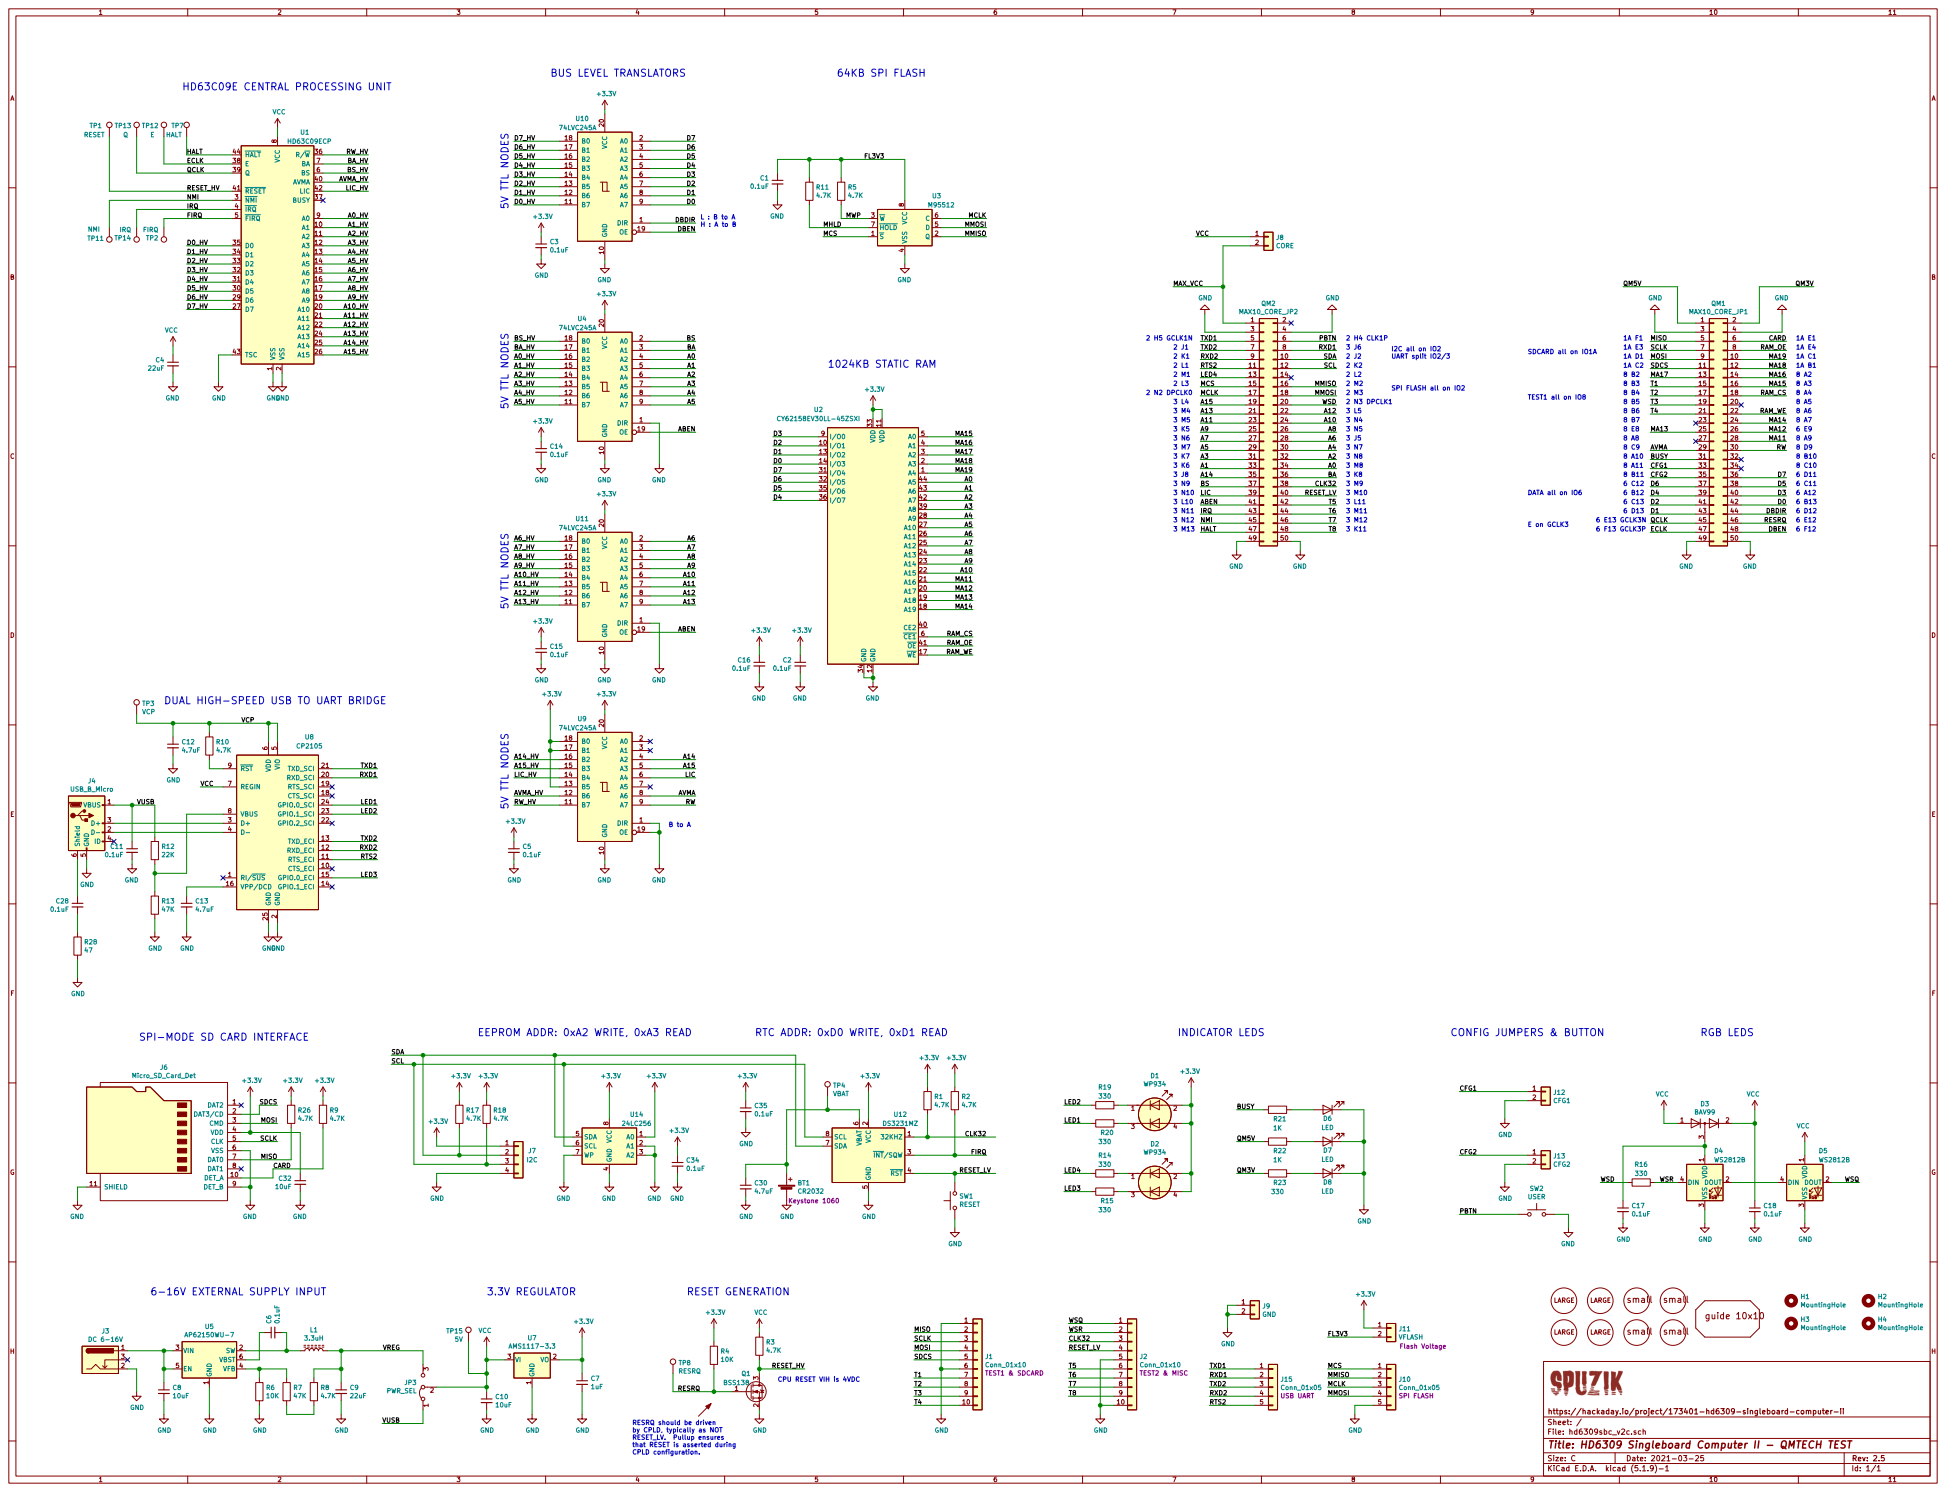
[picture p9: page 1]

2 L2 BUS LEVEL TRANSLATORS 5V TTL NODES 5V TTL NODES 5V TTL NODES

I2C all on IO2 UART split IO2/3

SPI FLASH all on IO2

DUAL HIGH-SPEED USB TO UART BRIDGE
TP3 VCP

2 RXD_SCI 20 TXD_SCI 21 GPIO.2_SCI 22 GPIO.1_SCI 23 GPIO.0_SCI 24 GND 25 D+ 3 D- 4 VIO

EEPROM ADDR: 0xA2 WRITE, 0xA3 READ

4 SDA 5 SCL 6 WP 7 VCC

1 SW 2 VIN 3 VFB 4 EN 5 VBST 6 U5 AP62150WU-7

CPU RESET VIH is 4VDC

File: hd6309sbc_v2c.sch Sheet: / https://hackaday.io/project/173401-hd6309-singleboard-computer-ii

RESRQ should be driven
by CPLD, typically as NOT
RESET_LV. Pullup ensures
that RESET is asserted during
CPLD configuration.

Id: 1/1 Title: HD6309 Singleboard Computer II - QMTECH TEST

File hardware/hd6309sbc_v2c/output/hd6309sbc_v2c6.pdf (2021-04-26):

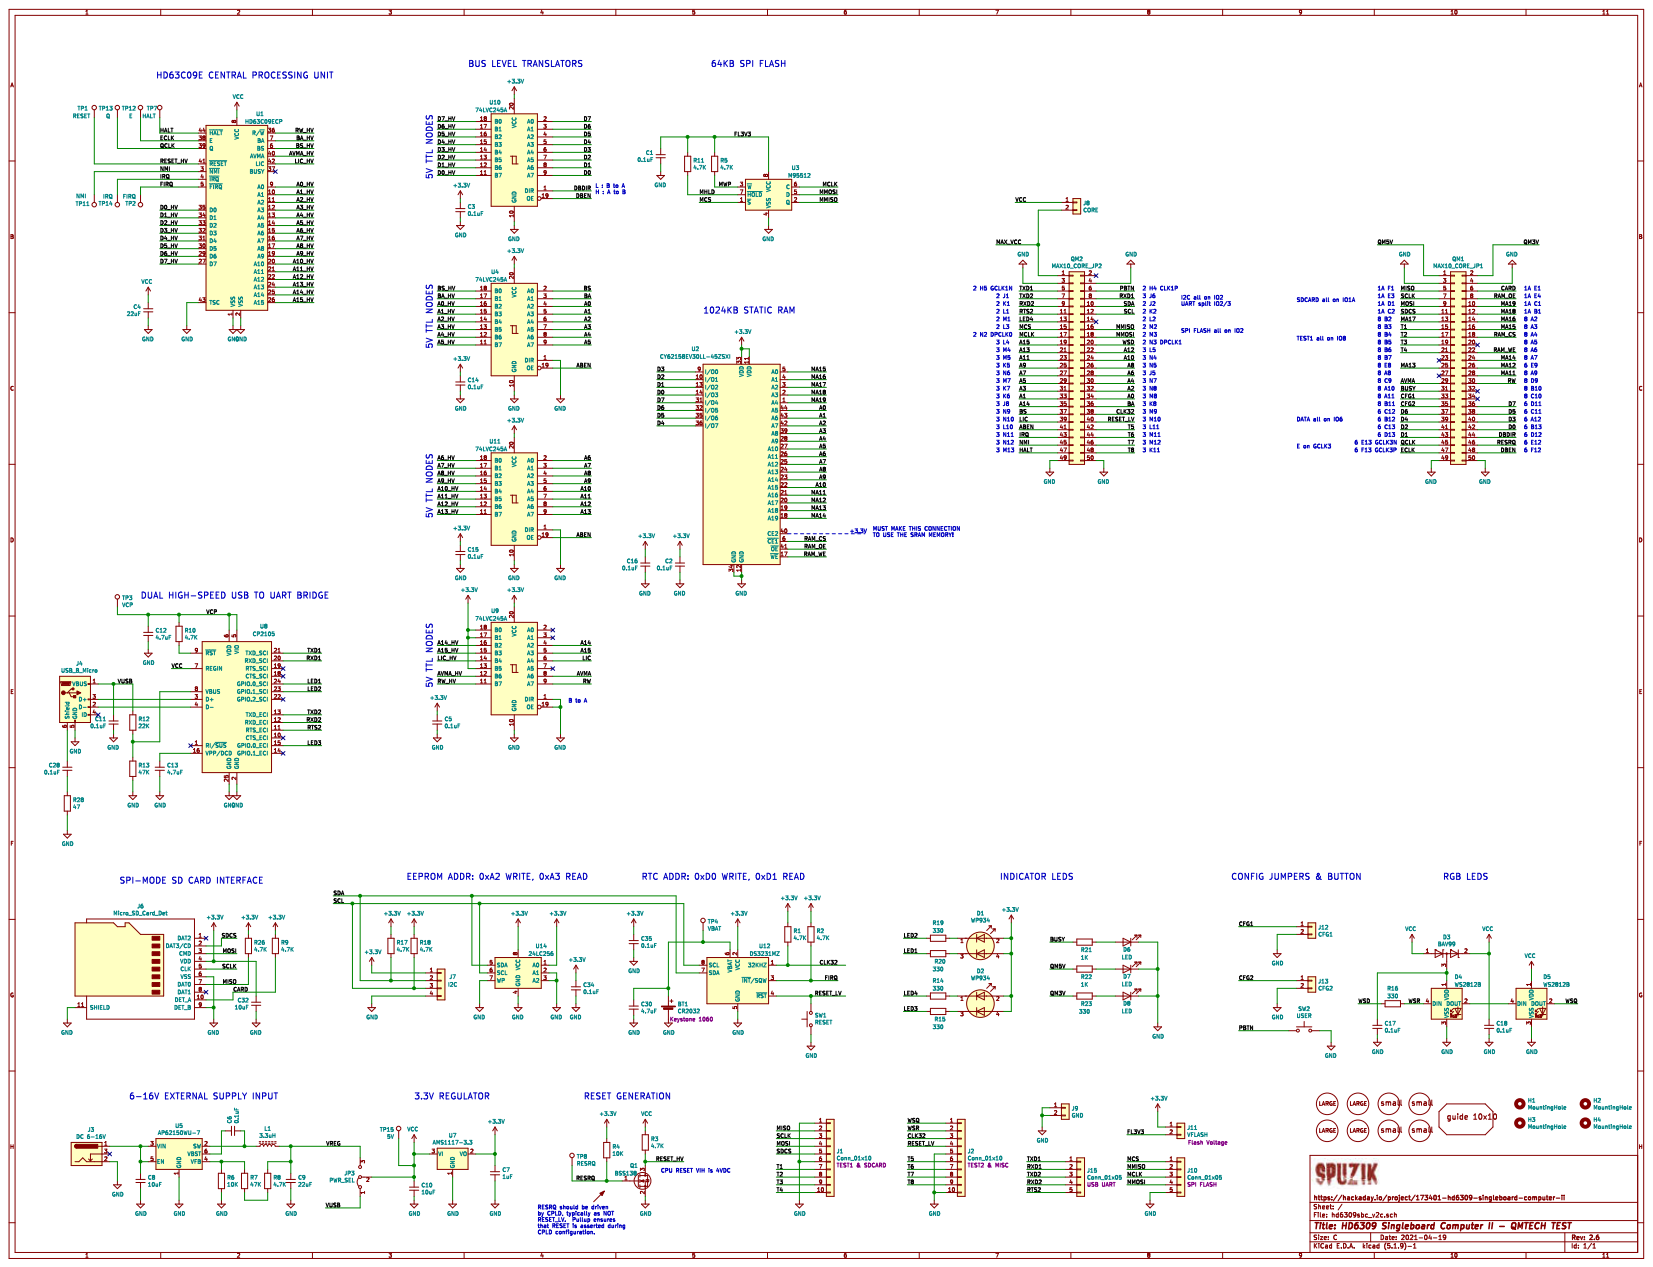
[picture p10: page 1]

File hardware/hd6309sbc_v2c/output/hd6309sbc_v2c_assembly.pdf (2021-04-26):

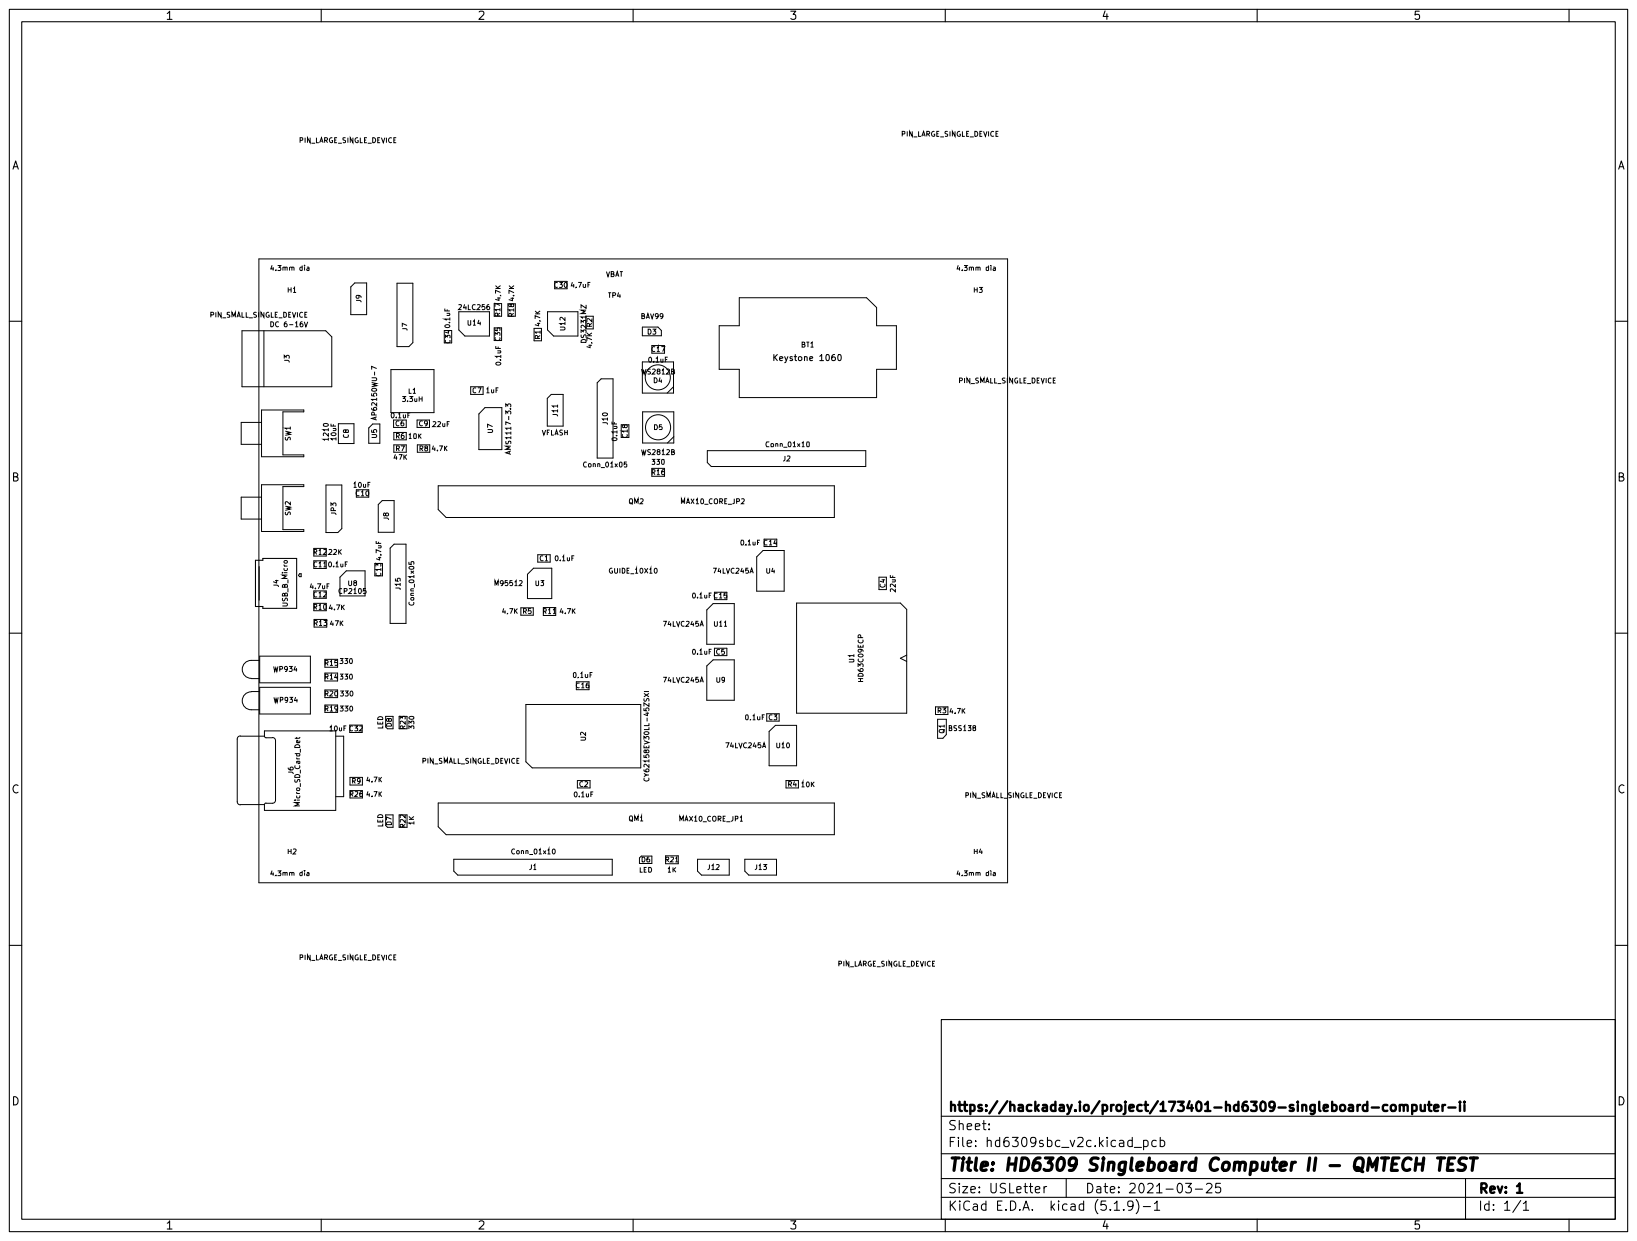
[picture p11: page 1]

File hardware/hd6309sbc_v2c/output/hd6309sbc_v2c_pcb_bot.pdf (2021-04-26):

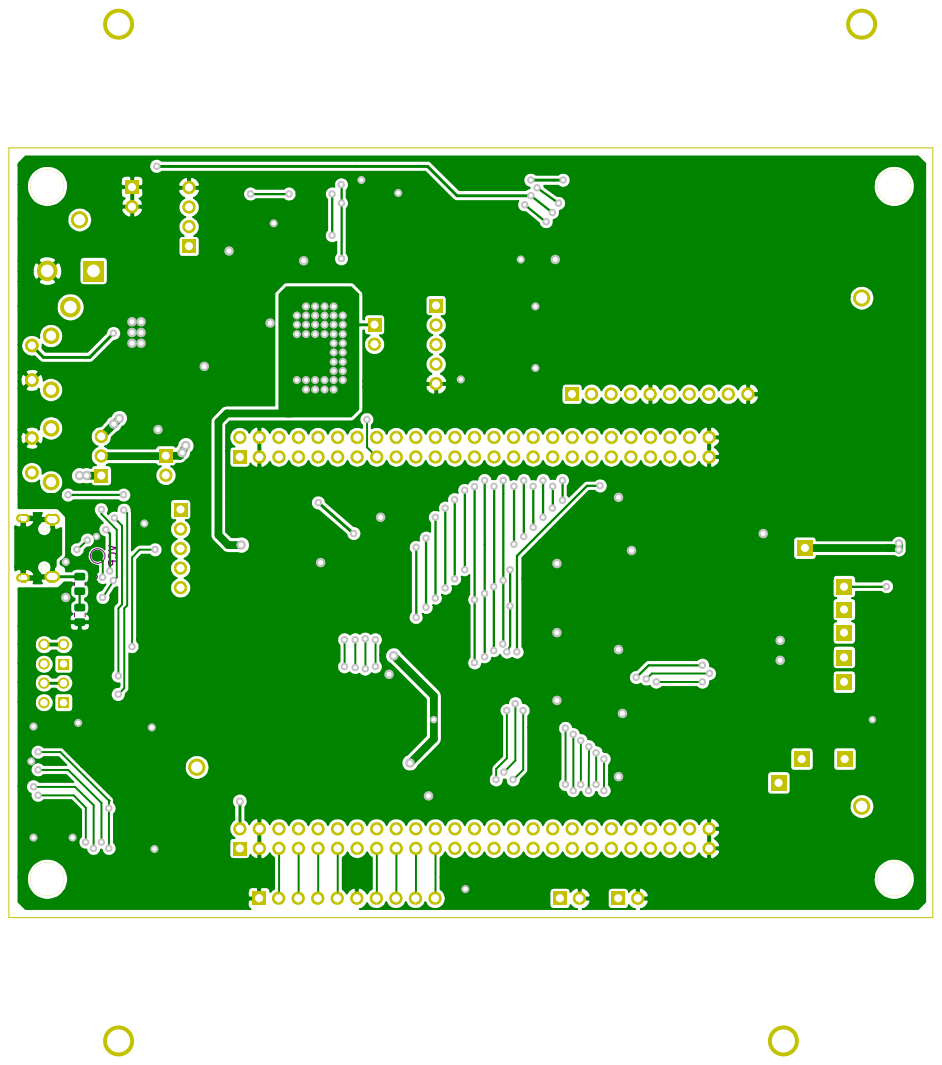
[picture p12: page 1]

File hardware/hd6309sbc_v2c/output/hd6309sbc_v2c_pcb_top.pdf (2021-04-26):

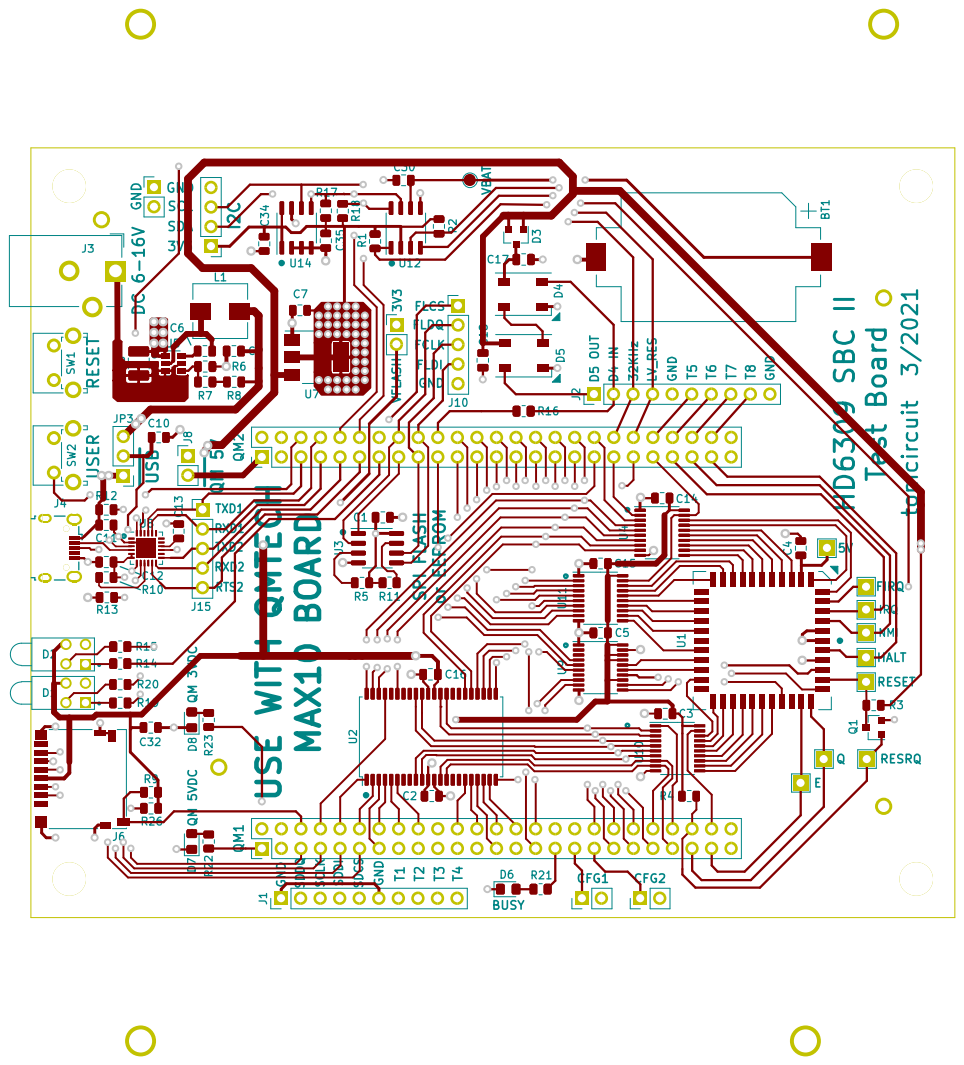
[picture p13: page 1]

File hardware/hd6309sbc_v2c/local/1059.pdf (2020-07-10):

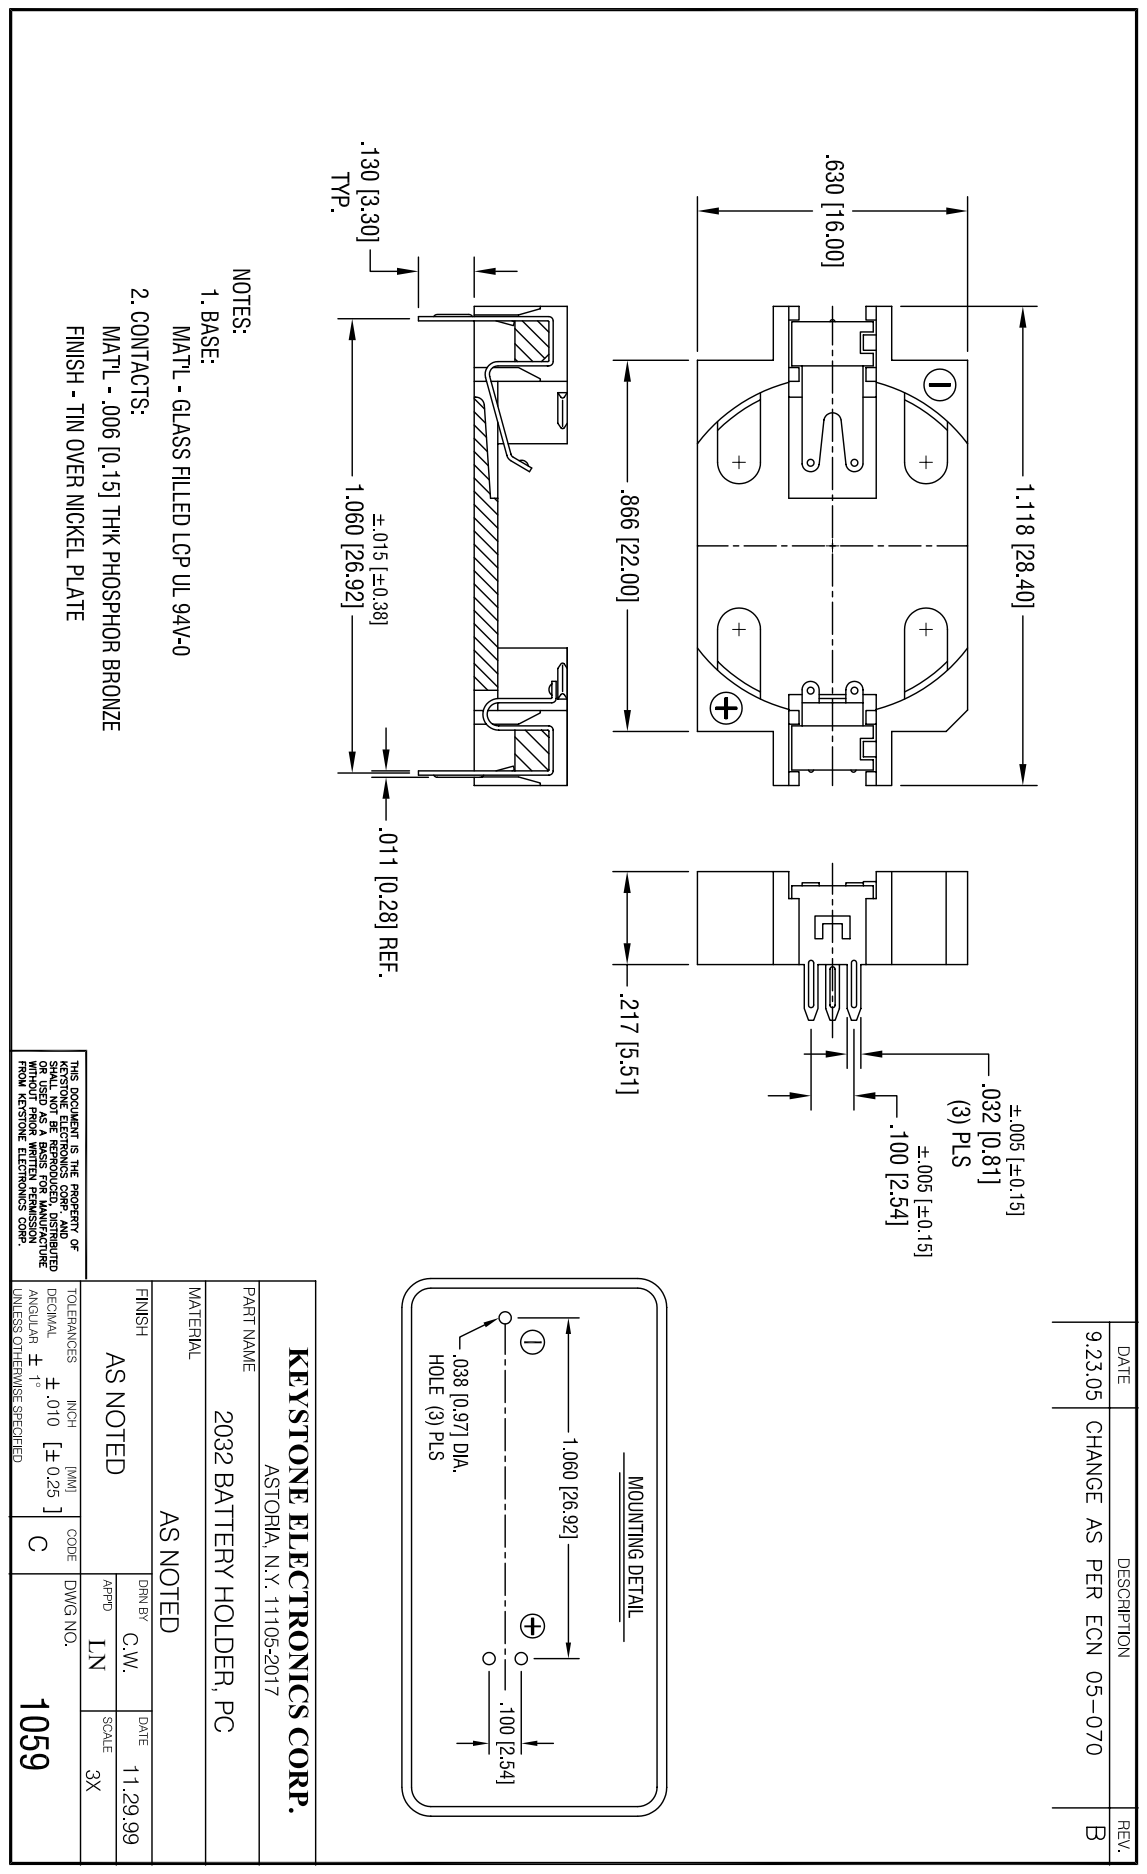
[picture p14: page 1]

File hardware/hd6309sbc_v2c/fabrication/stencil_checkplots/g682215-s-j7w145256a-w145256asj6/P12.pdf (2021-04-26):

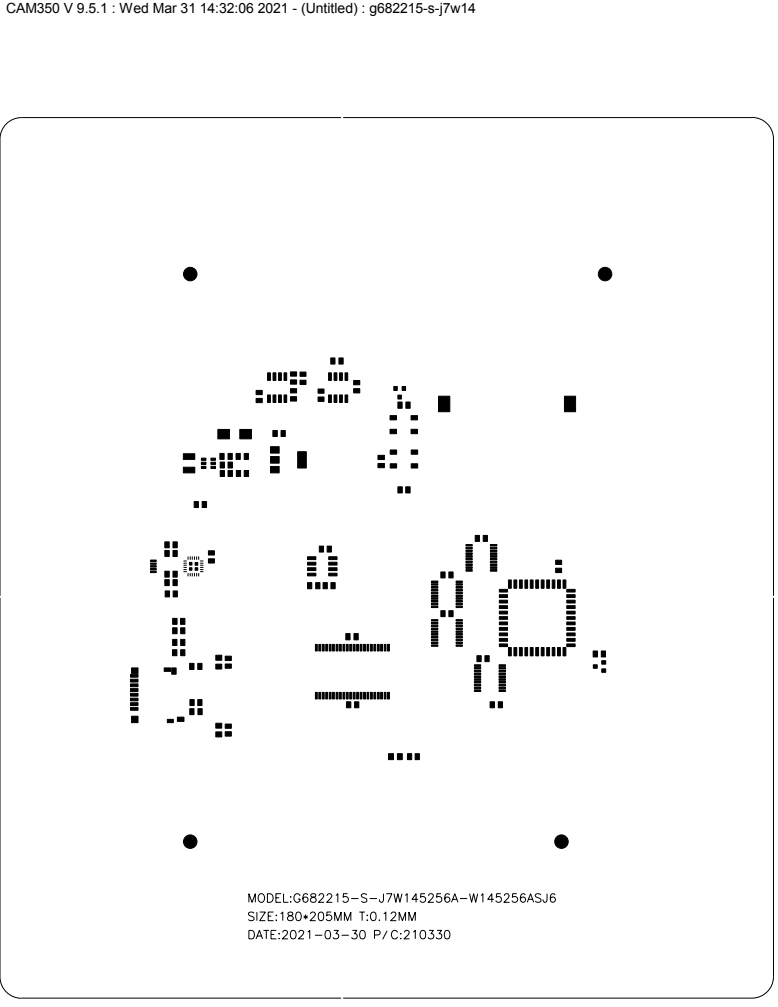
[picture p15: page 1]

CAM350 V 9.5.1 : Wed Mar 31 14:32:06 2021 - (Untitled) : g682215-s-j7w14

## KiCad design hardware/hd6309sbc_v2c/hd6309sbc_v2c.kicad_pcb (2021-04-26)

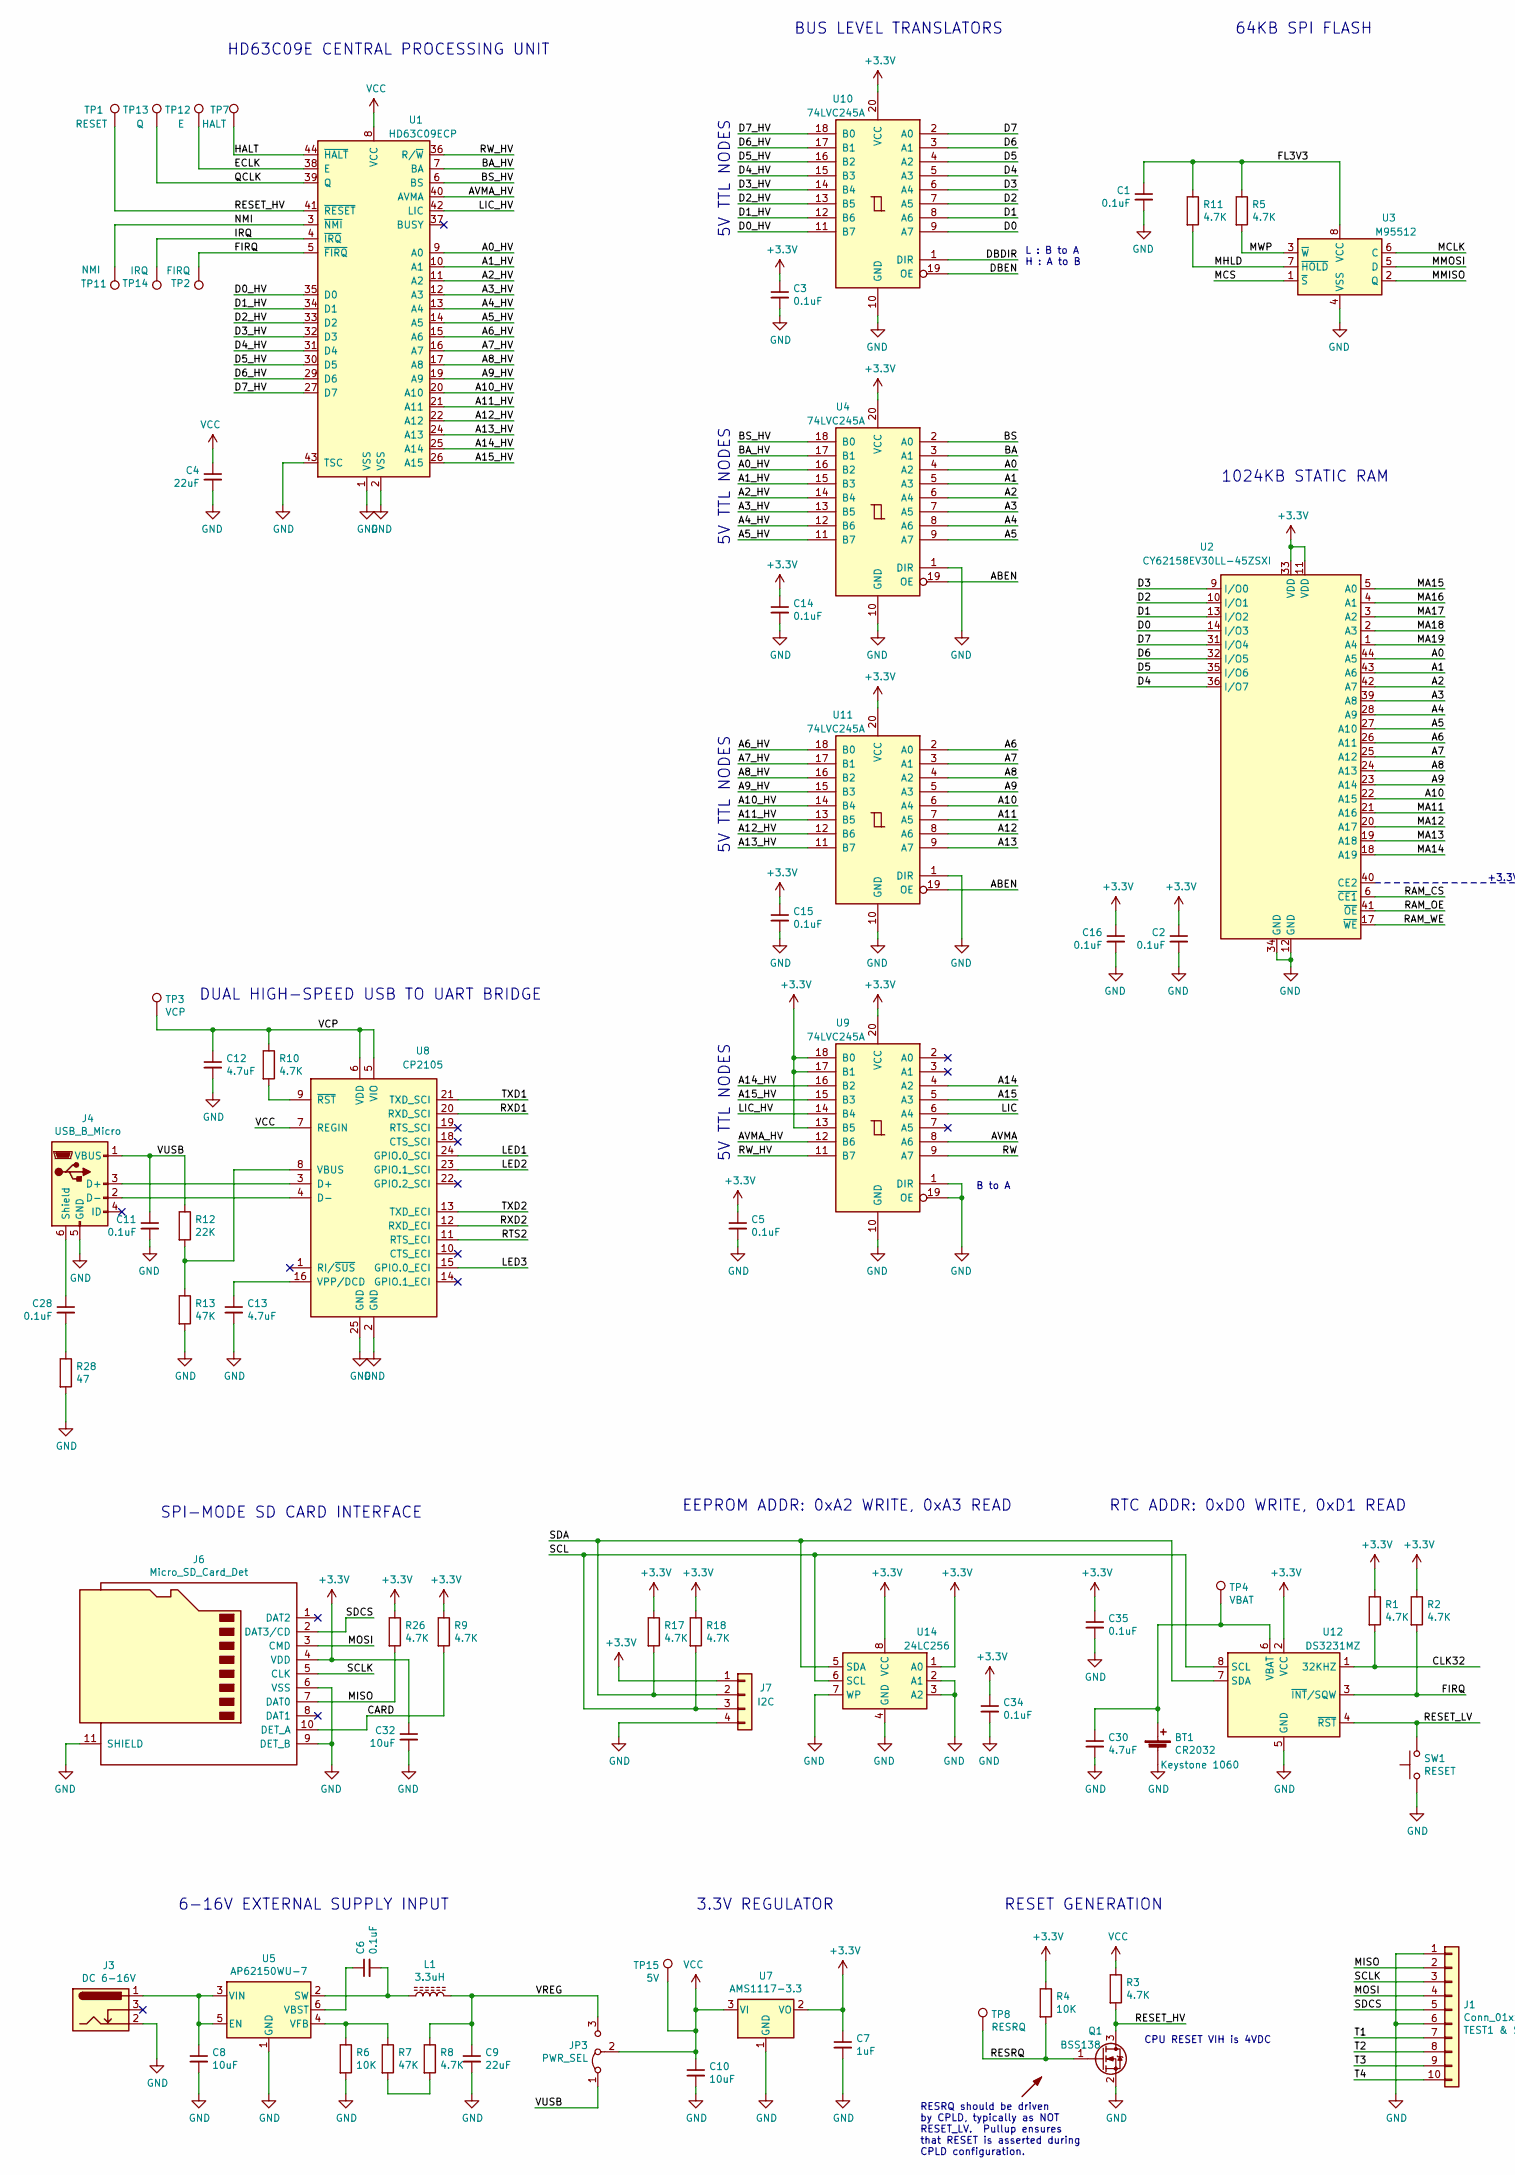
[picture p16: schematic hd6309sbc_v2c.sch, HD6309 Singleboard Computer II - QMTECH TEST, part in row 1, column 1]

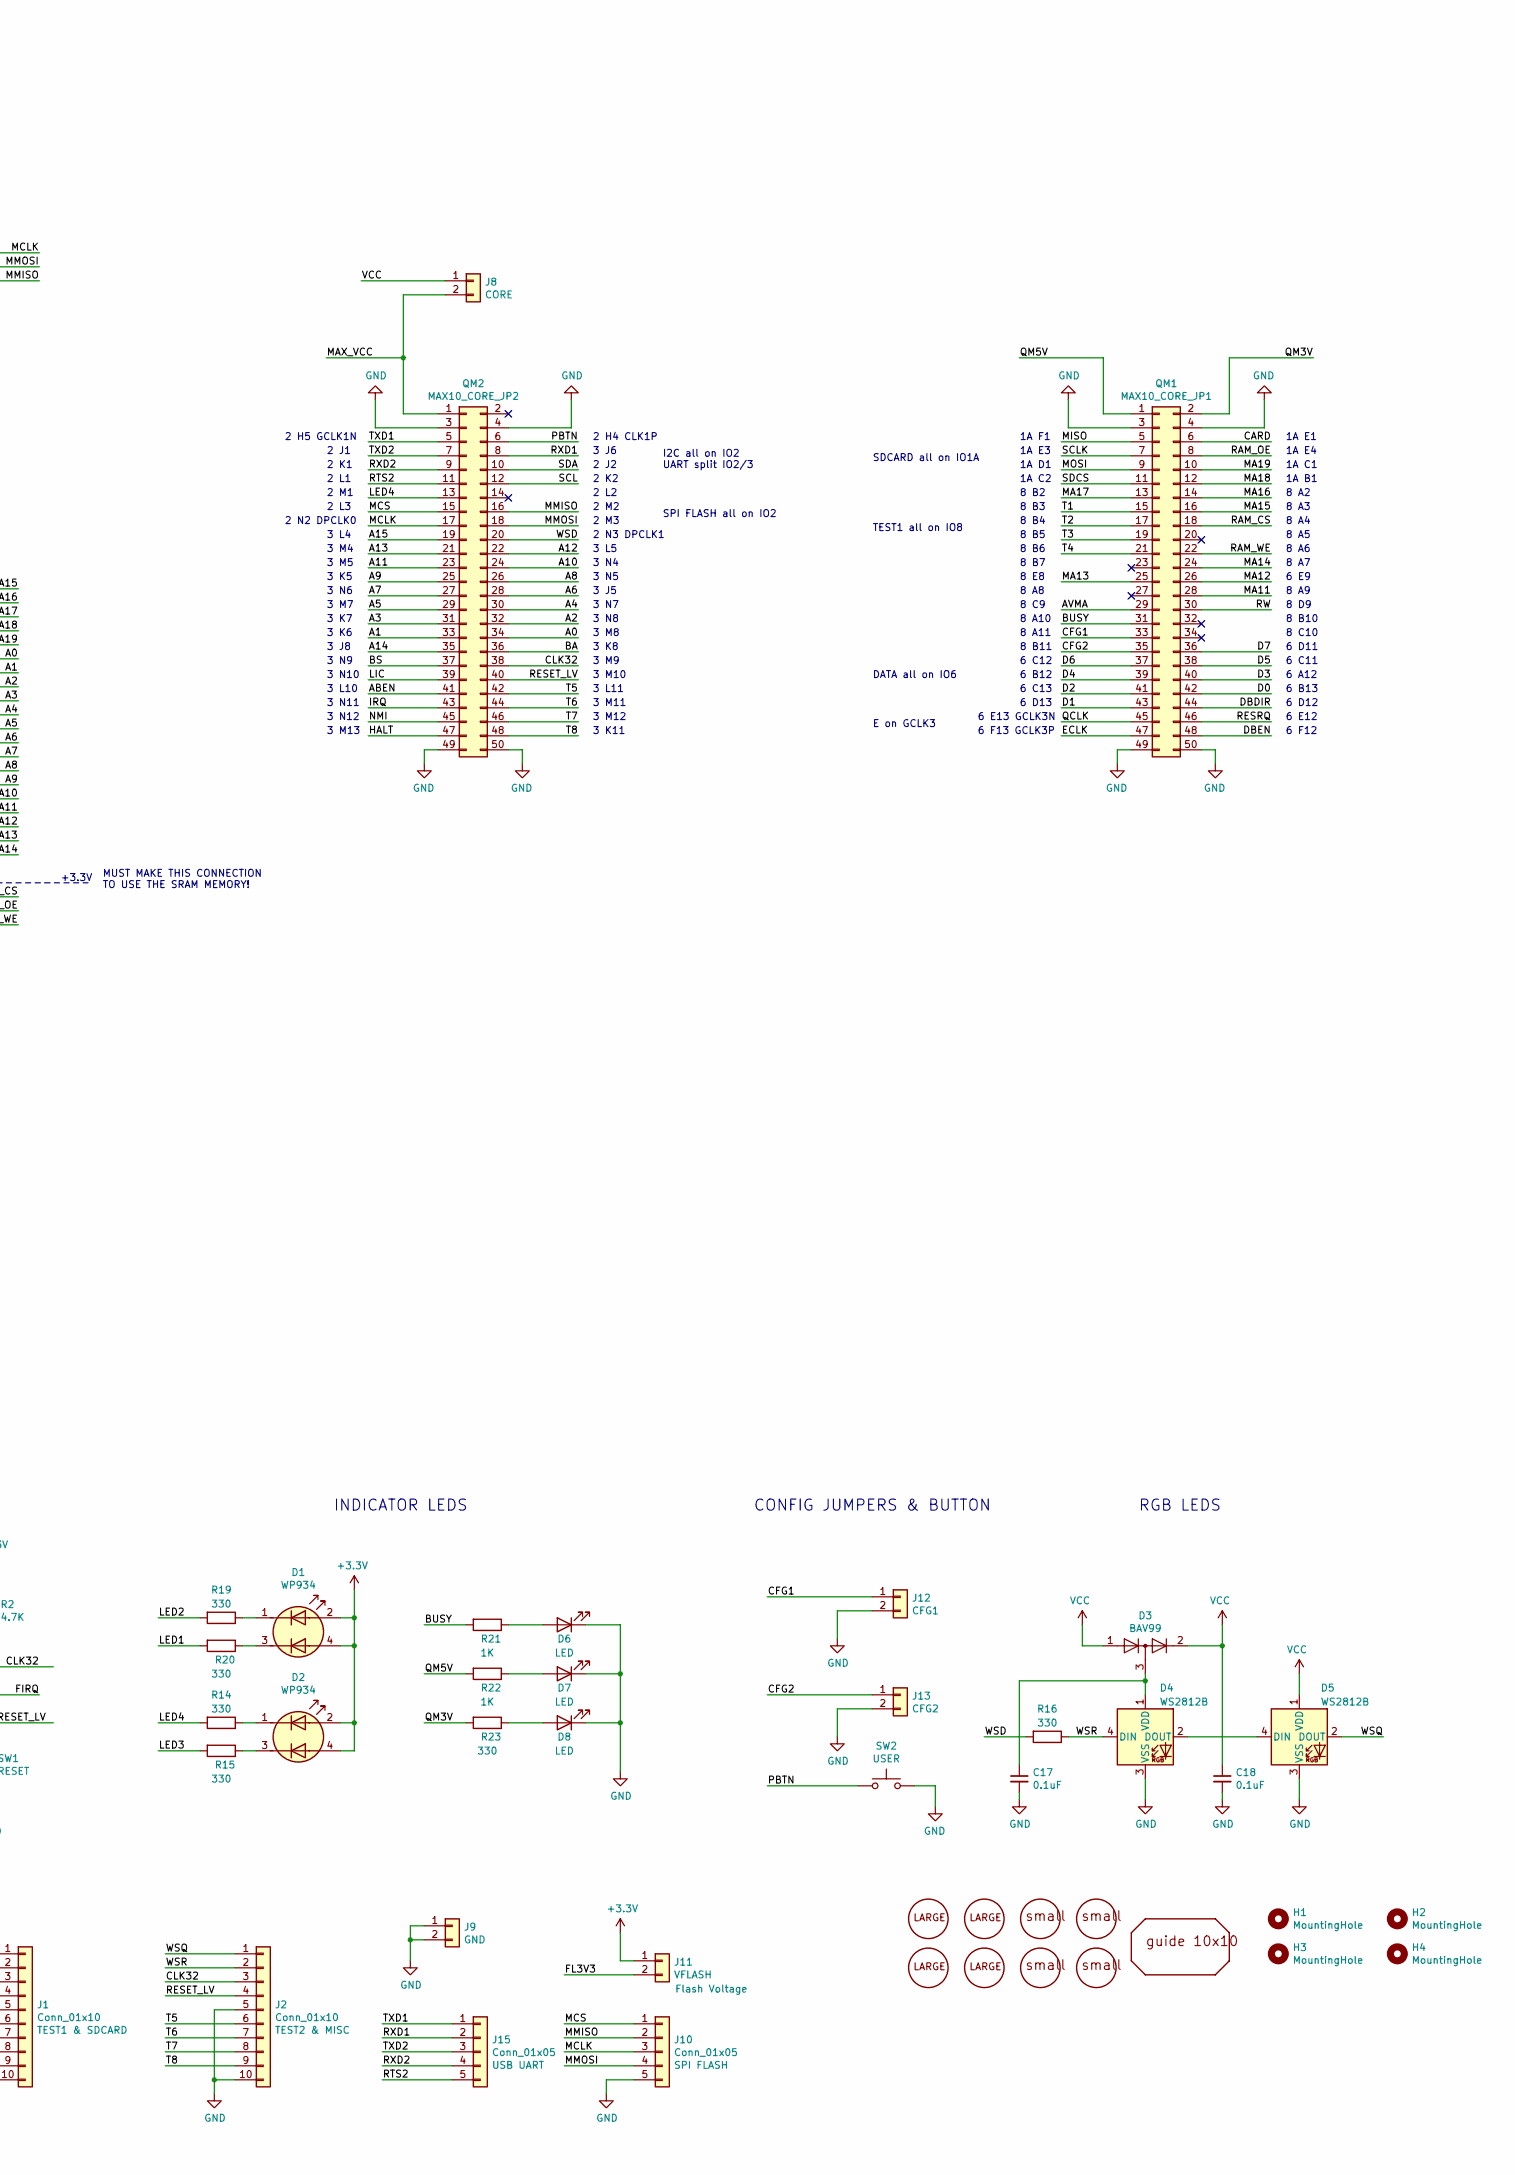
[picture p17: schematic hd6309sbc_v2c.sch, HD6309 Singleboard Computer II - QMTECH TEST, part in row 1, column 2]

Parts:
BT1: CR2032; BatteryHolder_Keystone_1060_1x2032; MPN Keystone 1060
C1, C2, C3, C5, C6, C11, C14, C15, C16, C17, C18, C28, C34, C35: 0.1uF; C_0805_2012Metric
C4, C9: 22uF; C_0805_2012Metric
C7: 1uF; C_0805_2012Metric
C8: 10uF; C_1210_3225Metric_Pad1.33x2.70mm_HandSolder; MPN GRM32DR61E106KA12L
C10, C32: 10uF; C_0805_2012Metric
C12, C13, C30: 4.7uF; C_0805_2012Metric
D1, D2: WP934; 2GD
D3: BAV99; SOT-23
D4, D5: WS2812B; LED_WS2812B_PLCC4_5.0x5.0mm_P3.2mm
D6, D7, D8: LED; LED_0805_2012Metric_Pad1.15x1.40mm_HandSolder
H1, H2, H3, H4: MountingHole; MountingHole_4.3mm_M4_DIN965
J1, J2: Conn_01x10; PinHeader_1x10_P2.54mm_Vertical
J3: DC 6-16V; BarrelJack_CUI_PJ-102AH_Horizontal
J4: USB_B_Micro; USB_Micro-B_Wuerth_629105150521
J6: Micro_SD_Card_Det; microSD_HC_Hirose_DM3D-SF
J7: I2C; PinHeader_1x04_P2.54mm_Vertical
J8: CORE; PinHeader_1x02_P2.54mm_Vertical
J9: GND; PinHeader_1x02_P2.54mm_Vertical
J10, J15: Conn_01x05; PinHeader_1x05_P2.54mm_Vertical
J11: VFLASH; PinHeader_1x02_P2.54mm_Vertical
J12: CFG1; PinHeader_1x02_P2.54mm_Vertical
J13: CFG2; PinHeader_1x02_P2.54mm_Vertical
JP3: PWR_SEL; PinHeader_1x03_P2.54mm_Vertical
L1: 3.3uH; L_Wuerth_HCI-7040
Q1: BSS138; SOT-23
QM1: MAX10_CORE_JP1; PinHeader_2x25_P2.54mm_Vertical
QM2: MAX10_CORE_JP2; PinHeader_2x25_P2.54mm_Vertical
R1, R2, R3, R5, R8, R9, R10, R11, R17, R18, R26: 4.7K; R_0805_2012Metric
R4, R6: 10K; R_0805_2012Metric
R7, R13: 47K; R_0805_2012Metric
R12: 22K; R_0805_2012Metric
R14, R15, R16, R19, R20, R23: 330; R_0805_2012Metric
R21, R22: 1K; R_0805_2012Metric
R28: 47; R_0805_2012Metric
RG1: GUIDE_10X10; BOARD_10X10
RL1, RL2, RL3, RL4: PIN_LARGE_SINGLE_DEVICE; PIN_LARGE_SINGLE
RS1, RS2, RS3, RS4: PIN_SMALL_SINGLE_DEVICE; PIN_SMALL_SINGLE
SW1: RESET; SW_Tactile_SPST_Angled_PTS645Vx58-2LFS
SW2: USER; SW_Tactile_SPST_Angled_PTS645Vx58-2LFS
TP1: RESET; TestPoint_THTPad_2.0x2.0mm_Drill1.0mm
TP2: FIRQ; TestPoint_THTPad_2.0x2.0mm_Drill1.0mm
TP3: VCP; TestPoint_Pad_D1.5mm
TP4: VBAT; TestPoint_Pad_D1.5mm
TP7: HALT; TestPoint_THTPad_2.0x2.0mm_Drill1.0mm
TP8: RESRQ; TestPoint_THTPad_2.0x2.0mm_Drill1.0mm
TP11: NMI; TestPoint_THTPad_2.0x2.0mm_Drill1.0mm
TP12: E; TestPoint_THTPad_2.0x2.0mm_Drill1.0mm
TP13: Q; TestPoint_THTPad_2.0x2.0mm_Drill1.0mm
TP14: IRQ; TestPoint_THTPad_2.0x2.0mm_Drill1.0mm
TP15: 5V; TestPoint_THTPad_2.0x2.0mm_Drill1.0mm
U1: HD63C09ECP; PLCC-44
U2: CY62158EV30LL-45ZSXI; TSOP-II-44_10.16x18.41mm_P0.8mm
U3: M95512; SOIC-8_3.9x4.9mm_P1.27mm
U4, U9, U10, U11: 74LVC245A; TSSOP-20_4.4x6.5mm_P0.65mm
U5: AP62150WU-7; SOT-23-6
U7: AMS1117-3.3; SOT-223-3_TabPin2
U8: CP2105; QFN-24-1EP_4x4mm_P0.5mm_EP2.6x2.6mm
U12: DS3231MZ; SO-8_3.9x4.9mm_P1.27mm
U14: 24LC256; SO-8_3.9x4.9mm_P1.27mm

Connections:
+3V3: C2.1, C3.1, C5.1, C7.1, C14.1, C15.1, C16.1, C32.1, C34.1, C35.1, D1.2 (K1), D1.4 (K2), D2.2 (K1), D2.4 (K2), J6.4 (VDD), J7.1, J11.1, R1.1, R2.1, R4.1, R9.1, R17.1, R18.1, R26.1, U2.11 (VDD), U2.33 (VDD), U4.20 (VCC), U7.2 (VO), U9.13 (B5), U9.17 (B1), U9.18 (B0), U9.20 (VCC), U10.20 (VCC), U11.20 (VCC), U12.2 (VCC), U14.1 (A0), U14.8 (VCC)
/A0: QM2.34, U2.44 (A5), U4.4 (A2)
/A0_HV: U1.9 (A0), U4.16 (B2)
/A1: QM2.33, U2.43 (A6), U4.5 (A3)
/A1_HV: U1.10 (A1), U4.15 (B3)
/A2: QM2.32, U2.42 (A7), U4.6 (A4)
/A2_HV: U1.11 (A2), U4.14 (B4)
/A3: QM2.31, U2.39 (A8), U4.7 (A5)
/A3_HV: U1.12 (A3), U4.13 (B5)
/A4: QM2.30, U2.28 (A9), U4.8 (A6)
/A4_HV: U1.13 (A4), U4.12 (B6)
/A5: QM2.29, U2.27 (A10), U4.9 (A7)
/A5_HV: U1.14 (A5), U4.11 (B7)
/A6: QM2.28, U2.26 (A11), U11.2 (A0)
/A6_HV: U1.15 (A6), U11.18 (B0)
/A7: QM2.27, U2.25 (A12), U11.3 (A1)
/A7_HV: U1.16 (A7), U11.17 (B1)
/A8: QM2.26, U2.24 (A13), U11.4 (A2)
/A8_HV: U1.17 (A8), U11.16 (B2)
/A9: QM2.25, U2.23 (A14), U11.5 (A3)
/A9_HV: U1.19 (A9), U11.15 (B3)
/A10: QM2.24, U2.22 (A15), U11.6 (A4)
/A10_HV: U1.20 (A10), U11.14 (B4)
/A11: QM2.23, U11.7 (A5)
/A11_HV: U1.21 (A11), U11.13 (B5)
/A12: QM2.22, U11.8 (A6)
/A12_HV: U1.22 (A12), U11.12 (B6)
/A13: QM2.21, U11.9 (A7)
/A13_HV: U1.24 (A13), U11.11 (B7)
/A14: QM2.35, U9.4 (A2)
/A14_HV: U1.25 (A14), U9.16 (B2)
/A15: QM2.19, U9.5 (A3)
/A15_HV: U1.26 (A15), U9.15 (B3)
/ABEN: QM2.41, U4.19 (OE), U11.19 (OE)
/AVMA: QM1.29, U9.8 (A6)
/AVMA_HV: U1.40 (AVMA), U9.12 (B6)
/BA: QM2.36, U4.3 (A1)
/BA_HV: U1.7 (BA), U4.17 (B1)
/BS: QM2.37, U4.2 (A0)
/BS_HV: U1.6 (BS), U4.18 (B0)
/BUSY: QM1.31, R21.2
/CARD: J6.10 (DET_A), QM1.6, R9.2
/CFG1: J12.1, QM1.33
/CFG2: J13.1, QM1.35
/CLK32: J2.3, QM2.38, R1.2, U12.1 (32KHZ)
/D0: QM1.42, U2.14 (I/O3), U10.9 (A7)
/D0_HV: U1.35 (D0), U10.11 (B7)
/D1: QM1.43, U2.13 (I/O2), U10.8 (A6)
/D1_HV: U1.34 (D1), U10.12 (B6)
/D2: QM1.41, U2.10 (I/O1), U10.7 (A5)
/D2_HV: U1.33 (D2), U10.13 (B5)
/D3: QM1.40, U2.9 (I/O0), U10.6 (A4)
/D3_HV: U1.32 (D3), U10.14 (B4)
/D4: QM1.39, U2.36 (I/O7), U10.5 (A3)
/D4_HV: U1.31 (D4), U10.15 (B3)
/D5: QM1.38, U2.35 (I/O6), U10.4 (A2)
/D5_HV: U1.30 (D5), U10.16 (B2)
/D6: QM1.37, U2.32 (I/O5), U10.3 (A1)
/D6_HV: U1.29 (D6), U10.17 (B1)
/D7: QM1.36, U2.31 (I/O4), U10.2 (A0)
/D7_HV: U1.27 (D7), U10.18 (B0)
/DBDIR: QM1.44, U10.1 (DIR)
/DBEN: QM1.48, U10.19 (OE)
/ECLK: QM1.47, TP12.1, U1.38 (E)
/FIRQ: R2.2, TP2.1, U1.5 (~FIRQ), U12.3 (~INT~/SQW)
/FL3V3: C1.1, J11.2, R5.1, R11.1, U3.8 (VCC)
/HALT: QM2.47, TP7.1, U1.44 (~HALT)
/IRQ: QM2.43, TP14.1, U1.4 (~IRQ)
/LED1: R20.2, U8.24 (GPIO.0_SCI)
/LED2: R19.2, U8.23 (GPIO.1_SCI)
/LED3: R15.2, U8.15 (GPIO.0_ECI)
/LED4: QM2.13, R14.2
/LIC: QM2.39, U9.6 (A4)
/LIC_HV: U1.42 (LIC), U9.14 (B4)
/MA11: QM1.28, U2.21 (A16)
/MA12: QM1.26, U2.20 (A17)
/MA13: QM1.25, U2.19 (A18)
/MA14: QM1.24, U2.18 (A19)
/MA15: QM1.16, U2.5 (A0)
/MA16: QM1.14, U2.4 (A1)
/MA17: QM1.13, U2.3 (A2)
/MA18: QM1.12, U2.2 (A3)
/MA19: QM1.10, U2.1 (A4)
/MAX_VCC: J8.2, QM2.1
/MCLK: J10.3, QM2.17, U3.6 (C)
/MCS: J10.1, QM2.15, U3.1 (~S)
/MHLD: R11.2, U3.7 (~HOLD)
/MISO: J1.2, J6.7 (DAT0), QM1.5, R26.2
/MMISO: J10.2, QM2.16, U3.2 (Q)
/MMOSI: J10.4, QM2.18, U3.5 (D)
/MOSI: J1.4, J6.3 (CMD), QM1.9
/MWP: R5.2, U3.3 (~W)
/NMI: QM2.45, TP11.1, U1.3 (~NMI)
/PBTN: QM2.6, SW2.1
/QCLK: QM1.45, TP13.1, U1.39 (Q)
/QM3V: QM1.2, R23.2
/QM5V: QM1.1, R22.2
/RAM_CS: QM1.18, U2.6 (~CE1)
/RAM_OE: QM1.8, U2.41 (~OE)
/RAM_WE: QM1.22, U2.17 (~WE)
/RESET_HV: Q1.3 (D), R3.2, TP1.1, U1.41 (~RESET)
/RESET_LV: J2.4, QM2.40, SW1.2, U12.4 (~RST)
/RESRQ: Q1.1 (G), QM1.46, R4.2, TP8.1
/RTS2: J15.5, QM2.11, U8.11 (RTS_ECI)
/RW: QM1.30, U9.9 (A7)
/RW_HV: U1.36 (R/~W), U9.11 (B7)
/RXD1: J15.2, QM2.8, U8.20 (RXD_SCI)
/RXD2: J15.4, QM2.9, U8.12 (RXD_ECI)
/SCL: J7.3, QM2.12, R18.2, U12.8 (SCL), U14.6 (SCL)
/SCLK: J1.3, J6.5 (CLK), QM1.7
/SDA: J7.2, QM2.10, R17.2, U12.7 (SDA), U14.5 (SDA)
/SDCS: J1.5, J6.2 (DAT3/CD), QM1.11
/T1: J1.7, QM1.15
/T2: J1.8, QM1.17
/T3: J1.9, QM1.19
/T4: J1.10, QM1.21
/T5: J2.6, QM2.42
/T6: J2.7, QM2.44
/T7: J2.8, QM2.46
/T8: J2.9, QM2.48
/TXD1: J15.1, QM2.5, U8.21 (TXD_SCI)
/TXD2: J15.3, QM2.7, U8.13 (TXD_ECI)
/VCP: C12.1, R10.1, TP3.1, U8.5 (VIO), U8.6 (VDD)
/VREG: C9.1, JP3.3 (B), L1.2, R8.1
/VUSB: C11.1, J4.1 (VBUS), JP3.1 (A), R12.1
/WSD: QM2.20, R16.2
/WSQ: D5.2 (DOUT), J2.1
/WSR: D4.4 (DIN), J2.2, R16.1
GND: BT1.2 (-), C1.2, C2.2, C3.2, C4.2, C5.2, C7.2, C8.2, C9.2, C10.2, C11.2, C12.2, C13.2, C14.2, C15.2, C16.2, C17.2, C18.2, C30.2, C32.2, C34.2, C35.2, D4.3 (VSS), D5.3 (VSS), D6.1 (K), D7.1 (K), D8.1 (K), J1.1, J1.6, J2.5, J2.10, J3.2, J4.5 (GND), J6.6 (VSS), J6.9 (DET_B), J6.11 (SHIELD), J7.4, J9.1, J9.2, J10.5, J12.2, J13.2, Q1.2 (S), QM1.3, QM1.4, QM1.49, QM1.50, QM2.3, QM2.4, QM2.49, QM2.50, R6.2, R13.2, R28.2, SW1.1, SW2.2, U1.1 (VSS), U1.2 (VSS), U1.43 (TSC), U2.12 (GND), U2.34 (GND), U3.4 (VSS), U4.1 (DIR), U4.10 (GND), U5.1 (GND), U7.1 (GND), U8.2 (GND), U8.25 (GND), U9.1 (DIR), U9.10 (GND), U9.19 (OE), U10.10 (GND), U11.1 (DIR), U11.10 (GND), U12.5 (GND), U14.2 (A1), U14.3 (A2), U14.4 (GND), U14.7 (WP)
unnamed: BT1.1 (+), C30.1, TP4.1, U12.6 (VBAT)
unnamed: C6.1, U5.6 (VBST)
unnamed: C6.2, L1.1, U5.2 (SW)
unnamed: C8.1, J3.1, U5.3 (VIN), U5.5 (EN)
unnamed: C13.1, U8.16 (VPP/DCD)
unnamed: C17.1, D3.3 (K), D4.1 (VDD)
unnamed: C28.1, J4.6 (Shield)
unnamed: C28.2, R28.1
unnamed: D1.1 (A1), R19.1
unnamed: D1.3 (A2), R20.1
unnamed: D2.1 (A1), R14.1
unnamed: D2.3 (A2), R15.1
unnamed: D4.2 (DOUT), D5.4 (DIN)
unnamed: D6.2 (A), R21.1
unnamed: D7.2 (A), R22.1
unnamed: D8.2 (A), R23.1
unnamed: J4.2 (D-), U8.4 (D-)
unnamed: J4.3 (D+), U8.3 (D+)
unnamed: R6.1, R7.1, U5.4 (VFB)
unnamed: R7.2, R8.2
unnamed: R10.2, U8.9 (~RST)
unnamed: R12.2, R13.1, U8.8 (VBUS)
VCC: C4.1, C10.1, C18.1, D3.1 (K), D3.2 (A), D5.1 (VDD), J8.1, JP3.2 (C), R3.1, TP15.1, U1.8 (VCC), U7.3 (VI), U8.7 (REGIN)

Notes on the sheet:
6-16V EXTERNAL SUPPLY INPUT
3.3V REGULATOR
DUAL HIGH-SPEED USB TO UART BRIDGE
RTC ADDR: 0xD0 WRITE, 0xD1 READ
EEPROM ADDR: 0xA2 WRITE, 0xA3 READ
SPI-MODE SD CARD INTERFACE
5V TTL NODES
INDICATOR LEDS
RGB LEDS
RESRQ should be driven by CPLD, typically as NOT RESET_LV. Pullup ensures that RESET is asserted during CPLD configuration.
HD63C09E CENTRAL PROCESSING UNIT
1024KB STATIC RAM
BUS LEVEL TRANSLATORS
CPU RESET VIH is 4VDC
RESET GENERATION
B to A
L : B to A H : A to B
64KB SPI FLASH
1A F1
1A E3
1A D1
1A C2
8 B2
8 B3
8 B4
8 B5
8 B6
8 E8
8 C9
8 A10
8 A11
8 B11
6 C12
8 A8
6 B12
6 C13
6 F13 GCLK3P
6 E13 GCLK3N
6 E12
6 F12

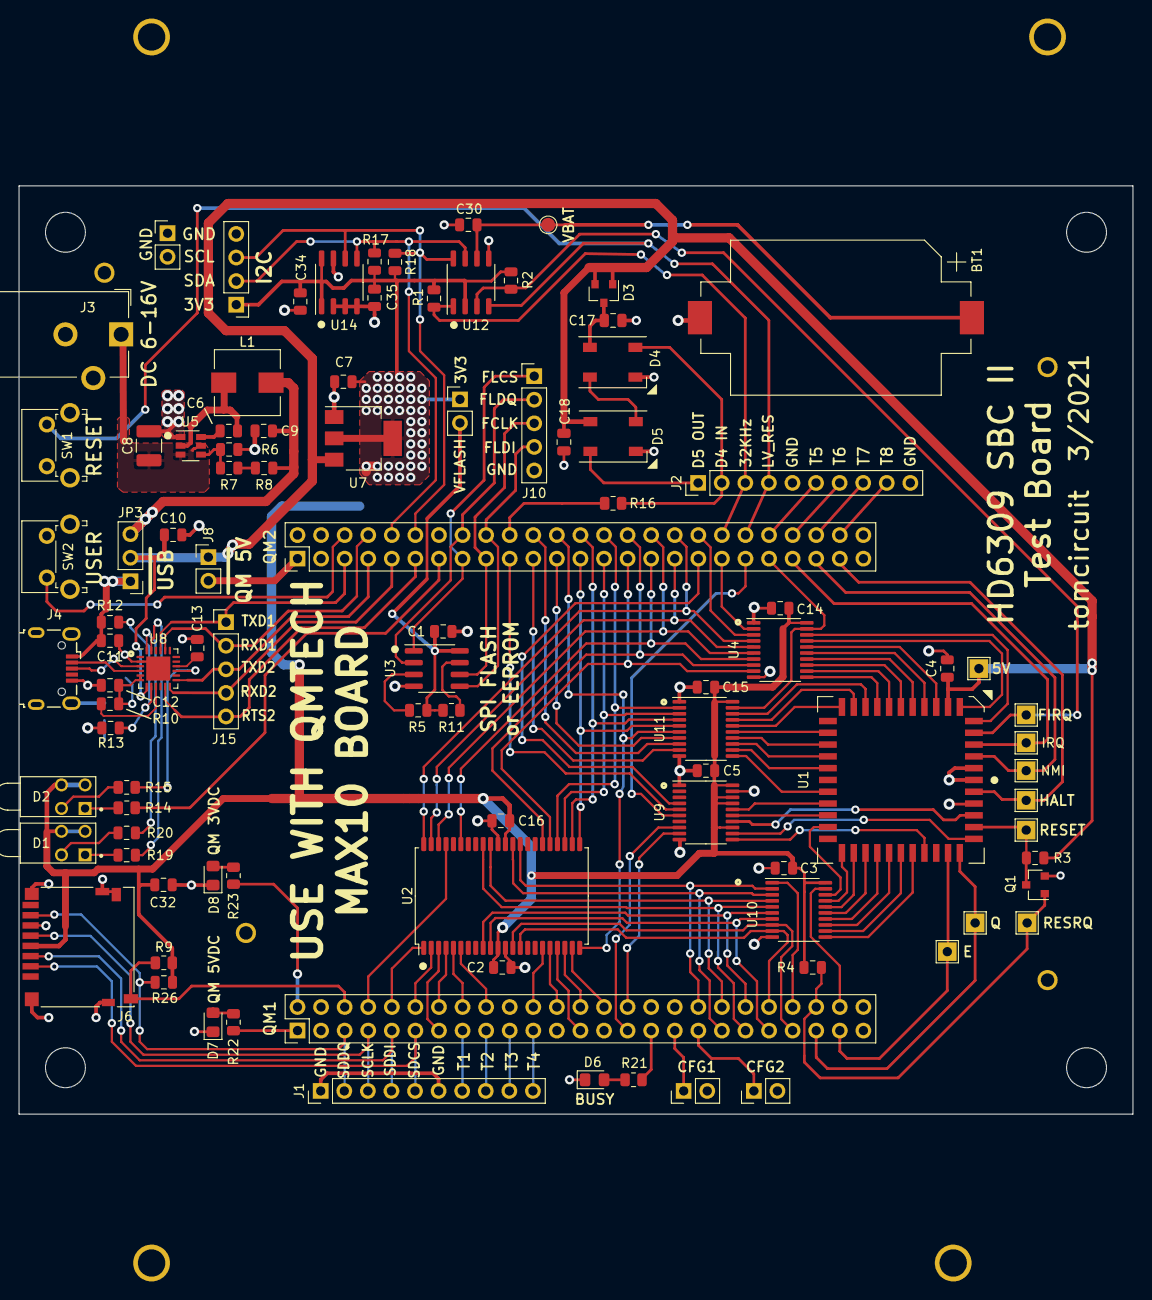
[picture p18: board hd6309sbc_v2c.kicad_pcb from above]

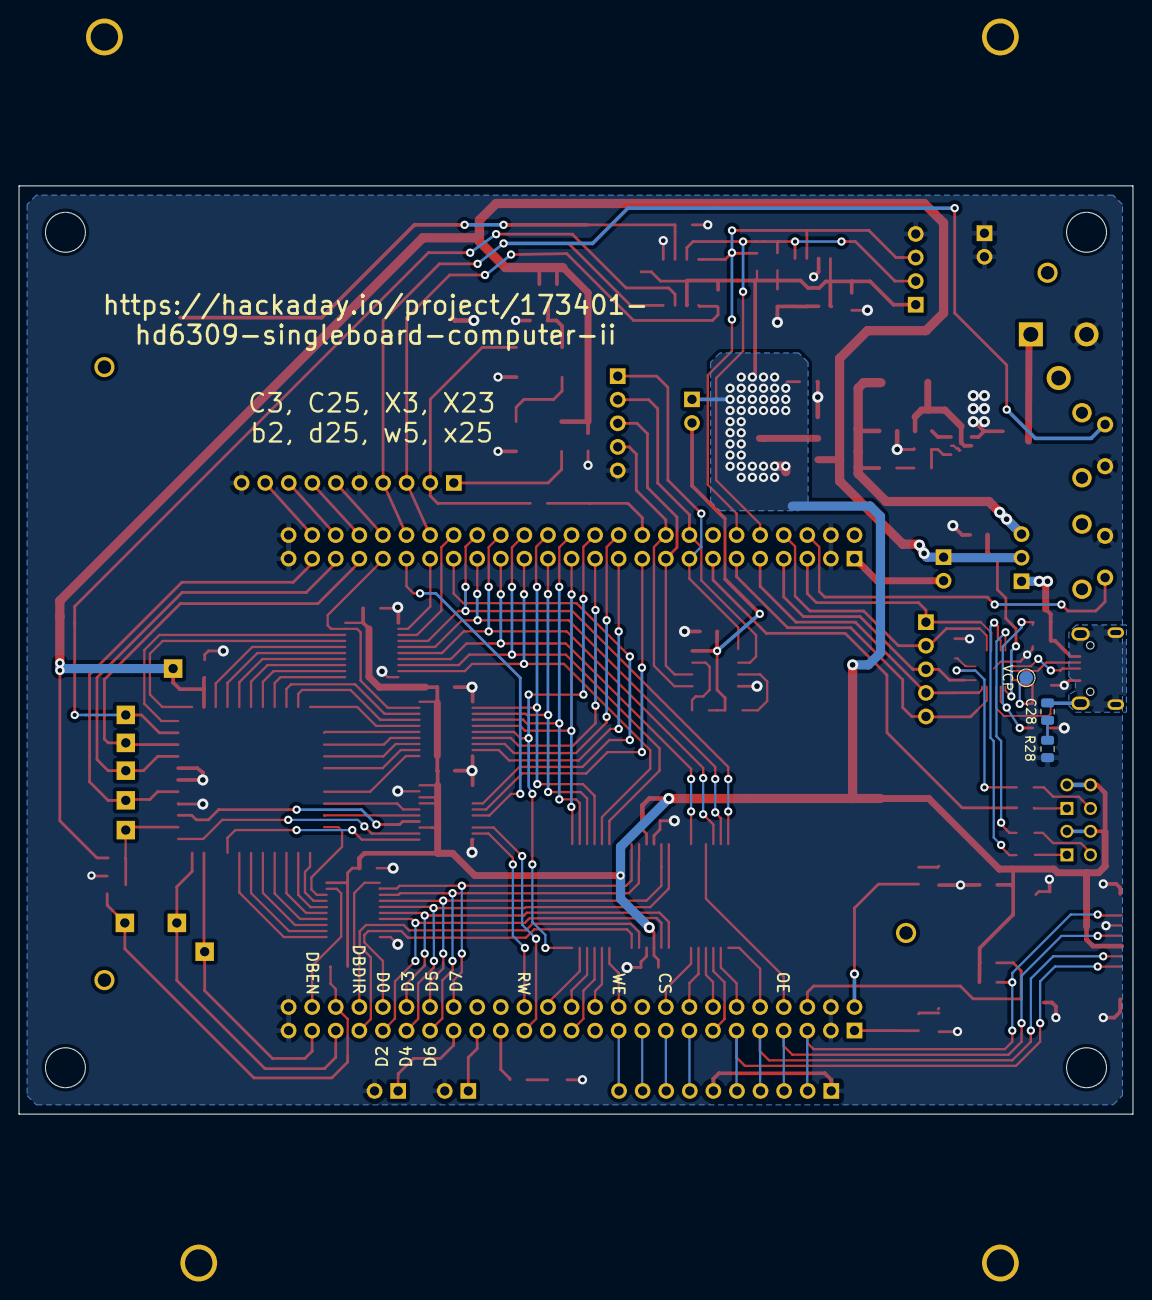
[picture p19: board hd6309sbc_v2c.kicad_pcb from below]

Board: 2 copper layers, 120.0 x 100.0 mm, 113 parts (3 on the bottom side), 152 nets.

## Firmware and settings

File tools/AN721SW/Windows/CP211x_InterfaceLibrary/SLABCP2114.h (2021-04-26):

/////////////////////////////////////////////////////////////////////////////
// SLABCP2114.h
// For SLABHIDtoUART.dll
// and Silicon Labs CP2114 HID to UART
/////////////////////////////////////////////////////////////////////////////
#ifndef SLAB_CP2114_H
#define SLAB_CP2114_H

/////////////////////////////////////////////////////////////////////////////
// Includes
/////////////////////////////////////////////////////////////////////////////

#include "SLABHIDtoUART.h"
#include "CP2114_Common.h"

/////////////////////////////////////////////////////////////////////////////
// Return Code Definitions
/////////////////////////////////////////////////////////////////////////////

// Errors associated with Config
#define HID_UART_INVALID_CONFIG_NUMBER              kInvalidConfigNumber        // Requested config number >= MAX_CONFIGS
#define HID_UART_BOOT_INDEXES_DEPLETED              kBootIndicesDepleted        // All boot indices have been used
#define HID_UART_REQUESTED_CONFIG_NOT_PRESENT       kRequestedConfigNotPresent  // Pointer to requested config is 0xFFFF
#define HID_UART_CONFIG_INVALID                     kRequestedConfigInvalid     // Specified config consists of invalid parameters
#define HID_UART_CONFIG_POINTERS_DEPLETED           kConfigPointersDepleted     // All Config pointer slots have been used
#define HID_UART_CONFIG_SPACE_DEPLETED              kConfigSpaceDepleted        // Not enough space to save the new config
#define HID_UART_BOOT_INDEX_UNCHANGED               kBootIndexUnchanged         // The user-specified boot index is already the current boot index
#define HID_UART_CONFIG_UNCHANGED                   kConfigUnchanged            // The Config is already as the user requested
#define HID_UART_INVALID_CONFIG_SEQUENCE_IDENTIFIER kConfigInvalidConfigIdentifier  // Invalid Config string ID
#define HID_UART_INVALID_CONFIG_SETTINGS            kConfigSettingsInvalid      // Configuration contains invalid setting(s)
#define HID_UART_UNSUPPORTED_CONFIG_FORMAT          kUnsupportedConfigFormat    // The config format version is not supported by library/firmware

// 'Set Parameters for Next Get' errors
#define HID_UART_INVALID_NUMBER_OF_CACHED_PARAMS    kInvalidNumberOfCachedParams// Specified tSetParamsForNextGet.params > MAX_CACHED_PARAMS
#define HID_UART_UNEXPECTED_CACHE_DATA              kUnexpectedCacheData        // Something in tSetParamsForNextGet was not as expected

// I2C Errors
#define HID_UART_I2C_BUSY                           kI2cBusy                    // I2C bus is busy
#define HID_UART_I2C_TIMEOUT                        kI2cTimeout                 // Timeout waiting for I2C event (start, ACK, etc.)
#define HID_UART_I2C_INVALID_TOKEN                  kI2cInvalidToken            // I2C interpreter detected invalid token
#define HID_UART_I2C_INVALID_WRITE_LENGTH           kI2cInvalidWriteLength      // Specified number of bytes to write is 0 or too large
#define HID_UART_I2C_INVALID_CONFIG_LENGTH          kI2cInvalidConfigLength     // Specified configuration length is invalid
#define HID_UART_I2C_SCL_STUCK_LOW                  kI2cSclStuckLow             // SCL line is stuck low
#define HID_UART_I2C_SDA_STUCK_LOW                  kI2cSdaStuckLow             // SDA line is stuck low


/////////////////////////////////////////////////////////////////////////////
// Pin Definitions
/////////////////////////////////////////////////////////////////////////////

// Pin Config Mode Array Indices
#define CP2114_INDEX_GPIO_0                         0
#define CP2114_INDEX_GPIO_1                         1
#define CP2114_INDEX_GPIO_2                         2
#define CP2114_INDEX_GPIO_3                         3
#define CP2114_INDEX_GPIO_4                         4
#define CP2114_INDEX_GPIO_5                         5
#define CP2114_INDEX_GPIO_6                         6
#define CP2114_INDEX_GPIO_7                         7
#define CP2114_INDEX_GPIO_8                         8
#define CP2114_INDEX_GPIO_9                         9
#define CP2114_INDEX_TX                             10
#define CP2114_INDEX_RX                             11
#define CP2114_INDEX_SUSPEND                        12
#define CP2114_INDEX_SUSPEND_BAR                    13
// Size of the above array pointed to by pinConfig parameter in CP2114_SetPinConfig and CP2114_GetPinConfig
#define CP2114_PIN_CONFIG_SIZE                      14

// Pin Bitmasks
#define CP2114_MASK_GPIO_0                          0x0001
#define CP2114_MASK_GPIO_1                          0x0002
#define CP2114_MASK_GPIO_2                          0x0004
#define CP2114_MASK_GPIO_3                          0x0008
#define CP2114_MASK_GPIO_4                          0x0010
#define CP2114_MASK_GPIO_5                          0x0020
#define CP2114_MASK_GPIO_6                          0x0040
#define CP2114_MASK_GPIO_7                          0x0080
#define CP2114_MASK_GPIO_8                          0x0100
#define CP2114_MASK_GPIO_9                          0x0200
#define CP2114_MASK_TX                              0x0400
#define CP2114_MASK_RX                              0x0800
#define CP2114_MASK_SUSPEND                         0x1000
#define CP2114_MASK_SUSPEND_BAR                     0x2000

/////////////////////////////////////////////////////////////////////////////
// DAC Definitions
/////////////////////////////////////////////////////////////////////////////

#define MAX_DAC_CONFIG_SIZE (2*512 - sizeof(CP2114_RAM_CONFIG_STRUCT))

// 60 is the largest common multiple of 2, 3 and 4. This ensures that 
// an I2C transactions contained in the SET/GET_DAC_REGISTERS payload 
// will not be split across multiple frames.
#define DAC_REGISTERS_PAYLOAD_MAX_LEN               60

/////////////////////////////////////////////////////////////////////////////
// Typedefs
/////////////////////////////////////////////////////////////////////////////

typedef tDeviceCaps CP2114_CAPS_STRUCT, *PCP2114_CAPS_STRUCT;
typedef _RAM_CONFIG_STRUCT CP2114_RAM_CONFIG_STRUCT, *PCP2114_RAM_CONFIG_STRUCT;

/////////////////////////////////////////////////////////////////////////////
// DAC Structures
/////////////////////////////////////////////////////////////////////////////

typedef union _CP2114_OTP_CONFIG
{
    struct // if config_version == CP2114_CONFIG_VERSION_B01
    {
        BYTE RemConfig[ RAM_CONFIG_SIZE_B01];
        BYTE DacConfig[ MAX_DAC_CONFIG_SIZE];
    } CP2114_B01;
    struct // if config_version == CP2114_CONFIG_VERSION_B02
    {
        BYTE PemConfig[ RAM_CONFIG_SIZE_B02];
        BYTE DacConfig[ MAX_DAC_CONFIG_SIZE];
    } CP2114_B02;
    BYTE Other[ 0xffff]; // Max size that can be specified in 2 bytes
} CP2114_OTP_CONFIG, *PCP2114_OTP_CONFIG;

typedef struct _CP2114_OTP_CONFIG_GET
{
    U16 Length;
    CP2114_OTP_CONFIG OtpConfig;
} CP2114_OTP_CONFIG_GET, *PCP2114_OTP_CONFIG_GET;
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

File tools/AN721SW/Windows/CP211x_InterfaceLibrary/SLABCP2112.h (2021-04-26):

/////////////////////////////////////////////////////////////////////////////
// SLABCP2112.h
// For SLABHIDtoSMBus.dll version 1.4
// and Silicon Labs CP2112 HID to SMBus
/////////////////////////////////////////////////////////////////////////////
#ifndef SLAB_CP2112_H
#define SLAB_CP2112_H

/////////////////////////////////////////////////////////////////////////////
// Includes
/////////////////////////////////////////////////////////////////////////////

#include "Types.h"

/////////////////////////////////////////////////////////////////////////////
// Tool-chain-dependent hacks
/////////////////////////////////////////////////////////////////////////////
#ifdef _WIN32
// The following ifdef block is the standard way of creating macros which make exporting 
// from a DLL simpler. All files within this DLL are compiled with the HID_TO_SMBUS_EXPORTS
// symbol defined on the command line. this symbol should not be defined on any project
// that uses this DLL. This way any other project whose source files include this file see 
// HID_TO_SMBUS_API functions as being imported from a DLL, whereas this DLL sees symbols
// defined with this macro as being exported.
#if defined(HID_TO_SMBUS_EXPORTS)
#define HID_TO_SMBUS_API __declspec(dllexport)
#else
#define HID_TO_SMBUS_API __declspec(dllimport)
#pragma comment(lib, "SLABHIDtoSMBus.lib")
#endif // defined(HID_TO_SMBUS_EXPORTS)
#else // !_WIN32
#define HID_TO_SMBUS_API
#define WINAPI
#endif // !_WIN32

// This is needed for any tool chain that doesn't have Microsoft code analysis
#if ! defined(_PREFAST_)
#if ! defined(_Use_decl_annotations_)
#define	_Use_decl_annotations_
#endif // ! defined(_Use_decl_annotations_)
#if ! defined(_Check_return_)
#define	_Check_return_
#endif // ! defined(_Check_return_)
#if ! defined(_Ret_range_)
#define _Ret_range_(lb,ub)
#endif // ! defined(_Ret_range_)
#if ! defined(_Success_)
#define	_Success_(expr)
#endif // ! defined(_Success_)
#if ! defined(_In_)
#define	_In_
#endif // ! defined(_In_)
#if ! defined(_In_opt_)
#define	_In_opt_
#endif // ! defined(_In_opt_)
#if ! defined(_Out_)
#define	_Out_
#endif // ! defined(_Out_)
#if ! defined(_In_range_)
#define _In_range_(lb,ub)
#endif // ! defined(_In_range_)
#if ! defined(_Out_range_)
#define _Out_range_(lb,ub)
#endif // ! defined(_Out_range_)
#if ! defined(_In_reads_bytes_)
#define	_In_reads_bytes_(n)
#endif // ! defined(_In_reads_bytes_)
#if ! defined(_Out_writes_bytes_)
#define	_Out_writes_bytes_(n)
#endif // ! defined(_Out_writes_bytes_)
#if ! defined(_Out_writes_bytes_opt_)
#define	_Out_writes_bytes_opt_(n)
#endif // ! defined(_Out_writes_bytes_opt_)
#if	! defined(_Printf_format_string_)
#define	_Printf_format_string_
#endif	// ! defined(_Printf_format_string_)
#endif // ! defined(_Check_return_)

/////////////////////////////////////////////////////////////////////////////
// Return Code Definitions
/////////////////////////////////////////////////////////////////////////////

// HID_SMBUS_STATUS
typedef int HID_SMBUS_STATUS;

// HID_SMBUS_STATUS Return Codes
#define HID_SMBUS_SUCCESS							0x00
#define	HID_SMBUS_DEVICE_NOT_FOUND					0x01
#define HID_SMBUS_INVALID_HANDLE					0x02
#define	HID_SMBUS_INVALID_DEVICE_OBJECT				0x03
#define	HID_SMBUS_INVALID_PARAMETER					0x04
#define	HID_SMBUS_INVALID_REQUEST_LENGTH			0x05

#define	HID_SMBUS_READ_ERROR						0x10
#define	HID_SMBUS_WRITE_ERROR						0x11
#define	HID_SMBUS_READ_TIMED_OUT					0x12
#define	HID_SMBUS_WRITE_TIMED_OUT					0x13
#define	HID_SMBUS_DEVICE_IO_FAILED					0x14
#define HID_SMBUS_DEVICE_ACCESS_ERROR				0x15
#define HID_SMBUS_DEVICE_NOT_SUPPORTED				0x16

#define HID_SMBUS_UNKNOWN_ERROR						0xFF

// HID_SMBUS_TRANSFER_S0
typedef BYTE HID_SMBUS_S0;

#define HID_SMBUS_S0_IDLE							0x00
#define HID_SMBUS_S0_BUSY							0x01
#define HID_SMBUS_S0_COMPLETE						0x02
#define HID_SMBUS_S0_ERROR							0x03

// HID_SMBUS_TRANSFER_S1
typedef BYTE HID_SMBUS_S1;

// HID_SMBUS_TRANSFER_S0 = HID_SMBUS_S0_BUSY
#define HID_SMBUS_S1_BUSY_ADDRESS_ACKED				0x00
#define HID_SMBUS_S1_BUSY_ADDRESS_NACKED			0x01
#define HID_SMBUS_S1_BUSY_READING					0x02
#define HID_SMBUS_S1_BUSY_WRITING					0x03

// HID_SMBUS_TRANSFER_S0 = HID_SMBUS_S0_ERROR
#define HID_SMBUS_S1_ERROR_TIMEOUT_NACK				0x00
#define HID_SMBUS_S1_ERROR_TIMEOUT_BUS_NOT_FREE		0x01
#define HID_SMBUS_S1_ERROR_ARB_LOST					0x02
#define HID_SMBUS_S1_ERROR_READ_INCOMPLETE			0x03
#define HID_SMBUS_S1_ERROR_WRITE_INCOMPLETE			0x04
#define HID_SMBUS_S1_ERROR_SUCCESS_AFTER_RETRY		0x05

/////////////////////////////////////////////////////////////////////////////
// String Definitions
/////////////////////////////////////////////////////////////////////////////

// Product String Types
#define HID_SMBUS_GET_VID_STR						0x01
#define HID_SMBUS_GET_PID_STR						0x02
#define HID_SMBUS_GET_PATH_STR						0x03
#define HID_SMBUS_GET_SERIAL_STR					0x04
#define HID_SMBUS_GET_MANUFACTURER_STR				0x05
#define HID_SMBUS_GET_PRODUCT_STR					0x06

// String Lengths
#define HID_SMBUS_DEVICE_STRLEN						260

// HID_SMBUS_DEVICE_STR
typedef char HID_SMBUS_DEVICE_STR[HID_SMBUS_DEVICE_STRLEN];

/////////////////////////////////////////////////////////////////////////////
// SMBUS Definitions
/////////////////////////////////////////////////////////////////////////////

// SMbus Configuration Limits
#define HID_SMBUS_MIN_BIT_RATE						1
#define HID_SMBUS_MIN_TIMEOUT						0
#define HID_SMBUS_MAX_TIMEOUT						1000
#define HID_SMBUS_MAX_RETRIES						1000
#define HID_SMBUS_MIN_ADDRESS						0x02
#define HID_SMBUS_MAX_ADDRESS						0xFE

// Read/Write Limits
#define HID_SMBUS_MIN_READ_REQUEST_SIZE				1
#define HID_SMBUS_MAX_READ_REQUEST_SIZE				512
#define HID_SMBUS_MIN_TARGET_ADDRESS_SIZE			1
#define HID_SMBUS_MAX_TARGET_ADDRESS_SIZE			16
#define HID_SMBUS_MAX_READ_RESPONSE_SIZE			61
#define HID_SMBUS_MIN_WRITE_REQUEST_SIZE			1
#define HID_SMBUS_MAX_WRITE_REQUEST_SIZE			61

/////////////////////////////////////////////////////////////////////////////
// GPIO Definitions
/////////////////////////////////////////////////////////////////////////////

// GPIO Pin Direction Bit Value
#define HID_SMBUS_DIRECTION_INPUT					0
#define HID_SMBUS_DIRECTION_OUTPUT					1

// GPIO Pin Mode Bit Value
#define HID_SMBUS_MODE_OPEN_DRAIN					0
#define HID_SMBUS_MODE_PUSH_PULL					1

// GPIO Function Bitmask
#define HID_SMBUS_MASK_FUNCTION_GPIO_7_CLK			0x01
#define HID_SMBUS_MASK_FUNCTION_GPIO_0_TXT			0x02
#define HID_SMBUS_MASK_FUNCTION_GPIO_1_RXT			0x04

// GPIO Function Bit Value
#define HID_SMBUS_GPIO_FUNCTION						0
#define HID_SMBUS_SPECIAL_FUNCTION					1

// GPIO Pin Bitmask
#define HID_SMBUS_MASK_GPIO_0						0x01
#define HID_SMBUS_MASK_GPIO_1						0x02
#define HID_SMBUS_MASK_GPIO_2						0x04
#define HID_SMBUS_MASK_GPIO_3						0x08
#define HID_SMBUS_MASK_GPIO_4						0x10
#define HID_SMBUS_MASK_GPIO_5						0x20
#define HID_SMBUS_MASK_GPIO_6						0x40
#define HID_SMBUS_MASK_GPIO_7						0x80
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

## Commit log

2020-07-10 Initial commit of HD6309 SBC II
    KiCAD database, PDF schematic, PDF PCB plots, CSV BOM, readme, license files.
    [10m04sc.xls, 10m08sc.xls, 10m16sc.xls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]
2020-07-10 3D shape paths & render files
    ...I wish I understood KiCAD better to make these paths stick...
    two render files generated - for Hackaday page
2020-07-15 updated assy plot
    moved plots and BOM files to OUTPUT folder.
    [hd6309sbc_v2.kicad_pcb, hd6309sbc_v2_bom.csv]
2021-04-26 SBC V2 testboard
    KiCad project with testboard, mates with a QMTECH MAX10 board for FPGA.
    Start of VHDL coding for toplevel (phase 0 - just the basics)
    [10m04sc.xls, 10m08sc.xls, 10m16sc.xls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]
